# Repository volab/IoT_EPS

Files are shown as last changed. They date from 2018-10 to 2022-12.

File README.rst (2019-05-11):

==============================
Informations générales IoT_EPS
==============================

:Auteur:               Le VoLab (MajorLee, Poltergeist42)
:Site_Web:             https://www.volab.org
:Projet:               IoT_EPS
:Version:              190105
:dépôt GitHub:         https://github.com/volab/IoT_EPS.git
:documentation:        
:Licence:              CC BY-NC-SA 4.0
:Liens:                https://creativecommons.org/licenses/by-nc-sa/4.0/

####

Description
==============

IoT Electronic Power Strip : Une multiprise connectée sur laquelle chaque plot est configurable.

La connections sans fil se fait selon 2 modes possibles

- le bloc de prise est un point d'accès Wifi (mode AP)
- le bloc de prise se connecte à un réseau Wifi existant (mode Client)

Pas de mode Cloud pour le moment.

####

Arborescence du projet
========================

Pour aider à la compréhension de mon organisation,voici un bref descriptif de l'arborescence de ce projet.Cette arborescence est à reproduire si vous récupérez cedépôt depuis GitHub. ::

    ProjectDir_Name        # Dossier racine du projet (non versionner)
    |
    +--project             # (Branch master) contient l'ensemble du projet en lui même
    |  |
    |  +--_1_userDoc       # Contiens toute la documentation relative au projet
    |  |   |
    |  |   \--source       # Dossier réunissant les sources utilisées par Sphinx
    |  |
    |  +--_2_modelisation  # Contiens tous les plans et toutes les modélisations du projet
    |  |
    |  +--_3_software      # Contiens toute la partie programmation du projet
    |  |
    |  +--_4_PCB           # Contient toutes les parties des circuits imprimés (routage,
    |  |                   # Implantation, typon, fichier de perçage, etc.)
    |  |
    |  +--_5_techDoc       # Contiens toutes les documentations techniques des différents composants
    |  |                   # ou éléments qui constituent le projet. Ces éléments sont identifiés
    |  |                   # par un liens Web dans la documentation. Ce dossier n'est pas 'poussé'
    |  |                   # dans le dépôt distant (.gitignore).
    |  |
    |  +--_6_research      # Regroupe toutes les recherches relatives à l'élaboration ou au
    |  |                   # développement du projet. Ces éléments sont identifiés
    |  |                   # par un liens Web dans la documentation. Ce dossier n'est pas 'poussé'
    |  |                   # dans le dépôt distant (.gitignore).
    |  |
    |  \--_7_rushes        # Contient tous les éléments qui seront potentiellement intégrés dans la
    |                      # doc ou dans le projet. Ce dossier n'est pas 'poussé' dans le dépôt 
    |                      # distant (.gitignore).
    |
    +--webDoc              # Dossier racine de la documentation qui doit être publiée
    |  |
    |  \--html             # (Branch gh-pages) C'est dans ce dossier que Sphinx va
    |                      # générer la documentation a publié sur internet
    |
    \--trash               # Se dossier sert à retirer des éléments du projet sans les
                           # supprimé réélement. Ce dossier n'est pas pris en compte par
                           # GIT ou par GitHub

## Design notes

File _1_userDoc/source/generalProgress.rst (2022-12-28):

++++++++++++++++++++++++++++++++++++++++++++++++++++++++++++++++++++++++++++++++++++++++++++++++++++
General progress of IOT Electrical Power Strip
++++++++++++++++++++++++++++++++++++++++++++++++++++++++++++++++++++++++++++++++++++++++++++++++++++

.. include:: volabid.rst

:Date: 04/2021
:last update: 28/12/2022

.. _mainTodoList:

====================================================================================================
Task list (merged todo list hard and soft : preferred order)
====================================================================================================
Don't forget the todo list of the **doxygen documentation** and **git history**:

- To build a new plug : buy plugs

Web interface work
----------------------------------------------------------------------------------------------------
- in AP mode

- in station Mode

- A big New chapter GUI design start in 08/2022 **in progress**
    - old screen
    - new design
    - design GUI in Inkscape **OK**
    - learn REACT **OK**
    - code the GUI
        - create a simulator with node.js and express.js **in progress**

Doc
----------------------------------------------------------------------------------------------------
- Create an Visual Style Guide for documentation purpose **in progress**
    - in ``projet\_1_userDoc\visualStyleGuide221228_1549.svg``
    - retrieve source of the logo : see in ``documentation/image/logo`` **OK**

- active github pages for the project
    - upload documentation on github pages
    - create page on the volab wiki

- try other time server that provide direct time zone
    - try http://worldtimeapi.org/api/timezone/Europe/Paris in json

- Create an infographic that summarize features and needs 
    - choose tool
    - choose Size
    - choose colors
- Write user manual : **1%**
- Write builder manual
    - mechanical parts
    - buy and groups components
    - oder pcb
    - ARDUINO NANO programming
        - write where to find the precious code ! from github
        - choose ARDUINO NANO old boot, set com port and download

bugs and todos
----------------------------------------------------------------------------------------------------
- Tracking bug ``untimely switching``
    - reset all counter **OK**
    - activate red and bleu cycle and manual off on yellow and green (never switch this 2 plugs) **OK**
    - a little turn in the resolution if this bug see :ref:`update plug state in every loop<refBugUntimelySwitching>`   
    - Check after long period of time if yellow and green counter stay at 0
    - prepare only 2 220V tracker for not in used plugs ( yellow and green for example) **ABORTED**
        - it is possible to connect them outside the box directly on power plugs **ABORTED**
        - group components **ABORTED**
            - list components see :ref:`here<refDetect220VPres>` **ABORTED**
        - build it **ABORTED**
        - test it **ABORTED**
        - connect to the plugs **ABORTED**
        
    - switch to a **special software git branch** **ABORTED**
        - perhaps remove some debug messages... **ABORTED**
        - add function to read the 2 surveyed analog inputs from io expander **OK**
            - test it **OK**
        - add a new survey functionality in main loop **ABORTED**
        - if this 2 plugs switch to ON **ABORTED**
            - send on serial debug ALERT message **ABORTED**
            - display this 2 plugs states variables **ABORTED**
            - display json file content **ABORTED**
    - conduct long test
        - place the 2 unused plugs in manual off states **OK**
        - place the 2 others plugs in cycle mode **OK**
            - one with 1 mn on 2 mn off : 3mn total cycle **OK**
            - the others with 4 mn on 3 mn off : 7 mn total cycle **OK**
        - record debug serial line **OK**
        - find the right serial tool to do this job **I develop it**
    - find the cause
        - possible i2c wrong command to io expander
        - io expander bug
        - json file corruption : check json file content in the logs
        - wrong data write in json file : check plug states in th logs
    - finaly i develop a tools that check serial line in Python and with tk-inter **OK**
        - 

- treat 7 BUG From Bug_ToDoLst file
    - change time zone
    - on Web Page Hebdo mode H-fin
    - wrong global table refresh
    - cfgpage / cfgsend : configuration page (see Bug_ToDOList.rst)
    - clone pause
    - untimely switching **80%**
    - Change SSID in APmode from web page

- treat 6 TODO From Bug_ToDoLst file
    - Pause display
    - minify javascripts
    - doxy HTML js
    - file names coherence

- in wifiwebinternet.rst update Web events handlers to remove unused mode like /time /edit /list **OK**

Others task
----------------------------------------------------------------------------------------------------
- complete testToBeConduted see :ref:`here<testToBeConducted>`
    - exhaustive test of hebdo mode : **95%**
- write index special page for softAP Mode with local boostrap or other light js.framework **5%**

- Minifier all files if possible of course and reduce the size of the images
    - minifier picture
    - minifier css
    - minifier html

- try gz files

- improve json file management **2 points need work**
    - write process **OK**
        - test **ok**
            - environnement conda test **ok**
            - write python script to log boot sequence to a file: in progress ``projet\_3_software\outilPythonSpecial`` **ok**
            - record some boot sequence **ok**
            - check boots sequence **ok**
    - treat todo (error rise) 
        - regen list
        - treat one by one
    - clean the code **OK**
    - comit **ok**
    - push **ok**
    - merge **ok**
    - push **ok**

- packaging study
- integration

- continue this list ;-)

.. WARNING:: To be completed
   :class: without-title

====================================================================================================
Task done (for memory)
====================================================================================================
- cache files on web browser : see :ref:`here<webBrowserCaching>` **OK**

- before regen todo list **OK**
    - 5 parameters not documented on csystem.cpp **CORRECTED**
    - count software todo 32 NECESSARY and 11 options **OK**
        - from doxy export docboock and on web docbook to txt **OK**
    - try to ordre them **OK**
        - Excel file created **OK**
        - Check if there are all uptodate rest 22 of 32 **OK**

- doxygen gen doc pb avec **REPAIRED**::

    0044-Iot_ESP_PPlug/projet/_3_software/IoT_EPS/doc/logo_alpha2_reduced.png perdu !

- UML and classes documentation 10% - web and json **ABORTED**

- two of the 6 todo From Bug_ToDoLst file **CLOSED**
    - change behavior on fatal error **CLOSED**
        - analyze :  :ref:`see sofDev.rst<newErrorHandling2022>`
        
    - oled display error **CLOSED**

- Error handling improvement (todo display low error with LED ? Which one : power led ?)
  A lot of work : change behavior on fatal error : do not sabord system but enable debug only with serial
  - switch to special branch : newErrorHandling **OK**

New pcb
----------------------------------------------------------------------------------------------------

- print schematic from easyEda site **OK**
- edit BOM **OK**
- group components **OK**
- solder components **OK**
- Programme watch dog component
    - solder a new one on adaptator board with small pin **OK**
    - programm it with avrdude commands see :ref:`here<refWatchdogProg>` **OK**
    - test it
- use ESP, watchdog and nano from old pcb **NO**
    - reprogram attiny 85 WD **OK**
        - and test it **OK**
    - reprogram new esp8266
        - upload data **OK**
    - reprogram new arduino nano **OK**
    - test it
        - I2C acces to reg(9) of nano IO expander !
        - I2C pull-up ? Probably on DS3231 board
        - I2C scan return the right adress 0X58 ! **OK**
        - try with rtc connected **OK**
            - returned add are ok **OK**
    - write a special program to test specifically communication with the nano
        - working dir  ``\_3_software\etudeDeCode\specialPcbV2\testDirectEspNano`` **OK**
        - not versionned on git, github **OK**
        - ``testDirectEspNano.ino``
- solve the usb vs main 5v power on esp8266 **OK**
    - search and eval shottky diode solution (1N5820 has a typical vf of 0.5V its to high) SS26 Solution **OK**
    - aop and mos solution **ABORTED**
        - from the arduino model
            - list component : LM358, FDN340P, 2x 10k
            - buy or find components
                - LM358 **OK** Mouser cde **OK**
                - FDN340P : MOSFET canal P 20V 2A SOT23 cdés sur AliExp arrivée prévue **OK**
                    - store near the prototype on 13/02/2022 **OK**
                - 2x 10k ok
            - group and store components
            - prototype it **OK**
                - define the solution veroboard/pcb/cnc machining **OK**
                - solder components **OK**
                - prepare the test **OK**
                - conduct the test **OK**
            - IF it is the choosen solution add it to the schematic

- replace relais by MOSFET on general power relay to switch them all in one time on power off **OK**                                                                                              
    - choose components (irf530 and irf9530, 2x 10k resistor see personal notes public ``hardware/analog``) **OK**
        - IRF9530 : ok buy to Mouser on 21 june  **OK**
        - but no irf530 test with 2N7000  **OK**
        - 2N7000 in SOT-23 to buy from RS **OK**
            -  due to the end test and verification ther is no need but already asked from Radiospares **OK**
    - buy or find the components **OK**
        - buy 2N7000 from RS in sot23 package **OK**
    - store components in safe place : a box  **OK**
    - prototype this solution see :ref:`here<refRelayMainPowerSwitch>`  **OK**
        - cut vero board **OK**
        - solder components **OK**
        - prepare test **OK**
        - conduct the test **OK**
    - integrate the solution into the plugs **OK**
    - test it **OK**

- new pcb **OK**

    - in the schematics **OK**
        - add above solutions **OK**
            - SS26 **OK**
            - FDN30P **OK**
        - replace through hole component by cms version every time it's possible **OK**
            - Q1 to Q4 2N7000 in SOT-23 **OK**
            - R1 to R12 in R0805 **OK**
            - move R5 to R8 on hot wire to reduce pin count **OK**
            - J1 remove 6 pins **OK**
            - P5 LED remove 3 pins **OK**
        - don't forget to switch D4 and D3 on U1 **OK**
        - rtc connector reduce 2 pin **OK**
        - group wifi led and power led on same connector and place R on signal and a common gnd **OK**
  
    - On the place and route stage **OK**
        - brainstorm connector solutions: reduce the number of pins and best placement **OK**
            - no connector near the lower edge of the board (minimum distance 10mm) **OK**
            - no connector near the upper edge of the board (minimum 8mm min) **OK**
            - prefered position for connector on right edge **OK**
            - at left edge no connector and no other hight components below main switch (on a 16mm 
              place of the pcb) **OK**
            - rtc connector on upper right **OK**
            - P7 mainpowswitch connector : on left side **OK**
            - P6 special PB : on upper side **OK**
            - J1 relays commands connector : on right side **OK**
            - perhaps turn right side connector in horizontal position **NO**
            - keep ARDUINO and ESP @ same place.  **OK**
            - no hight component near the edges of the PCB **OK**
            - double check the size of the footprint of SS26 **OK**
            - check the size of the footprint of FDN340P Q5 **OK**
            - check pinout of FDN340P **OK**
            - check footprint of the 2N7002 same size as Q5 **OK**
            - One unrouted 5V on 5V Transistor corrected **OK**

    - reroute pcb to reduce the size **OK**

- test it **OK**
    - P2 : 5V power **OK**
    - Screen oled **OK**
    - DS3231 RTC **OK**
    - watch dog **OK**
    - WIFI connection **OK**
    - not tested : led and bp and relay cde... **OK**
- integrate in the plug **OK**
    - question a new plug or the old one adapted ? old not enought time for a new plug **OK**
    - make modification to pass from old pcb to new pcb **OK**
        - remove serial resistor with LED on the wire (hide by heat shrink tube)

Logo
----------------------------------------------------------------------------------------------------
- add the 3Dprinted or CNC crafted logo see :ref:`here<3dLogoDesign>`
    - design **OK**
    - print V2 logo004.stl **OK**
        - x130% in Chitubox **OK**
        - 6.18ml of resin 0h48 to print **OK**
    - paint **OK**
        - fill cavities with paint **OK**
        - scratch excess of paint **OK**
    - glue in place **OK**

====================================================================================================
General
====================================================================================================
03/12/2021: connexion to github impossible. Repaired ssh config with git hub. 
But with the help of tortoise git to configure **CORRECTED**

====================================================================================================
PCB equipment
====================================================================================================
Version 1 : Equipped and tested in may/2021

.. ATTENTION::

    Warning for test WD is not connected

Version 2: equiped on 18/04/2022

====================================================================================================
IHM
====================================================================================================
- Pierre's version : on special github branch (not allways updated in the dev)
- A minimal one from Pierre (a very old one)

.. index::
    pair: Documentation; UML
    pais Documentation; plantUML

====================================================================================================
UML story
====================================================================================================
Just to try it on webserver (dir : ``_1_userDoc\UML`` ) + Modelio (i did not find the 
workspace ! ): it is on modelio_wks_isolACauseDeGit in the project folder because of git

Juin 2021: UML the return: after the discovert of `Graphviz`_ and `plantUML`_ !!!

.. _`plantUML` : https://plantuml.com/fr/ 

.. _`Graphviz` : https://graphviz.org/ 

:download:`Doc plantUML<fichiersJoints/PlantUML_Language_Reference_Guide_fr.pdf>`

`Doc officelle Graphviz`_

.. _`Doc officelle Graphviz` : https://graphviz.org/documentation/

====================================================================================================
Hardware
====================================================================================================
See :ref:`Hardware pogress<hardProgress>`

====================================================================================================
software
====================================================================================================
See :ref:`Software progress page<devProgress>`

====================================================================================================
Weblinks
====================================================================================================

.. target-notes::

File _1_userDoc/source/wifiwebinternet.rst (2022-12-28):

++++++++++++++++++++++++++++++++++++++++++++++++++++++++++++++++++++++++++++++++++++++++++++++++++++
Wifi, Web and internet
++++++++++++++++++++++++++++++++++++++++++++++++++++++++++++++++++++++++++++++++++++++++++++++++++++

:Auteur: J.Soranzo
:Date: Ocotbre 2020
:update: 17/08/2022
:Societe: VoRoBoTics
:Entity: VoLAB

.. toctree::
    :maxdepth: 2
    :caption: Sub content
    :titlesonly:

    interface_Web

.. contents::
    :backlinks: top

====================================================================================================
Web events handlers
====================================================================================================

.. graphviz:: graphviz/webEvents.gv

----------------------------------------------------------------------------------------------------

.. index:: 
   single: Wifi modes

.. _refWifiModes:

==================
WIFI Modes
==================

In Json config file, it is configured with: "startInAPMode" value,

No WiFi
----------------------------------------------------------------------------------------------------
Also called simpleManualMode

When power on the powerStrip (by the wall plug not by the power switch), maintain push button of redPlug

Power strip start in this mode independently of Json configured mode.

4 Big color LED flash 20 times in purple.

In this very simple poor mode, powerstrip works only in manual mode with BP actions ON/OFF.

SoftAP
----------------------------------------------------------------------------------------------------
EPS starts in this mode when value of "startInAPMode" parameter is "ON".

No acces to NTP server but all other functions work.

After 20 false tries of station mode, power Strip automaticly switch in this mode

Station
----------------------------------------------------------------------------------------------------
EPS starts in this mode when value of "startInAPMode" parameter is "OFF".

The best functionnal mode ! With full web interface and others functions.

both mode STA and AP
----------------------------------------------------------------------------------------------------
July 2019 : reflexion when we start in DHCP station mode we don't know IP address of the IoT EPS.
One way to know it is to use a tool to scan the local network !
So why do not connect systematically in both mode !!!
Do it in new dev branch  !!!!!!!!!!!!!!!!!! 10 months of development to achieve this !!!!

====================================
IP address
====================================
AP and non DHCP IP address are class C address (subnet mask is 255.255.255.0 hardcoded )

.. index::
    single: Wifi LEDs

==================
WIFI LED behavior
==================
In Station mode, fast flashing (30 - parametric value in config4.json -  times 100ms, 100ms) before to try connection
and after slow flashing while waiting for connection.
(500ms with a 30 times time out - new in 24/12/2018). If no connection detected after 30 (STAmaxWifiConnectionRetry parameter) tries
Automatically switch in SoftAP mode.

In Access Point LED FLash quickly (20 times 100ms-500ms) and 
led flash slowly (50ms-2s) while waiting for connection.

Cause WiFi.softAPConfig function is a blocking function. This is wrong : 
test on 24/12/2018 softAP is non blocking !

So - in summary - if power led is on and WIFI Led flash (50ms-2s) WIFI wait for connection in AP mode. 

It rises a new problem : in this state it is not possible to use plugs even in simple  manual mode 
with push button. 

Possible solution : check push button at startup if a particular combination is pressed,
plugs do not try to connect to wifi and work in simple manual mode.
In Dec 2018, push button
added pressing plug 0 while power on the strip cause no WIFI mode (color LED FLASH in RED to confirm)
This is : simpleManualMode (see above). To return to normal mode power off the strip 
(not by the power on/off button but by removing the strip from the wall plug)

===========================================
ESP8266 and its wifi management !
===========================================
ESP8266 store credentials information in FLASH but how to access to them ???
And how to control them

Question how to erase wifi flash param ?

Memory mapping is not provided. Some peace of informations
like in SPIFFS description that provide the order of memory big blocks but not their respective address.

Second question : how to directly access to flash memory ?

Perhaps with SPI lib 

https://github.com/esp8266/Arduino/blob/master/doc/libraries.rst#spi

Answer :

- ESP.flashRead(...)https://github.com/esp8266/Arduino/blob/master/cores/esp8266/Esp.h
- ESP.flashWrite(..)
- ESP.flashEraseSector(...)
- ESP.eraseConfig() Erase all from start of the flash till -0x4000 about 16k
- no-documented function !

ESP-SDK ? nothing fond about erase

persistant(false) <=> do not write in flash but do not clear informations

Question 3: How to read  flash info  ?

Answer : call Espressif SDK functions::

    #include <user_interface.h> in
    Arduino\Croquis\hardware\esp8266com\esp8266\tools\sdk\include
    page 62/179 pdf ESP8266 Non-OS SDK API Reference 
    3.5.33. wifi_softap_get_config_default

.. code::

    struct softap_config {
        uint8 ssid[32];
        uint8 password[64];
        uint8 ssid_len;	// Note: Recommend to set it according to your ssid
        uint8 channel;	// Note: support 1 ~ 13
        AUTH_MODE authmode;	// Note: Don't support AUTH_WEP in softAP mode.
        uint8 ssid_hidden;	// Note: default 0
        uint8 max_connection;	// Note: default 4, max 4
        uint16 beacon_interval;	// Note: support 100 ~ 60000 ms, default 100
    };

ESP12E module Flash size : W25Q32 32Mbits/4Mo 256octets /pages 16384 pages

Could be erase by 16 ou 128 ou 256 -4(sectors)- or 32kB or even 64kB groups.

====================================================================================================
ESP8266Webserver
====================================================================================================
Documentation very hard to find

`In github readme`_

.. _`In github readme` : https://github.com/esp8266/Arduino/tree/master/libraries/ESP8266WebServer

Don't forget to `check the provided examples`_

.. _`check the provided examples` : https://github.com/esp8266/Arduino/tree/master/libraries/ESP8266WebServer/examples

`ESP8266Webserver Doxygen documentation`_  do not wast your time !

.. _`ESP8266Webserver Doxygen documentation` : https://links2004.github.io/Arduino/d3/d58/class_e_s_p8266_web_server.html

We can `find this on Arduino`_  forum::

    As for the ESP8266WiFi documentation, it is here::
    The on() function is actually part of the ESP8266WebServer library. Most of the library 
    documentation for the ESP8266 core for Arduino is found here:
    https://arduino-esp8266.readthedocs.io/en/latest/index.html
    but for some reason the ESP8266WebServer library documentation is missing from those pages. 
    You can find it here:
    https://github.com/esp8266/Arduino/blob/master/libraries/ESP8266WebServer/README.rst

    https://arduino-esp8266.readthedocs.io/en/latest/esp8266wifi/readme.html
    Generally the ESP8266 libraries attempt to follow the API of the standard Arduino libraries 
    and only document the differences. You may find it useful to refer to the Arduino WiFi library 
    reference pages in addition to the ESP8266WiFi documentation:
    https://www.arduino.cc/en/Reference/WiFi

.. _`find this on Arduino` : https://forum.arduino.cc/index.php?topic=588866.0

`Arduino ESP8266 example readthedoc`_

.. _`Arduino ESP8266 example readthedoc` : https://arduino-esp8266.readthedocs.io/en/latest/esp8266wifi/server-examples.html

Bind to a method 
----------------------------------------------------------------------------------------------------

`Explication sur Stackoverflow`_

.. _`Explication sur Stackoverflow` : https://stackoverflow.com/questions/32900314/esp8266webserver-setting-a-value-inside-a-class

===========================
WEB page development
===========================

HTML5 et css and bootstrap
jquery, jquery ui, ajax and popper

bootstrap from its CDN
https://www.bootstrapcdn.com/

.. index::
    single: Html Request

html requests
----------------------------------------------------------------------------------------------------

ipaddr/plugonoff?plug=redPlug...

192.168.1.42/plugonoff?COLOR=redPlug&Mode=Manuel&State=ON

Possible plugonoff requests:

- Mode=Manuel&State=ON&dureeOff=299 : dureeOff on minutes only
- Mode=Manuel&State=ON&dureeOff=299:59 : dureeOff on minutes and seconds
- Mode=Manuel&State=ON&hFin=23:59 : hFin only one format HH:MM
- Mode=Manuel&State=OFF
- Mode=Manuel&State=ON

Other request:

- /time **obsolète**
- /list **obsolète**
- /edit **obsolète**
- /cfgpage
- /cfgsen?lots of parameter...
- /ChangeCred?ssid=xxxx&pass=yyyy&softApSsid=ssidOfSoftApMode&softApPass=123456789

NTP server name
----------------------------------------------------------------------------------------------------
The name reside in the IoT_EPS.h file and is not a config param through web config page

It is : "fr.pool.ntp.org" on ``#define NTPSERVER`` macro

====================================================================================================
Serveur html ESP8266
====================================================================================================
Copy from example provided in ARDUINO IDE : ESP8266WebServer/FSBrowser

This example provide a lot of functions that managed file sending as css, jpg and so on

edit page
----------------------------------------------------------------------------------------------------
Strange behavior with html extension

Le bouton parcourir tronc en htm et le visualisateur ne montre que les fichier htm

Edit.htm source code ? not provided in the .ino file

One possible source (but not really the same) :

https://github.com/gmag11/FSBrowser/blob/master/data/edit.html

====================================================================================================
HTML IHM integration
====================================================================================================
Start on March 2019

Used technologies:

- HTML5/css
- Javascipt
- JQuery
- Boostrap

Test list:

For all plugs

- manual ON/OFF :  OK on RED
- manual ON with OFF time : ok on RED
- manual ON with delay : ok on RED 1 minutes
- timer : RED plug ko, state no transmit: corrected ok
- timer red switched by bp : OK
- clone from green cyclic to bleu : ok

... see testAndErrorHandling.xlsx file for the rest of the tests

bugs found :

- manual hfin and dureeOff without parameter should be KO
- manual cleanup buton dont remove hfin and others param
- no default state in manual mode : corrected
- minuterie (timer mode) no default value for the ratio immediat start or differed start - corrected
- bug in ESP source side effect of main power switch  ?

improvements:
- add tips on main page : To refresh this page press F5

====================================================================================================
HTML rework in 2022
====================================================================================================
2 problèmes :

- AP mode
- Station mode

html extension vs htm : preference of Pierre just for esthetic reason

SPIFFS total bytes : 2949250 : 2.8Mo
SPIFFS used bytes : 317515 310ko

Reduce image (red.png, green.png...) size 124x124 to win 80ko

minify index.html win 30ko

Bootstrap size : `primaryobjects/css-comparison.csv`_

.. _`primaryobjects/css-comparison.csv` : https://gist.github.com/primaryobjects/64a4e7e3351c646f51eee07949215ad4

Inventory before running
----------------------------------------------------------------------------------------------------
- bootstrap.css
- jquery-3.3.1.js
- jquery-ui.js
- font awesome :solid.js, fontawesome.js
- popper.min.js
- bootstrap.min.js

List of files before work::

    /apmodeindex.htm / 1303
    /config.htm / 3405
    /config_tag.htm / 3279
    /credentials.json / 170
    /css/apmode.css / 1074
    /css/sidebar.css / 2021
    /css/style.css / 3738
    /defConfig.json / 1407
    /edit.htm / 7890
    /firstboot.htm / 5384
    /firstboot.html / 5289
    /helloWorld.htm / 1275
    /help.htm / 1246
    /help.html / 0
    /img/align_justify.svg / 701
    /img/blue.png / 12473
    /img/green.png / 27773
    /img/logo_alpha.png / 32887
    /img/red.png / 28171
    /img/yellow.png / 30460
    /index.html / 48741
    /index.html.minify / 16109
    /js/main.js / 13904
    /js/myLog.js / 712
    /js/plug.js / 18959
    /js/regExPatern.js / 8724
    /js/table.js / 8425
    /newcred.htm / 1380
    /page2.htm / 12531
    /volab.ico / 198
    /config4copie2.json / 1408
    /config4.json / 1419
    /config4copie1.json / 1419
    SPIFFS total bytes : 2949250
    SPIFFS used bytes : 317515
    SPIFFS max open files : 5
    SPIFFS max path lenght : 32

gzipped files
----------------------------------------------------------------------------------------------------
gzipper : `Free Online Converter Convert to GZIP`_

.. _`Free Online Converter Convert to GZIP` : https://online-converting.com/archives/convert-to-gzip/

- plug.js.gz
- help.htm.gz
- index.html.gz

CDN files
----------------------------------------------------------------------------------------------------
HTML pages use Boostrap CDN associate with js files

Liste of used files:

- ``stackpath.bootstrapcdn.com/bootstrap/4.2.1/css/bootstrap.min.css``
- ``code.jquery.com/jquery-3.3.1.js``
- ``code.jquery.com/ui/1.12.1/jquery-ui.js``
- ``use.fontawesome.com/releases/v5.0.13/js/solid.js``
- ``use.fontawesome.com/releases/v5.0.13/js/fontawesome.js``
- ``cdnjs.cloudflare.com/ajax/libs/popper.js/1.14.6/umd/popper.min.js``
- ``stackpath.bootstrapcdn.com/bootstrap/4.2.1/js/bootstrap.min.js``

Local replacement file and size:

- css/bootstrap.min.css 150ko
- js/jquery-3.3.1.min.js 85ko
- js/jquery-ui.1.12.1.min.js 248ko
- js/solid.5.0.13.js 343ko
- js/fontawesome.5.0.13.js 27ko
- js/popper.1.14.6.min.js 22ko
- js/bootstrap.4.2.1.min.js 56ko

jquery, jquery.ui
----------------------------------------------------------------------------------------------------

popper
----------------------------------------------------------------------------------------------------

bootstrap.js
----------------------------------------------------------------------------------------------------

Special js files
----------------------------------------------------------------------------------------------------
- main.js
- myLog.js
- plug.js
- regExPatern.js
- table.js

====================================================================================================
What is wrong with this first (Pierre) version of the IHM
====================================================================================================
one page html page : adapted if we use a js framework like react ou vu.js (Pierre's answer)

pseudo responsive design

color and general page design

I wonder if a js framework is very necessary.

====================================================================================================
A learn phase
====================================================================================================

A learn phase start now for me : study courses...

- Traversy media Boostrap4 `Twitter Bootstrap play list`_

.. _`Twitter Bootstrap play list` : https://www.youtube.com/playlist?list=PLillGF-RfqbZ7b9ytQhLqLvWO2Q_3Ph7S

And after vuejs on Traversy or on Udemy

First study : `Développement d’interfaces Web : les Frameworks JS à connaître`_

.. _`Développement d’interfaces Web : les Frameworks JS à connaître` : https://blog-ux.com/les-frameworks-js-a-connaitre/

and

`[TUTO] Vue JS : les bases en 35 minutes !`_ on youtube chanel : La Tech avec Bertrand

.. _`[TUTO] Vue JS : les bases en 35 minutes !` : https://www.youtube.com/watch?v=D3oivlcoEvw&t=32s

`Tutoriel VueJS : Vue.js 3.2`_ on Grafikart.fr yt chan

.. _`Tutoriel VueJS : Vue.js 3.2` : https://www.youtube.com/watch?v=TWE6NVVPNcc

[Projet Vue JS] `Créer une interface utilisateur avec Vuejs`_ on "From Scratch - Le développement Web de zéro"

.. _`Créer une interface utilisateur avec Vuejs` : https://www.youtube.com/watch?v=siy9ETx68NU

====================================================================================================
Weblinks
====================================================================================================

.. target-notes::

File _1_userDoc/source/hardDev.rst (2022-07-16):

+++++++++++++++++++++++++++++++++++++++++++++++++++++++++++++++++
Hardware development documentation
+++++++++++++++++++++++++++++++++++++++++++++++++++++++++++++++++

:Auteur: J.Soranzo
:Date: Octobre 2018
:update: 08/12/2021
:version: git versionning

.. contents:: Table of Contents
    :backlinks: top

.. toctree::
   :maxdepth: 2
   :caption: Contents
   :titlesonly:

   mockup

.. |clearer|  raw:: html

====================================================================================================
In 2021 find on the net
====================================================================================================

TPlink

`MEROSS`_ 26€

.. _`MEROSS` : https://www.amazon.fr/Multiprise-HTbrightly-puissance3680W-Protection-surtensions/dp/B08T1DNG2R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

WECONN

AISIRER 

HORSKY

**KONYKS** sur AMAZON moins de 20€ et même une `prise multiple Polyco`_ moins de 60€ chez Boulanger,
AMAZON, Darty...

.. _`prise multiple Polyco` : https://www.apynov.com/konyks-polyco

.. index::
    single: TP-LINK HS110

====================================================================================================
Test of TP-Link HS110 plug with curent measurment capability
====================================================================================================
Usage of `TP-LINK HS110`_

.. _`TP-LINK HS110` : https://www.tp-link.com/en/home-networking/smart-plug/hs110/

First of all, we need to install a smartphone application KASA. What about to drive the plug directly
from a Windows, Mac or Linux computer. The plug is compatible with Alexa and IFTTT.
Above is true but with the help of Softscheck and their blog article : `Reverse Engineering the TP-Link HS110`_

.. _`Reverse Engineering the TP-Link HS110` : https://www.softscheck.com/en/reverse-engineering-tp-link-hs110/

We can do a lot of thing ! Great job and thanks to them !

The application need to connect to your wifi network and more surprisingly active your location !

You also need to creat a login on their internt site. Just to drive one simple plug !!!

Clearly it's not a product for an hobbyist. It is not open source at all

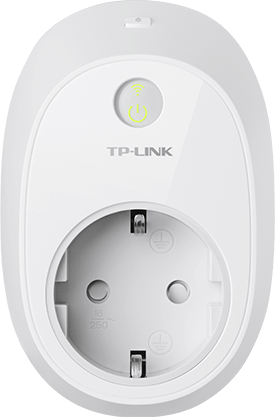
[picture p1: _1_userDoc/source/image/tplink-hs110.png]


    TP-LINK HS110 

|clearer|

====================================================================================================
Et avec un Raspberry pi ?
====================================================================================================

La question se pose sérieusement avec le pi zero W (W pour Wifi) sur KuBii, il est à 10.44€ ttc

Contre environ 2.5€ pour un Wemos D1 mini

.. _hardProgress:

============
Progres
============

Terminated
----------------------------------------------------------------------------------------------------

::

#. alimentation ESP/Wemos en 5V ? : **OK**
#. horloge temps réelle : **OK**
#. bouton poussoirs : **OK**
#. Affectation des io : **OK**
#. module relais : **OK**
#. définition des modes de fonctionnement : **OK**
#. récup paramètre via form submit html : **OK**
#. add  WS2801 LED : **OK**
#. add power led **OK**
#. add power button : **OK** 
#. add wifi led : **OK**
#. add LDR : **removed**
#. add I2C nano expander with analog inputs **OK**
#. change BP to nano I2C and relay command to ESP directly (to allow turnoff relays in fatal error) **OK**
#. resolv power up problem : implement MAX1232 [ as an option onto the PCB ] **discarded**
#. implement an I2C watch dog component [ as an option onto the PCB ] **OK**
#. choix curent sensor: 75% - **discarded** in the first version
#. pcb study **OK**
#. OLED screen intefgartion **OK**
#. 5V relais board power supply  (choix du conver.) : **OK**

In progress
----------------------------------------------------------------------------------------------------

Transferred to :ref:`main todo list<mainTodoList>`

####

.. _3dLogoDesign:

====================================================================================================
3D printed Logo Design
====================================================================================================
On Inkscape

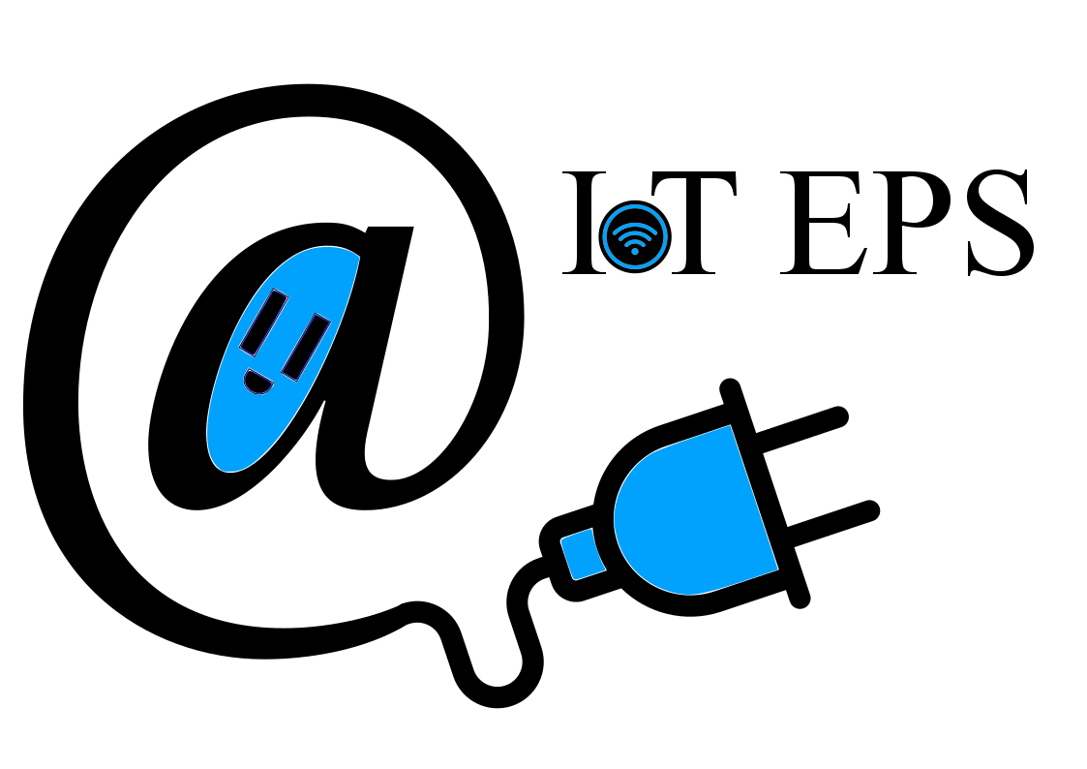
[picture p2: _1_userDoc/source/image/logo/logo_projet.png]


Final width goal : 32mm 

Some notes:

in Inskape choose right dimension and place on 0.0 0.0

In Freecad : 

#. separate the design in multiple svg files
#. direct in root of the new doc import svg
#. in part (not partdesign) union of the imported splines
#. in draft from curve to sketch
#. in part protusion

A lots of try with multiple comme and go between Freecad and Inkscape !

====================================================================================================
PCB bug BP2 and 3
====================================================================================================

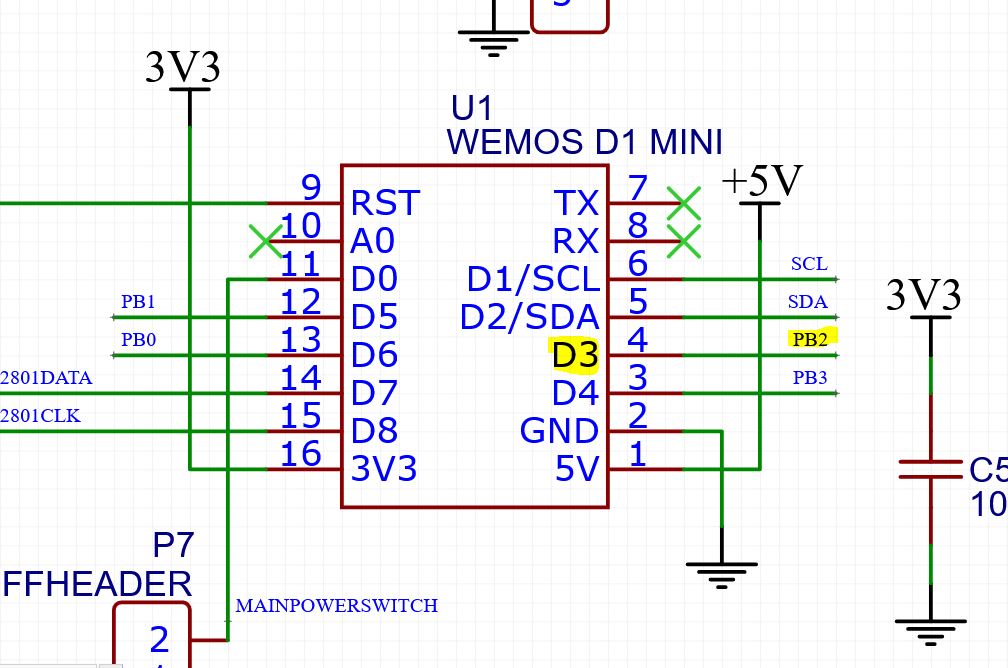
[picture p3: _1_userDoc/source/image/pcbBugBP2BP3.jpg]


BP2 should be on D4 and BP3 on D3 see `Input / output assignment`_

.. WARNING:: Waiting for the new version of the pcb, I switch the 2 wires on H1 female connector
   :class: without-title

.. _refRelayMainPowerSwitch:

====================================================================================================
Relais main power switching
====================================================================================================

IRF9530



|clearer|



.. list-table::
   :widths: 27 27 
   :header-rows: 1

   * - IRF9530 pinout
     - Package

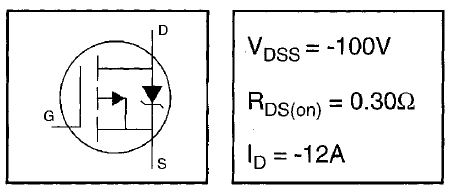
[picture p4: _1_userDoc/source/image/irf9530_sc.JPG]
   * - 
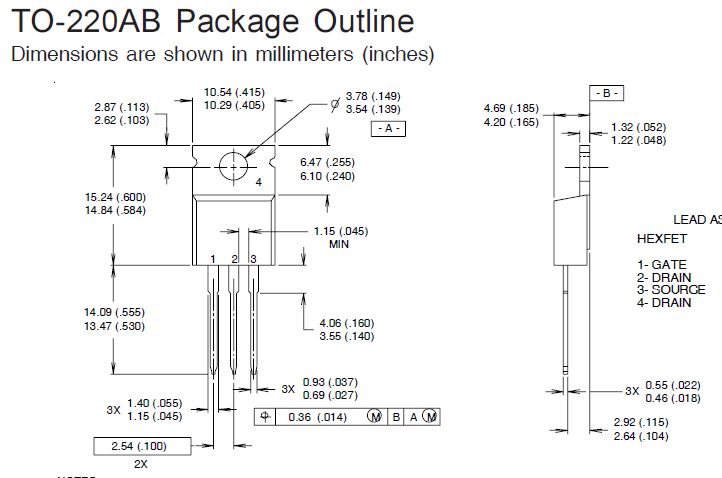
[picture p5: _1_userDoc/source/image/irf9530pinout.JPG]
     - 

|clearer|

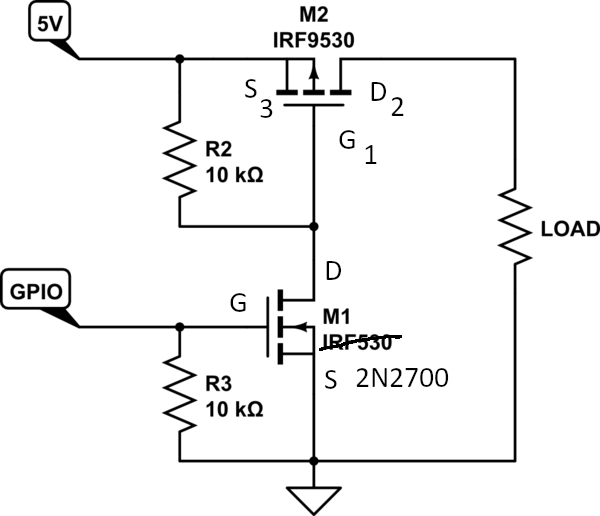
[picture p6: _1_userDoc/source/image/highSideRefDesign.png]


    High side switching 

2N7000 : N-CHANEL MOS_FET Exist in SOT-23 package ref 2N7002 :download:`datasheet<fichiersJoints/2N7002.pdf>`

Radiospares code : 671-0312 (0.30€/pcs by 20pcs)

.. WARNING:: Commande RS du 12/3/2022 7082399 this is the only reference that it was available in 50pcs.
   :class: without-title

.. WARNING:: Litige TNT

    file recorded on 26/3 : n° 8693043

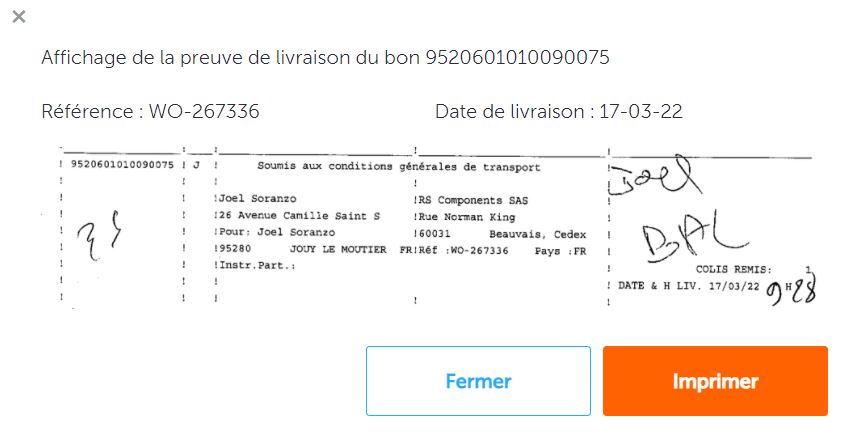
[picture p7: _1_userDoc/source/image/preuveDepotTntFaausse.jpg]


    false prouf of deposit 



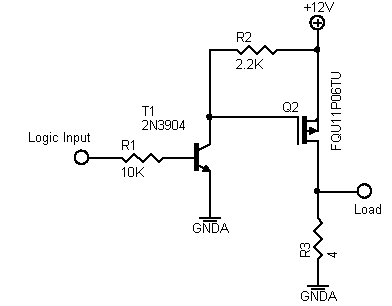
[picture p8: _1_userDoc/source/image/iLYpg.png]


    Another one 

IRF9530 is too big replace it by a FDN340P in SOT-23 package 20V 2A

FDN340 pinout :download:`datasheet<fichiersJoints/FDN340P-1007907.pdf>`

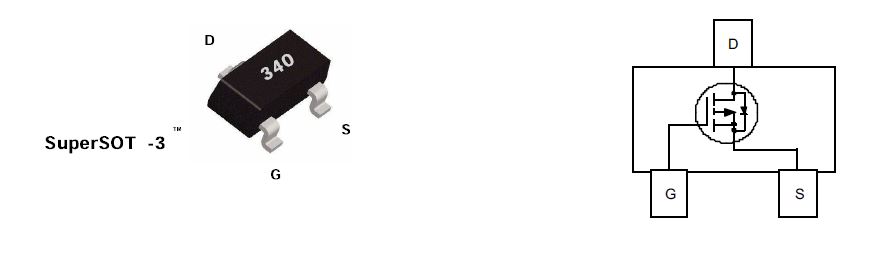
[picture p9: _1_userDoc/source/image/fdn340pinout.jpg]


Main relais switch conclusion
----------------------------------------------------------------------------------------------------
::

    Due to the direct main switch connection, there is no need of 2N7000 ! FDN340P is directly connected
    to the main switch

====================================================================================================
USB 5V switching
====================================================================================================
Solution with mosfet
----------------------------------------------------------------------------------------------------

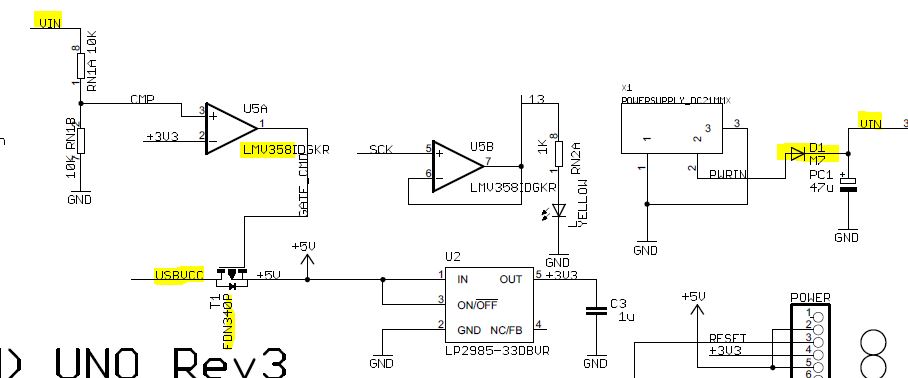
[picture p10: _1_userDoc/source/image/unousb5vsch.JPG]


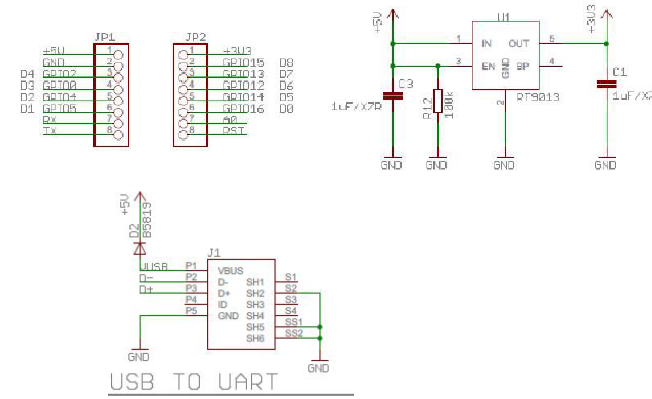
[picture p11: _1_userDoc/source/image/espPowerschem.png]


    ESP WEMOS D1 MINI power supply schem 

**Above solution aborted**.

With a Schotky diode
----------------------------------------------------------------------------------------------------

Schotky diode : B5817W 0.45V @ 1A

A possible power supply will be a 5.5V `AC/DC converter from ebay like this one`_

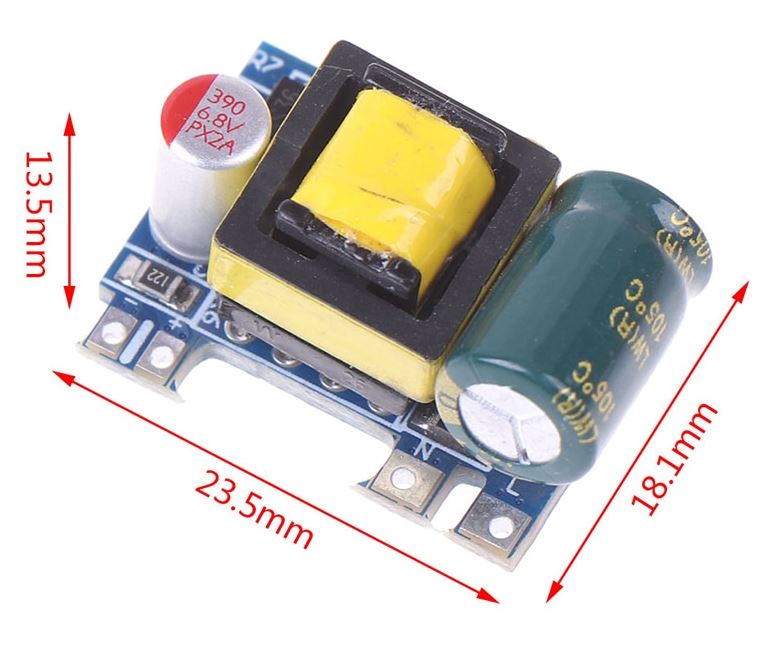
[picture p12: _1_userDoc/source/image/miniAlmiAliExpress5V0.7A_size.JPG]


.. _`AC/DC converter from ebay like this one` : https://www.ebay.com/itm/263722458020

With this solution one schottky iss necessary for each line of powered : one for esp, one for Arduino
Nano and not for attiny wathdog (it can work correctly up to 5.5V) 

An another candidate: SS26

SS26 tested Vd = 0.3V I=90mA with 1 channel actif.

:download:`SS26 datasheet<fichiersJoints/ss22_26_datasheet.pdf>`

ESP 5V = 
mesured before diode 4.17V after 3.85v delta 0.32V

Strange why 4.17V juste à AD/DC output there is 4.97V i forget the diode !!!!

New measurement : at AC/DC converter : 4.97V,  at ESP5V input : 4.62V delta u : 0.35V

with a 5.5V AC/DC will be output : 5.15V

.. NOTE:: For ESP8266 it is no matter the real level of the 5V input because of the 3.3V embedded regulator
   :class: without-title

.. index::
    single: Watchdog; Présentation

====================
Watchdog function
====================
During multiple tests, i noticed that watch dog functionnality of the ESP8266 may fail to reset 
the component. But perhaps only when connected to usb port. **So i must made more tests.**

What are others solutions for watchdog

RTC DS3231 has a INT output but we can only set to 1 / second or 1/minutes. And it is a pour
solution to control this component to use itself !

MAX1232 has a watch dog feature but with a maximum of 1.2s and direct at startup activated.
It can't be activate after setup for example. And if we use it, we need to drive its ST pin
but all our outputs are used !

Use a I2C watchdog component as DS1371. If using this component we need to implement
a 32kHz oscillator ! `DS1374U-3+`_ (power sup 3V) or -33+ reference suffix in 3.3V available on MOUSER site for 3€23
Don't forget to buy oscillator : `32k quatz chez Mouser`_ 0.68€ !

Warning U denote a uSOP package with à 0.5mm pitch!

Perhaps DS1374 could replace MAX1232 but its VPF level is very low about 2.3V regardless of the
4.6V of the MAX1232.

`Arduino library for DS1374 here`_

An other possibility would be the usage of our NANOI2CIOExpander but watch dog function 
is not already implemented on the library (perhaps a future function).

a DS1307 or 1302 similar to DS3231 SQW/out only 1Hz

.. _`DS1374U-3+` : https://www.mouser.fr/ProductDetail/Maxim-Integrated/DS1374U-33%2b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
.. _`32k quatz chez Mouser` : https://www.mouser.fr/ProductDetail/Citizen-FineDevice/CFV-20632000AZFB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
.. _`Arduino library for DS1374 here` : https://github.com/SpellFoundry/DS1374RTC

An other idea : use an Attiny85 as an I2C watch dog component. Library already exists ! 
`ATTiny85 I2C watchdog experiment`_ Wonderful ! But no documentation is provided except the code 
comments

.. _`ATTiny85 I2C watchdog experiment` : https://github.com/letscontrolit/ESPEasySlaves

ATtiny85 watchdog
----------------------------------------------------------------------------------------------------
After some tests, I decided to use it.

I build a ATtiny programmer with a ARDUINO UNO and a `proto shield`_ from Banggood

A little watching on the `Heliox' Youtube video`_ and it was enough to start !

So i decided for this time to stop  MAX1232 integration.

The only changes that i made in the code of the ATtiny85 watchdog are :
 - Settings.TimeOut          = 20;
 - Settings.Sleep            = 20;

An other change : I was obliged to move files in TinyWireS_Custom directory to one upper level !
 
This design works perfectly ! but what is the user license of this code ? Perhaps GNU Public 2.1

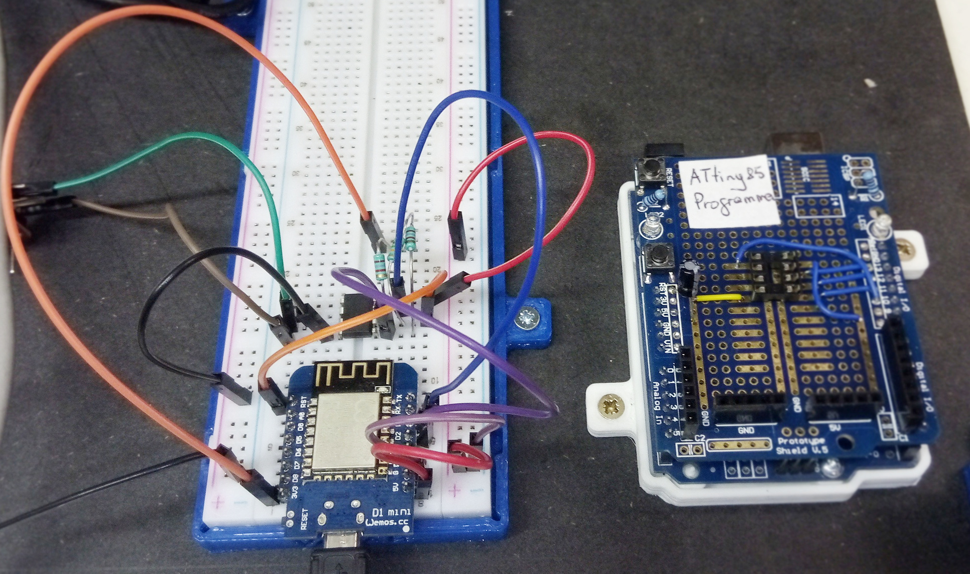
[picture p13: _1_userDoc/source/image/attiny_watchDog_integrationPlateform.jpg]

    
    ATtiny85 I2C watchdog hardware test environment

The only missing in this design is an ESP user library. So I write it !    

Power ATtiny with 3.3V and don't forget pullup on D3 and on reset (15k) ATTiny85 support 5V or 3.3V
power supplies

.. _`proto shield` : https://www.banggood.com/Arduino-Compatible-328-ProtoShield-Prototype-Expansion-Board-p-926451.html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

.. _`Heliox' Youtube video` : https://www.youtube.com/watch?v=S-oBujsoe-Q&t=247s

**Pinout**

::

    // ATMEL ATTINY85 PINOUTS used for watchdog purpose
    //                          o-\/-+ 
    //                  Reset  1|    |8  VCC 
    //      Factory Reset Pin  2|    |7  I2C-SCL to ESP
    //      (debug) Serial TX  3|    |6  Reset output to ESP
    //                    GND  4|    |5  I2C-SDA to ESP
    //                          +----+ 

ATTiny85 programming tips
----------------------------------------------------------------------------------------------------
Don't forget to choose clock 1MHz for ATTiny when programming with ARDOUINO UNO as IoT_EPS
This is not specify in the documentation

14/11/2021 : try the best result was internal clock 1MHz : times1s give 1s but com speed always 1200
not 9600

ATiny85 watchdog test tips
----------------------------------------------------------------------------------------------------
There is a TX debug serial on pin 3  speed is en théorie 1200 but on my maquette 9600 !!!

facteur 8 => fuse atiny85 ???? 11/11/2021 NO I test the 3 speed 1, 8 and 16MHz and the com speed is 
always 1200 bauds !!!!

The name of the project of the Atiny code is ESPEasySlaves.

Only for my eyes the code sits in ::

    0044-Iot_ESP_PPlug\projet\_3_software\etudeDeCode (not pushed in github).

.. index::
    single: Watchdog; Problème

ATTiny watchdog expertise
----------------------------------------------------------------------------------------------------
Date: 20/11/2021: I can't reproduce watchdog component with the data that I have.

On the maquette there is an ATTiny programmed. It run perfectly @ 9600 bauds on debug COM.

But when I program a new component with the design that site on my hard drive, I can't obtain a 
functional one.

The ATtiny programmed work @1200bds when I set 1MHz for ATTiny in ARDUINO IDE

I decide to conduct more test en check the size of the bit on serial. Short explain: in the design
there is a special lib for serial that it is more lower than the official one but manually tuned.

First test : with the functional one (the master) check on oscillo the serial bit duration.

Bit size 102us (putty @9600 bd works perfectly)

Test program with  8MHz as cpu clock in ADUINO IDE : Serial comm is at 1200 bauds but timer1s is about 6s duration !

Test @ 1MHz : rs 1200 timer1s = 1s

**ATTiny hex dump**

With what tools ? Visual Atmel, AVRdude

- Atmel Studio 

- avrdude : in ``C:\Program Files (x86)\Arduino\hardware\tools\avr\bin``

Probe::

    AVRMKII
    USBasp

Video ressource : `#002|English - avrdude, USBasp, Atmel Studio, Arduino IDE, fuses, lockbits, hex, ...`_

.. _`#002|English - avrdude, USBasp, Atmel Studio, Arduino IDE, fuses, lockbits, hex, ...` : https://www.youtube.com/watch?v=lxUmaW9M4EI

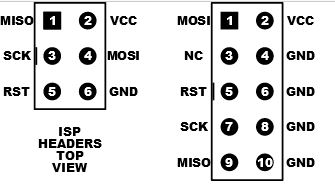
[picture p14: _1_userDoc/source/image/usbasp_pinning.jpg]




Command avrdude::

    avrdude -c usbasp -p t85 -t : enter terminal mode
    avrdude -c usbasp -p t85 -U flash:r:m128_read.hex:i

http://undindoncurieux.blogspot.com/2015/12/charger-un-driver-usbasp-sur-windows-10.html

Micro task:

- install driver usbasp_pinning : necessary ? nothing in  "Le journal de manip" **OK**
- wire it on a breadboard
- read wrong component **OK**
    - read hex file composant **OK**
    - read fuses **OK**
- read the right component **OK**

**avrdude and its conf file on E:\avrdude** !!!! Otherwise it reports errors:: 

    avrdude: can't open config file "": Invalid argument
    avrdude: error reading system wide configuration file ""

avrdude command send by Arduino IDE to the ARDUINO as ISP::

    avrdude -v -pattiny85 -cstk500v1 -PCOM12 -b19200 -Uflash:r:TinyI2CWatchdog_nonFonctionnel.hex:i

Above commands are cleaned of the fullpath

First diff right component Lfuse = E2 and wrong one Lfuse = 62 meaning that the right comp is clocked at 8Mhz

After a lot of time spend on this expertise **I decide to stop it without solution** !

I keep binary files from the right component as a master to program others components !

.. index::
    single: Watchdog; Program from bin files

.. _refWatchdogProg:

Program Attiny85 from binary files
----------------------------------------------------------------------------------------------------
Use ARDUINO as ISP as in the Heliox video see her above. The wiring diagram is a 2:11 in the video.

And after this preparation, we can program component directly with avrdude in command line.
Without ARDUINO IDE. There is only one constraint: the avrdude.conf file need to resid in the same
directory than our .hex master file.

read fuse with avrdude::

    avrdude -v -pattiny85 -cstk500v1 -PCOM16 -b19200 -U lfuse:r:-:i

    -U <memtype>:r|w|v:<filename>[:format]
                                Memory operation specification.
                                Multiple -U options are allowed, each request
                                is performed in the order specified.

    v for verification
    memtype : lfuse, efuse, hfuse, signature, flash, eeprom
    format: i for intel hex there is a lots of other formats

https://www.nongnu.org/avrdude/user-manual/avrdude_3.html#Option-Descriptions

above commnd produce::

    avrdude: Version 6.3-20171130
            Copyright (c) 2000-2005 Brian Dean, http://www.bdmicro.com/
            Copyright (c) 2007-2014 Joerg Wunsch

            System wide configuration file is "C:\Users\jojo\Documents\jojoBag\perso\0044-Iot_ESP_PPlug\projet\_3_software\ESPEasySlaves\avrdude.conf"

            Using Port                    : COM16
            Using Programmer              : stk500v1
            Overriding Baud Rate          : 19200
            AVR Part                      : ATtiny85
            Chip Erase delay              : 400000 us
            PAGEL                         : P00
            BS2                           : P00
            RESET disposition             : possible i/o
            RETRY pulse                   : SCK
            serial program mode           : yes
            parallel program mode         : yes
            Timeout                       : 200
            StabDelay                     : 100
            CmdexeDelay                   : 25
            SyncLoops                     : 32
            ByteDelay                     : 0
            PollIndex                     : 3
            PollValue                     : 0x53
            Memory Detail                 :

                                    Block Poll               Page                       Polled
            Memory Type Mode Delay Size  Indx Paged  Size   Size #Pages MinW  MaxW   ReadBack
            ----------- ---- ----- ----- ---- ------ ------ ---- ------ ----- ----- ---------
            eeprom        65    12     4    0 no        512    4      0  4000  4500 0xff 0xff
            flash         65     6    32    0 yes      8192   64    128 30000 30000 0xff 0xff
            signature      0     0     0    0 no          3    0      0     0     0 0x00 0x00
            lock           0     0     0    0 no          1    0      0  9000  9000 0x00 0x00
            lfuse          0     0     0    0 no          1    0      0  9000  9000 0x00 0x00
            hfuse          0     0     0    0 no          1    0      0  9000  9000 0x00 0x00
            efuse          0     0     0    0 no          1    0      0  9000  9000 0x00 0x00
            calibration    0     0     0    0 no          1    0      0     0     0 0x00 0x00

            Programmer Type : STK500
            Description     : Atmel STK500 Version 1.x firmware
            Hardware Version: 2
            Firmware Version: 1.18
            Topcard         : Unknown
            Vtarget         : 0.0 V
            Varef           : 0.0 V
            Oscillator      : Off
            SCK period      : 0.1 us

    avrdude: AVR device initialized and ready to accept instructions

    Reading | ################################################## | 100% 0.04s

    avrdude: Device signature = 0x1e930b (probably t85)
    avrdude: safemode: lfuse reads as E2
    avrdude: safemode: hfuse reads as DF
    avrdude: safemode: efuse reads as FF
    avrdude: reading lfuse memory:

    Reading | ################################################## | 100% 0.01s

    avrdude: writing output file "<stdout>"
    :01000000E21D
    :00000001FF

    avrdude: safemode: lfuse reads as E2
    avrdude: safemode: hfuse reads as DF
    avrdude: safemode: efuse reads as FF
    avrdude: safemode: Fuses OK (E:FF, H:DF, L:E2)

    avrdude done.  Thank you.

Fuse for a clean component::

    avrdude: safemode: lfuse reads as 62
    avrdude: safemode: hfuse reads as DF
    avrdude: safemode: efuse reads as FF
    avrdude: safemode: Fuses OK (E:FF, H:DF, L:62)

For right comp::

    avrdude: safemode: lfuse reads as E2
    avrdude: safemode: hfuse reads as DF
    avrdude: safemode: efuse reads as FF
    avrdude: safemode: Fuses OK (E:FF, H:DF, L:E2)

Command to write lfuse::

    avrdude -v -pattiny85 -cstk500v1 -PCOM16 -b19200 -U lfuse:w:0xE2:m
    note m format as ``immediate mode; actual byte values specified on the command line``

Command to write binary file::

    avrdude -v -pattiny85 -cstk500v1 -PCOM7 -b19200 -U flash:w:TinyI2CWatchdog_rightComponent211127_2223.hex:i   

----------------------------------------------------------------------------------------------------

MAX1232 integration (aborted)
----------------------------------------------------------------------------------------------------

MAX1232 is a uP supervisor. It features bp and watchdog

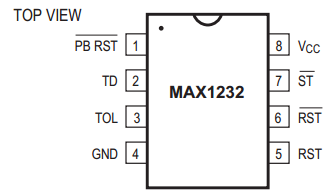
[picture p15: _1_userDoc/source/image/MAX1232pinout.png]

    
    MAX1232 pinout

Very simple : connect VCC, GND and RST/ to RST pin of the 8266 !

Add a pullup on RST/. Also pullup TOL pin 3 (tolerance 10%), pin 7 WD input and pin 1 PBRST/

Warning MAW1232 check power supply in 5V+/-5% ie 4.75 to 5.25V

Aborted because : timeout settings of 150ms, 600ms, or 1.2s (to short for us)

====================================
Direct relay connection to ESP pins
====================================
On a first stage, relays were connected to nano and Push Button were directly connected to ESP8266.
The purpose is to connect relays to ESP8266 and push button to nano.

Cause when there is an error on I2C bus relay commands are no accessibles and we can't switch 
it off with main power switch.

List of change:
 - IoT_EPS.h Pinning
 - void bouton::begin( int boutonPin ) : pinMode(boutonPin, INPUT_PULLUP); _nano.pinMode
 - void bouton::update() : large changes digitalRead to _nano.digitalRead (group in one line)
 - bool bouton::directRead() => one _nano.digitalRead.
 - void CPowerPlug::begin : one line     _nano.pinMode( _pin, OUTPUT ); to normal pinMode 
 - void CPowerPlug::updateOutputs : one line to change
 
A failure (work branch : relayChange) because some of the ESP8266 pins have others usages that are
not compatibles with relay command. Specaly D3 and D4 respectively IO-0 and IO-2 that are used 
during the reset and that changes state. So we leave this work on its branche and return to the previous
configuration with relay commands connected to the NanoI2CIOExpander.

Others solutions to solve our problem:

#. use a WEmos ESP32 with more IO (perhaps we can remove NanoI2CIOExpander...)
#. use another relay or a transitor MOS to switch off the 5V Power supply of the relay commands.
   This new relay would be drive directly by the Main Power Switch

Problem solved with the second solution.

============================
AC power plug in the world 
============================

It's incredible !

See in `wikipedia power plug`_

and in French : `prises secteur sur wikipedia`_

.. _`wikipedia power plug` : https://en.wikipedia.org/wiki/AC_power_plugs_and_sockets

.. _`prises secteur sur wikipedia` : https://fr.wikipedia.org/wiki/Prise_%C3%A9lectrique#Plusieurs_normes_diff%C3%A9rentes

####

.. index::
    single: Power supply

==================   
ESP power 
==================
First question: can we power ESP8266 with 5V external power  ?

Answer : yes

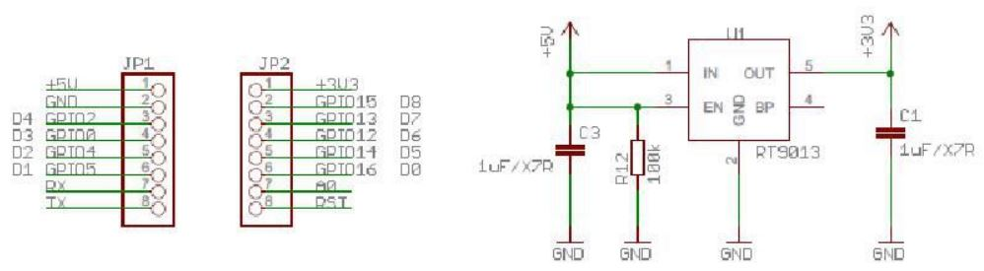
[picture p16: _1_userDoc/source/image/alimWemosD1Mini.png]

    
    Power schematic of WEMOS D1 mini

Can we power ESP with external 5V and USB at the same time ?

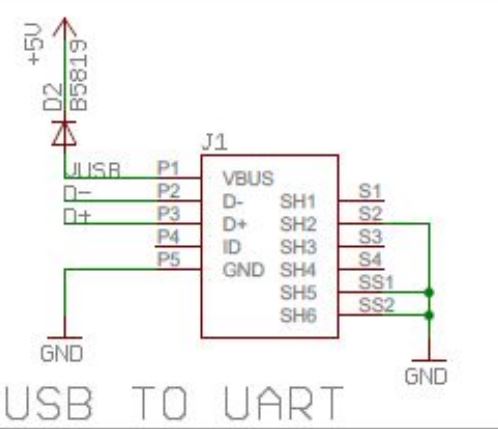
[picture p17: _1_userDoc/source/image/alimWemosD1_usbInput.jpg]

    
    Power schematic of WEMOS D1 mini USB input

The USB input is protected by a diode, ok

But our external power is not. All +5V are connected together so USB will power all the board and
relays. It is not very good. We should put a diode between 5V of ESP and the rest of the board.
In this way, external power could power ESP but +5V power from ESP could not power the rest of the
plug.

And what about 3.3V ? It come from ESP regulator to power few I2C components like:

- RTC
- Tiny85 who could work with 5v but to drive ESP input it is better to power ATiny with 3.3v

####

================================
ESP8266 power up problem
================================
When I power Wemos by external 5V, the system don't start correctly.

Apparently it stay locked in an unknow state for about 6 seconds and finaly it start.

I suspect a watch dog time out.

I try to put à 47uF on reset. With oscilloscope I watch the signal and I thinks that the slew rate
is to low.

I consider to add a MAX1232 on the reset pin or an analog circuit.

I checked IO0 (D3) used to flash the component is connect to BP3

At the begin of the setup I add a delay during this delay i drive the built-in LED for 1s 
and it solves the problem ! Very strange behavior !

==========================
Real time calendar clock
==========================

Adding of a DS3231 as in the project : `ESP_NTP_DS3231 <https://github.com/volab/ESP_NTP_DS3231>`_

.. important::

  D1 : SCL
  D2 : SDA
  
I2C pullup ? There is pull up on DS3231 ! Yes I checked it 4.7k

Power consumption : 1.9mA measured 08/03/19

####

=======================
Current sensor choice
=======================

Great youtube video on this subject from Andreas Spiess (the guy with the swiss accent)

`#245 Deep-Sleep Current: Which is better? µCurrent or CurrentRanger? (ESP32, ESP8266)`_

.. _`#245 Deep-Sleep Current: Which is better? µCurrent or CurrentRanger? (ESP32, ESP8266)` : https://www.youtube.com/watch?v=HmXfyLyN38c

`#321 7 Sensors tested: Measuring Current with Microcontrollers (Arduino, ESP32, ESP8266)`_

.. _`#321 7 Sensors tested: Measuring Current with Microcontrollers (Arduino, ESP32, ESP8266)` : https://www.youtube.com/watch?v=cG8moaufmQs

INA219 et INA220 : NOT KEPT : bus voltage to low
----------------------------------------------------------------------------------------------------

- impossible "bus voltage 0-26V"

ACS712 : ANALOG OUTPUT
----------------------------------------------------------------------------------------------------

- "Output voltage proportional to AC or DC currents"

- "2.1 kVRMS minimum isolation voltage from pins 1-4 to pins 5-8"

- "5V power supply"

pb it is not I2C compnent and more we need 4

3 version exist -05 -20 -30 for 5A, 20A, 30A.

On Banggood there are :
  - `Banggood ACS712 5A version`_
  - `Banggood ACS712 30A version`_
  - `20A version on AliExpress`_
  
  20A version output a 100mV/A

.. _`Banggood ACS712 5A version`: https://www.banggood.com/ACS712TELC-05B-5A-Module-Current-Sensor-Module-For-Arduino-p-74020.html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
.. _`Banggood ACS712 30A version` : https://www.banggood.com/1PC-30A-New-Range-Current-Sensor-Module-for-ACS712-p-86583.html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
.. _`20A version on AliExpress` : https://fr.aliexpress.com/item/32315336227.html

.. NOTE::
    5A version is  a rail to rail value +/-5A but we need to mesure RMS value 5A/sqr(2) = 3.53A.
    With a 20A value it means that we have 14.14A with 100mV/A factor it risk to be very low
    mesurement for small curent values. for exemple: for a 100mA we need to mesure 10mV.

ACS764 : NOT KEPT : DC
----------------------------------------------------------------------------------------------------
I can't find rail to rail max  voltage

- I2C
- max courant  programmable
- but Unidirectional DC current sensing and reporting : KO

Internet search
----------------------------------------------------------------------------------------------------

"AC isolated current sensor I2C"

The winer (not in 2019 !) is `Si8901B-GS`_

.. _`Si8901B-GS` : https://www.silabs.com/products/isolation/current-sensors/si890x-isolated-adc-ac-mains-monitor

dispo on `Mouser`_ à 3.44€/10pcs

.. WARNING::

    It requires a 3.3V power supply referenced to Neutral line ! (see fig16 page 24 in its datasheet)

.. _`Mouser` : https://www.mouser.fr/Search/Refine.aspx?Keyword=SI8901 

`Usage example`_ of an HLW8012. Open source example

.. _`Usage example` : http://tinkerman.cat/the-espurna-board-a-smart-wall-switch-with-power-monitoring/#lightbox-gallery-oY6vOUw7/3/

Finaly, now that we have on board NANOI2CIOExpander that provide 6 analog inputs we can use ACS712.

.. warning::

    For me, most of breakout boards provide on internet have an isolation issue. The ground plane comes very close to AC terminal (less than 1 mm)

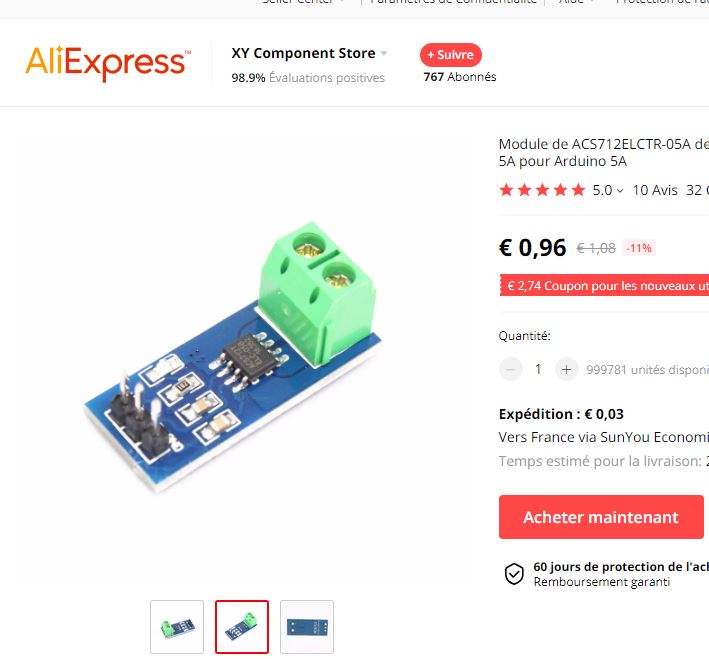
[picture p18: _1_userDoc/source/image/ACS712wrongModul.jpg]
alternate text

   
   ACS712 wrong breakout board 

Specialy those with mounting holes. Its is mode revelant from back side:

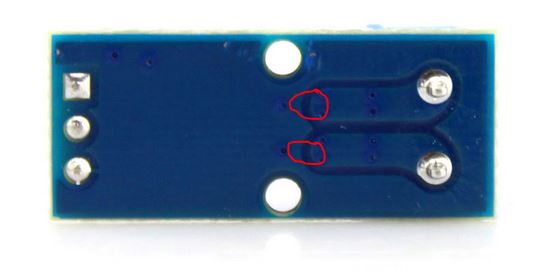
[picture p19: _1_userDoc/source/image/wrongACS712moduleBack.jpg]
ACS712 wrong breakout board back side

   
   ACS712 wrong breakout board back side      

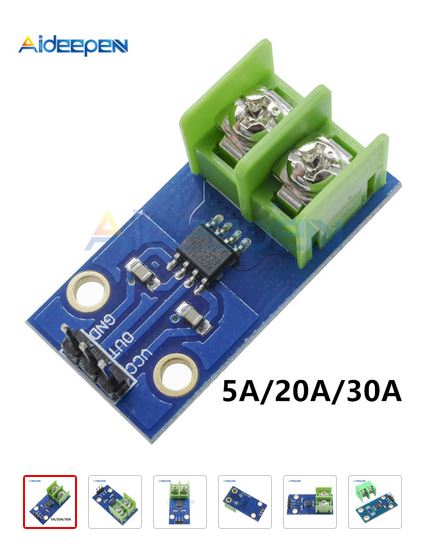
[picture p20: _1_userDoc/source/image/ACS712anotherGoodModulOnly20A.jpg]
ACS712 a good breakout board

   
   ACS712 a good breakout board
     
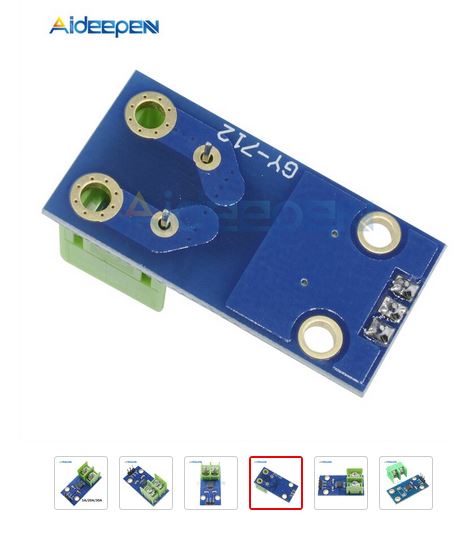
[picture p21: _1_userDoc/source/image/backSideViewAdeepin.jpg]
ACS712 a good breakout board back

   
   ACS712 a good breakout board back

More connector are bigest than on the other modules and they arive not solder. There is 2 big holes 
on pcb to connect directly large wires for 30A curent. the size oh this holes is about 2.9mm.

`aliExpress good module provided in 5A grade`_ or `another one`_

.. _`aliExpress good module provided in 5A grade` :  https://fr.aliexpress.com/item/4000114853244.html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,searchweb201602_1,searchweb201603_52   

.. _`another one` : https://fr.aliexpress.com/item/32649182582.html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,searchweb201602_1,searchweb201603_52   

First test with ACS712
----------------------------------------------------------------------------------------------------
With my new received ACS712 5A breakout board, i made a first test with oscilloscope, multimeter
and a motor as a charge ( with the drill press of the lab).

Multimeter measure 0.793A

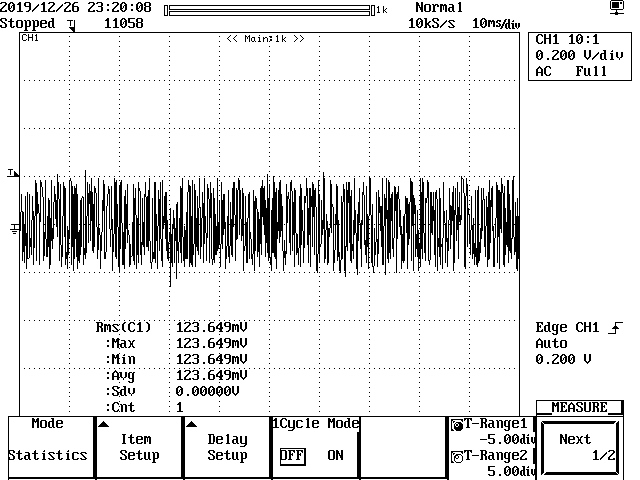
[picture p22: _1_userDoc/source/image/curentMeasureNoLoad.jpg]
Curent measurment without load

   
   Curent measurment without load

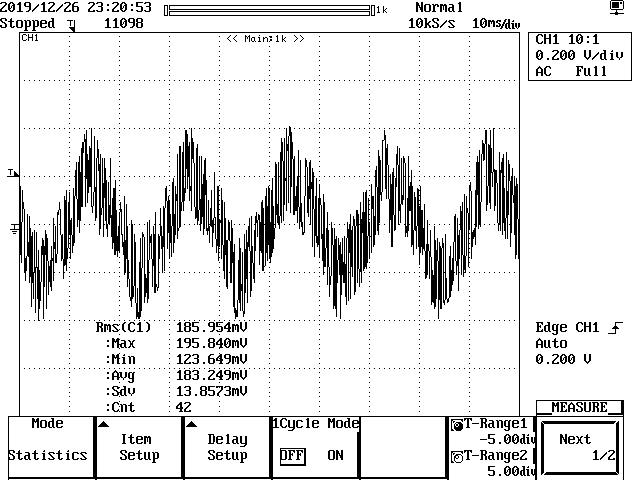
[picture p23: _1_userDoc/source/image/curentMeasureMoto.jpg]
Curent measurment with motor

   
   Curent measurment with motor

185mV/A we can see that the measurment will be not very precise and very noisy !

For 5A it give 5x185 = 925mV above and under 2.5V

New ASC723 : to try
----------------------------------------------------------------------------------------------------
Replacement part for ACS712 find on the Allegro web site

"The Allegro™ ACS723 current sensor IC is an economical and
precise solution for AC or DC current sensing in industrial,
commercial, and communications systems." from datasheet.

But... It is not very widespread. It is available only on SPARKFUN and distribute by MOUSER

`SPARKFUN`_ provide 2 breakoutboard. On one there is a smal AOP for `low current version`_.

`at MOUSER`_

I find an another problème : the price 4.65€ an we need 4 ! Tips : breakout board for ACS712 should be compatible !

The component alone is available `on Radiospares site`_.

But an improuvment is the sensitivity for +/-5A version we pass from 185mV/A for ACS712 to 400mV/A.

An other improvment there is a +/-10A version ACS723LLCTR-10AB-T but it is very expensive 
5.81€ with VAT regarless of the ASC712.

.. _`SPARKFUN` : https://www.sparkfun.com/products/13679

.. _`low current version` : https://www.sparkfun.com/products/14544

.. _`at MOUSER` : https://www.mouser.fr/ProductDetail/SparkFun/SEN-13679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 

.. _`on Radiospares site` : https://fr.rs-online.com/web/p/capteurs-de-courant/8660760/

TMCS1100 from ti : NOT KEPT : no breakoutboard t test it
----------------------------------------------------------------------------------------------------

No breakout board on the net !

ACS70331

.. current sensing aborted:

Current Sensing Aborted
----------------------------------------------------------------------------------------------------
For now, we abort the idea of sensing the curent in each chanel of the IoT EPS because we can't find
a good solution that match the main criteria:

- ability to measure low and high current from 0.01A to 10A True RMS on AC240V suply without neutral
  reference.

So we decide to continue the rest of the project without this feature but we keep it in mind.

For remembering, current measurment covers 2  needs:

#. check if the 2 relais on one channel have switched correctly
#. provide power consumption informations to the user

For the first one we can measure voltage with a module like this :

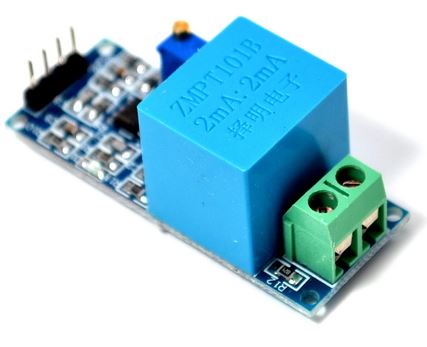
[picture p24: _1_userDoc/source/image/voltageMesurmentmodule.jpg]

   
See `Module AC on AliExpress`_ with voltage lower transformer

.. _`Module AC on AliExpress` : https://fr.aliexpress.com/item/32816455579.html

This solution is more easy to implement even at the end of the project because voltage measurement 
are made in parallel and there is only one value to measure prensence of the 240V.

An other way to do ti is to use SFH6206 as on `Electrical Engineering forum`_ but this solution
requires interrupt pin that we don't have here ! We have only analog pin on the ARDUINO nano !

.. _`Electrical Engineering forum` : https://electronics.stackexchange.com/questions/17008/how-can-i-detect-a-power-outage-with-a-microcontroller

MAX71020A a new hope 
----------------------------------------------------------------------------------------------------
In february 2020, I find a new component to measure AC curent circuit spécialisé sur bus SPI.

Pb seems to be obsolescence in a near future... Dommage 4.11€ `at Mouser.com`_

Replace part on Maxim's site ? 78M6613 reference sold to SILERGIE ? obso Stok 0 on Mouser

A very short time new hope :-(

.. _`at Mouser.com` : https://www.mouser.fr/ProductDetail/Maxim-Integrated/MAX71020AETI%2b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

MCP3911
----------------------------------------------------------------------------------------------------
In Linky !

 1€64 @MOUSER

Shunt mesurment

----------------------------------------------------------------------------------------------------

.. index::
    pair: Hardware; Relay choice

=======================
Relay board choice
=======================

Coupure des 2 voies en même temps (phase et neutre) donc soit des relais 2 voies soit 8 relais.

Nous avons retenu l'option 8 relais car plus disponible dans l'écosphére ARDUINO.

The real need is a DPST relay but its very difficlut to find more with a 5V cmd and not with 
a breakout board form. A possible solution would be to make our own relays pcb.

Disponible entre autres chez `Banggood 8 Channel Module Module Relais`_ 

.. _`Banggood 8 Channel Module Module Relais` : https://www.banggood.com/fr/5Pcs-5V-8-Channel-Relay-Module-Board-For-Arduino-PIC-AVR-DSP-ARM-p-968931.html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


    
    Photo module relais 8 voies de chez Banggod
    
Le gros soucis avec ces modules c'est que les relais sont actif par défaut.

On pourrait utiliser le contact repos, mais il y a un petit risque d'avoir une micro alimentation
des équipements derrière la prise pendant quelques milisecondes.

Solution : inversé le signal de commande avec 4 2N7000 à 0.24€ chez RS particulier

la bobine est données pour 70ohm sous 5V soit I environ 75mA * 8 = 571mA

Nous avons mesuré 156mA pour 2 relais ce qui donnerais 624mA pour les 8 soit un convertisseur 
AC/DC capable de délivrer 3.2W

Livetime of the relays
----------------------------------------------------------------------------------------------------
 10^7 time 

===================================
Livetime of ESP8266 flash SPIFFS
===================================
hypothesis :
- 4 plugs that work in clycle mode 1 minutes on and 1 minutes off
- 4 plugs not synchronyzed
With this hyp. the 4write/minutes 

WEMOS D1 Flash is Ai ESP12-F module W25Q32 pour 32Mbits soit 4Mo
100k erase/write cycle

25k minutes = 416 hours = 17 days

But it is a very hard hypothesis

A great question : what is the realistic usage ?

- one On/off cycle by hour on each plug every days only 12 hours by days
  25k hours /12 <=> 2083 days <=> more than 5 years

----------------------------------------------------------------------------------------------------

.. index:: Pining, IO connections

==========================================
Input / output assignment 
==========================================


    
    Wemos D1 Mini pinout

.. table:: IO Assignment
    :align: center
    
    ===== =============  =====================
    pins  Assignment     ESP-GPIO
    ===== =============  =====================
    D0    Main Power sw  IO16
    D1    I2C SCL        IO5
    D2    I2C data       IO4
    D3    BP3            IO0 - Warning PU10k
    D4    BP2            IO2 - PU10k
    D5    BP1            IO14
    D6    BP0            IO12
    D7    DATA WS2801    IO13           
    D8    CLK WS2801     IO15 - PD10k    
    ===== =============  =====================

.. index:: Nano I2C IO Expander, I2C IO Expender

- GPIO16: pin is high at BOOT
- GPIO0: boot failure if pulled LOW
- GPIO2: pin is high on BOOT, boot failure if pulled LOW
- GPIO15: boot failure if pulled HIGH
- GPIO3: pin is high at BOOT
- GPIO1: pin is high at BOOT, boot failure if pulled LOW
- GPIO10: pin is high at BOOT
- GPIO9: pin is high at BOOT

Source : sur `RandomeredTutorial ESP8266 pinout`_

.. _`RandomeredTutorial ESP8266 pinout` : https://randomnerdtutorials.com/esp8266-pinout-reference-gpios/

----------------------------------------------------------------------------------------------------

.. _nanoI2CIoExpander:

.. index::
    pair: Hardware; IO Expander

===========================
nanoI2CIOExpander
===========================
To solve digital I/O and analog I decide to use an ARDUINO nano as I2C slave. I belived that someone
like ADAFRUIT or SPARFUN has build a lib to use an ARDUINO Nano as `I2C I/O expander`_.

To my surprise, nobody does it ! So I wrote it and I provide it on `HACKSTER IO`_

.. _`I2C I/O expander` : https://www.hackster.io/MajorLeeDuVoLAB/nano-i2c-io-expander-3e76fc

.. _`HACKSTER IO` :  https://www.hackster.io/MajorLeeDuVoLAB/nano-i2c-io-expander-3e76fc

Nano pining :

.. table:: ARDUINO Nano I2C I/O Expander pins assignment
    :align: center
    
    ===== ======= =============
    pins   Name    affectation
    ===== ======= =============
    D2       0     PLUG0-ROUGE
    D3       1     PLUG1-VERT
    D4       2     PLUG2-BLEUE
    D5             PLUG3-JAUNE
    D6             LED0
    D7             LED1
    D8             LED2
    D9       7     LED3
    D10      8     WIFI LED 
    D11      9     MAIN POWER LED
    D12      10    Special BP
    A0            PLUG0 Current
    A1            PLUG1 Current
    A2             PLUG2 Current
    A3             PLUG3 Current
    A6    
    A7
    ===== ======= =============

####

==========================================
BOM (obsolete 10/06/2021)
==========================================

- Carte 8 relais banggood 4.57
- 4 BP 0.2€ = 0.8€
- 1 ESP8266 WEMOD D1 mini : 2.81€
- 1 NANO V3 2.28€
- 4 Prises 1.9€ = 7.6€
- morceau de goulotte

Sous Total = 18.06€

- 4 mesure de courant 7.27€ = 29.08€

Total = 47.14

- 4 ACS712 isolated 3.99€ `sur aliexpresse`_

.. _`sur aliexpresse` : https://fr.aliexpress.com/item/ACS714-5A-20A-30A-5-v-Isoler-Capteur-De-Courant-Carte-de-D-rivation-Filtre-R/32865669250.html

- Autre ACS712 mieux isolé `toujours sur aliexpress`_ par 10pcs 2.62€/pcs fdp compris soit 4x2.62 = 10.48

.. _`toujours sur aliexpress` : https://fr.aliexpress.com/item/20A-Range-ACS712-Current-Sensor-Module-AC-Current-Sensor-DC-Hall-Current-Sensor-module-for-Arduino/32649182582.html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,searchweb201602_5_10065_10068_319_5735015_10892_317_5734915_10696_10924_453_10084_454_10083_10618_10920_10921_10304_10922_10307_10820_10821_537_10302_536_5730115_10843_10059_10884_10887_100031_5735215_321_322_10103_5729115_5735115_10930,searchweb201603_51,ppcSwitch_0_ppcChannel&algo_expid=5ef8197b-2bdc-48f7-8a9b-d8edf6a406b9-11&algo_pvid=5ef8197b-2bdc-48f7-8a9b-d8edf6a406b9

 ce qui nous amènerait à 28.54€
 
- +4 led rouge d3mm
- +1 current fault
- +5 résistance 330ohm
- +4 LED neopixel `diam 8mm sur aliexpress`_ 4x0.23€
- +1 HLK-PM01 AC/DC 220V/5V seulement 3W soit 0.6A 3.03€ (un peu juste voir § `Relay board choice`_ )
- Fuse et porte fuse
- DS3231 avec batterie
- 4 x `2N7000 chez RS PArticulers`_

.. _`2N7000 chez RS PArticulers` : https://www.rs-particuliers.com/Search.aspx?Terms=671-4733&Page=0

.. _`diam 8mm sur aliexpress` : https://fr.aliexpress.com/item/20pcs-14mm-8mm-F8-DC5V-WS2801-2801-IC-diffused-RGB-LED-for-Pixel-LED-Module-Light/1966017933.html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!

5V power supply

https://www.banggood.com/5pcs-AC-DC-5V-2A-10W-Switching-Power-Bare-Board-Stabilivolt-Power-Module-AC-100-240V-To-DC-5V-p-1190175.html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

5pcs 6.03€

https://www.banggood.com/AC-DC-5V-2A-Switching-Power-Supply-Board-Low-Ripple-Power-Supply-Board-10W-Switching-Module-p-1337342.html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

3€26 /pcs

https://www.banggood.com/220V-to-5V-5W-AC-DC-Isolation-Switch-Power-Supply-Module-p-1420417.html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

3€23 seulement 1A mais à souder sur CI

====================
Useful Documentation
====================

Examples 

SONOF POW on `CNX software`_

SONOF POW on `the SONOF site`_

`The ESPurna board`_ : very interresting !

`Smart Switch Having 6 Outputs & 5 Inputs`_ : 

`How can I detect a power outage with a microcontroller?`_ 

.. _`The ESPurna board` : https://tinkerman.cat/post/the-espurna-board-a-smart-wall-switch-with-power-monitoring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

.. _`CNX software` : https://www.cnx-software.com/2017/04/09/espurna-h-is-a-compact-open-source-hardware-board-with-esp8266-wisoc-a-10a-relay-hlw8012-power-monitoring-chip/

.. _`the SONOF site` : https://sonoff.itead.cc/en/products/sonoff/sonoff-pow

.. _`Smart Switch Having 6 Outputs & 5 Inputs` : https://www.hackster.io/ashish_8284/smart-switch-having-6-outputs-5-inputs-91fc29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

.. _`How can I detect a power outage with a microcontroller?` : https://electronics.stackexchange.com/questions/17008/how-can-i-detect-a-power-outage-with-a-microcontroller

====================================================================================================
PCB dev
====================================================================================================
Tools : `EasyEDA.com`_

.. _`EasyEDA.com` : https://easyeda.com/editor#id=69115a0a3c0e4fc9a7f6cf54611fa6d4|2b73c76a246e4b2a8ebcf58152a8890c

:download:`Schéma<../../_4_PCB/easyeda/Schematic_IoT Electrical Power Strip_Sheet_1_20200208225752.pdf>`

2 versions of the PCB :

RED one and Blue one lol

modification to pass from old pcb to new pcb (v2):

    - PBHEADER : no change (perhaps PB2 PB2 switched)
    - ONOFF HEADER : **no change**
    - SPECIAL BP : **no change**
    - I2C HEADER : **no change**
    - RTC HEADER : *no change*
    - 4COLOR LED HEADER : *no change* 
    - WIFI AND POW LED : groupe on the same connector
        - 1 = is Wifi, 2 power led and 3 GND **OK**
    - red LEDHEADER : from 8 to 5 **OK**
        - pin are in the same order 1 to 1, 3 to 2, 5 to 3, 7 to 4 and 8 to 5 **OK**
        - remove résistors directly connected to the leds in front panel ! **OK**
    - change relay connector from 10 pin to 6 **OK**
        - 1 to 1, 2 to 2, 4 to 3, 6 to 4, 8 to 5, 10 to 6 (GND) **OK**

.. _refDetect220VPres:

====================================================================================================
Easy check 220V presence
====================================================================================================

With a SFH6206 see `How can I detect a power outage with a microcontroller?`_

This technique générate an high to low when ac cross the zero. 

An other possibility mentionned in this article will be MID400.

I have SFH620A-2. :download:`datasheet of the component<fichiersJoints/sfh620a.pdf>`

Protection resistor calculations:

If = +/-60mA Vf = 1.25V

Collector curent : 50mA

Check Resistor power dissipation

Check Resitor breakdown voltage

=============
Weblinks
=============

.. target-notes::

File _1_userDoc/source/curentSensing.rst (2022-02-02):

.. index::
    pair: Software; Curent sensing

++++++++++++++++++++++++++++++++
IOT EPS curent Sensing
++++++++++++++++++++++++++++++++

.. contents:: 
    :backlinks: top

For sensor choice see hardware documentation.

Curent Sensing aborted for now  :doc:`see hardware documentation  <hardDev>`

.. WARNING::
    Current sensing was aborted due to sensor choice

AC mesurement
----------------------------------------------------------------------------------------------------
`Module AC on AliExpress`_ with voltage lower transformer

Usage example on `Youtube chanel of SurtrTech`_

Fortunately, the guy made a site! `SurtrTech`_

`Librairie filtre pour les calculs RMS`_ on ARDUINO absolutly not documented !

No documentation for this library of `Jonathan Driscoll`_

But luckily among the 40 forks a user wrote a doc, `Edgar Bonet`_

It is more of a presentation than actual documentation.

.. _`Module AC on AliExpress` : https://fr.aliexpress.com/item/32816455579.html

.. _`Youtube chanel of SurtrTech` : https://www.youtube.com/watch?v=WVcY108AAAw

.. _`SurtrTech` : https://surtrtech.com/2019/01/21/easy-measure-of-ac-voltage-using-arduino-and-zmpt101b/

.. _`Librairie filtre pour les calculs RMS` : https://github.com/JonHub/Filters

.. _`Jonathan Driscoll` : https://github.com/JonHub

.. _`Edgar Bonet` : https://github.com/edgar-bonet

================================
Première mesure
================================

.. code:: cpp

    #define RSSPEED 115200

    void setup(){
        Serial.begin( RSSPEED );
        //Serial.println( "Sketch start...");
    }

    void loop(){
        Serial.println( analogRead(A0) );
    }

To check if all is right !



================================================================
Example of usage of the library filtre.h
================================================================

.. code:: cpp

    /* This code works with ACS712 current sensor, it permits the calculation of the signal TRMS
     * Visit www.surtrtech.com for more details
     */

    #include <Filters.h>                      //This library does a massive work check it's .cpp file

    #define ACS_Pin A0                        //Sensor data pin on A0 analog input

    float ACS_Value;                              //Here we keep the raw data valuess
    float testFrequency = 50;                    // test signal frequency (Hz)
    float windowLength = 40.0/testFrequency;     // how long to average the signal, for statistist

    float intercept = 0; // to be adjusted based on calibration testing
    float slope = 0.0752; // to be adjusted based on calibration testing
                          //Please check the ACS712 Tutorial video by SurtrTech to see how to get them because it depends on your sensor, or look below

    float Amps_TRMS; // estimated actual current in amps

    unsigned long printPeriod = 1000; // in milliseconds
    // Track time in milliseconds since last reading 
    unsigned long previousMillis = 0;

    void setup() {
      Serial.begin( 9600 );    // Start the serial port
      pinMode(ACS_Pin,INPUT);  //Define the pin mode
    }

    void loop() {
      RunningStatistics inputStats;                 // create statistics to look at the raw test signal
      inputStats.setWindowSecs( windowLength );     //Set the window length
       
      while( true ) {   
        ACS_Value = analogRead(ACS_Pin);  // read the analog in value:
        inputStats.input(ACS_Value);  // log to Stats function
            
        if((unsigned long)(millis() - previousMillis) >= printPeriod) { //every second we do the calculation
          previousMillis = millis();   // update time
          
          Amps_TRMS = intercept + slope * inputStats.sigma();

          Serial.print( "\t Amps: " ); 
          Serial.print( Amps_TRMS );

        }
      }
    }

    /* About the slope and intercept
     * First you need to know that all the TRMS calucations are done by functions from the library, it's the "inputStats.sigma()" value
     * At first you can display that "inputStats.sigma()" as your TRMS value, then try to measure using it when the input is 0.00A
     * If the measured value is 0 like I got you can keep the intercept as 0, otherwise you'll need to add or substract to make that value equal to 0
     * In other words " remove the offset"
     * Then turn on the power to a known value, for example use a bulb or a led that ou know its power and you already know your voltage, so a little math you'll get the theoritical amps
     * you divide that theory value by the measured value and here you got the slope, now place them or modify them
     */

End

================================
How it is possible ?
================================

On Wikipedia, we learn that the standard deviation (sigma) is equivalent to RMS value. And filter
library has an statisitc modul that provide sigma !

See `Root mean square definition on Wikipedia`_

.. _`Root mean square definition on Wikipedia` : https://en.wikipedia.org/wiki/Root_mean_square

====================================================================================================
Possible components
====================================================================================================

================================
Weblinks
================================

.. target-notes::

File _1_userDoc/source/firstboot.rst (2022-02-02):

++++++++++++++++++++++++++++++++++++++++++++++++++++++++++++++++++++++++++++++++++++++++++++++++++++
First boot informations
++++++++++++++++++++++++++++++++++++++++++++++++++++++++++++++++++++++++++++++++++++++++++++++++++++

:Auteur: J.Soranzo
:Date: Octobre 2020
:Societe: VoRoBoTics
:Entity: VoLAB

.. contents::
    :backlinks: top

.. index::
    single: First boot

====================================
First boot configuration
====================================

@first boot :
 - mode AP connection and display config page to set SSID password and server name
 - softAP ssid <32
 - WARNING pass in AP mode >8 <63
 - propose a unic ID for server name to the user
 - explain that it will possible to change after

Restaure factory parameters 
----------------------------------------------------------------------------------------------------
firstBoot after check box in config page.

Restaure defConfig.json

What are hypothesis, when boot for the first time ?
----------------------------------------------------------------------------------------------------
Is a config json exist ? What is inside it ? Yes and it contain FirstBoot ON and other stuff.

Same questions with credentials ? No, we generate it

We consider that the user upload sketch and data directory.

When consider the first boot is OFF (end of first boot procedure) ? 
When we receive the following form:

 - station mode or AP choice
 - SSID et pass du mode AP (WARNING provide diff SSID if you own more then one PowerStrip)
 - SSID and pass of station mode [ optional if user wish stay always in AP mode ]
 - propose default same hostname and default SSID AP build with mac add:
   IOT_EPS_HHHH

First boot process
----------------------------------------------------------------------------------------------------
#. check firstBoot param in config.json if ON
#. start in AP mode with page firstboot.html only if main power is on
#. if firstboot param is ON or TRY, we start the server with a special index page (firstboot.htm)
#. server.on( /firstBoot, firstBootHandler) - who send /firstboot
#. in firstBootHandler check param, write credential, set firstBoot param to "trySation" if needed
#. restart ESP
#. if Station is ok firstBoot is ended, set firstBoot param = off
#. if station ko reload firstboot page with alert

/fisrtboot page is send by firstboot.html page witch is register in place off index.html normale
page when we received /

Behavior when user move EPS from one physical site to another
----------------------------------------------------------------------------------------------------
It is not a first boot

EPS will search its WiFi station and will not find it so it restart in AP mode then user can acces
to the config special page change SSID and password.

.. index::
    single: Startup

=====================================
Start up behavior
=====================================

Question:what should be the behavior when power is switched to ON ?

2 cases are possibles when power is On: the button is switched to ON or the system restart after a
genaral power cut

Soit l'interrupteur général est actif (cas de la coupure EDF) et on reprend où on en était.

Soit l'interrupteur général est  inactif et on reprend en mode manuel.

L'interrupteur général coupe le 220V des prise mais pas de l'ESP8266.

Bien expliquer les 2 modes de fonctionnement dans l'interface WEB et donner le choix à l'utilisateur.

Expliquer le coup de la coupure de courant.

Evol : après coupure EDF : donner le choix à l'utilisateur de configurer le comportement de
chaque prise.

Possible behaviors:

 #. on repart d'où on en était (avec éventuellement alerte instantanée à l'utilisateur)
 #. on met tout la prise à OFF en manuel(avec éventuellement alerte instantanée à l'utilisateur)
 #. on informe l'utilisateur (canal à définir, MQTT ou autre...) qui décide mais on met en
    pause en attendant

When main power switch is off : html server post no reply.

Problem : when in AP mode WiFi start even if main power is OFF and in Station ESP connect to acces
point. It is not a logically expected behavior. When power switch is in OFF position no Wifi 
activity should be detected.

Solution wait for power on in ARDUINO setup function.
Restart ESP in ARDUINO loop when power is switch to OFF.

.. index:: Special push buttons

Special push button behaviors @startup
----------------------------------------------------------------------------------------------------
PB0 : @power on (not by power switch but by wall plug) start in simple manual mode see 
:ref:`WIFI Modes<refWifiModes>`

PB1 : in same conditions as above, start specials action only for expert and debug mode
(today create default json) with main power switch on on state (to be checked 21/10/2019) 

====================================================================================================
Weblinks
====================================================================================================

.. target-notes::

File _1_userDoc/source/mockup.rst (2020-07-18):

++++++++++++++++++++++++++++++++++++++++++++++++++++++++++++++++++++++++++++++++++++++++++++++++++++
Mock-up information
++++++++++++++++++++++++++++++++++++++++++++++++++++++++++++++++++++++++++++++++++++++++++++++++++++

:Auteur: J.Soranzo
:Date: Jully 2020
:Societe: VoRoBoTics
:Entity: VoLAB

.. contents::
    :backlinks: top

====================================================================================================
Constitution
====================================================================================================



====================================================================================================
Useful tips
====================================================================================================
5V power supply for the ESP

.. warning::
    Disconnect this power supply when ESP is connected via USB

Switch on power supply first, before PC USB connection

When powered and no led light expect ArduinoI2Cioextension, switch main power to on ;-)

====================================================================================================
Weblinks
====================================================================================================

.. target-notes::

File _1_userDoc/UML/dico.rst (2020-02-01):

:Auteur: J.Soranzo
:Date: May 2019
:version: git versionning

####

.. contents:: Table of Contents
.. section-numbering::

####

============================
Application dictionnary
============================

.. table:: IoT EPS Application dictionnary
    :align: left
    :widths: 30,20,10,20
    
    =================== =================== ================== ============================
    Name                Qualifier           Verb               Real-time constraint
    =================== =================== ================== ============================
    Interface
    Main power switch                                           texte
    =================== =================== ================== ============================

####

Verb

 - configur rtc
 - init I2c bus
 - To set time
 - Set the wifi mode
 - display stat
 - store data
 - drive relais
 - process wifi request
 - manages plugs

Name
 - IP address
 - Wifi Mode
 - Real time clock
 - Access point

Qualifier
- Red
- Green
- Bleu
- yellow
-

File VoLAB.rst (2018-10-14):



=====
VoLAB
=====

Nous connaître
--------------

   :Le Site Web:       http://www.volab.org 

   :Le Wiki:           http://www.vorobotics.com/wiki/index.php?title=Accueil 

   :GitHub:            https://github.com/volab 

   :Twitter:           https://twitter.com/vorobotics 

   :Faceboock:         https://www.facebook.com/VoLab95/ 

Qui sommes nous ?
-----------------

   Le VoLAB, premier FabLab du Val d'Oise, est un FabLab associatif portée par
   l'associassions VoRoBoTics situé Vauréal (95480).

   Nous avons pour vocation le partage non marchand des connaissances
   et l'échange de compétences. Petits et gros projets se cotoient dans divers domaines comme :

   Le travail du bois, du métal, l'électronique, la programmation, la sérigraphie,
   la couture, le scrapbooking et bien d'autres encore.

   Les échanges dynamiques dans la bonne humeur et le respect mutuel permettent
   à chacun d'appendre et de partager à son rythme

   **N'hésitez pas venir nous rendre visite.**

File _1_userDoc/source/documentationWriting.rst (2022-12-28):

++++++++++++++++++++++++++++++++++++++++++++++++++++++++++++++++++++++++++++++++++++++++++++++++++++
Documentation writing
++++++++++++++++++++++++++++++++++++++++++++++++++++++++++++++++++++++++++++++++++++++++++++++++++++

.. include:: volabid.rst

:Creation date: 12/2022
:Last update: 12/2022

====================================================================================================
logo
====================================================================================================
Created by Pierre with Inskape:



====================================================================================================
Favicon
====================================================================================================
Created with: `favicon.io`_

.. _`favicon.io` : https://favicon.io/



====================================================================================================
Visual guide
====================================================================================================

Write with Inskape



====================================================================================================
Weblinks
====================================================================================================

.. target-notes::

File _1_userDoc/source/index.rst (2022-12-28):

+++++++++++++++++++++++++++++++++++++++++++
IoT_EPS's documentation
+++++++++++++++++++++++++++++++++++++++++++



.. toctree::
   :maxdepth: 2
   :caption: Chapters and sub chapters of this documentation
   :titlesonly:
   
   generalProgress
   softDev
   hardDev
   Bug_ToDoLst
   assembly
   userManual
   pitch
   chronogram

.. CAUTION::

   This is only chapters and sub-chapters of the doc. Go in them to see their full table of contents

.. NOTE::

   notation

.. todo:: test de todo
   :class: without-title

.. DANGER::

   texte

.. WARNING::

   texte

.. SEEALSO::

   texte

.. SEEALSO:: on s'en fou royalement
   :class: without-title

==================
Indices and tables
==================

* :ref:`genindex`
* :ref:`search`

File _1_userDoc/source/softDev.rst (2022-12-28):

+++++++++++++++++++++++++++++++++++++++++++++++++++++++++++++++++
Software development documentation
+++++++++++++++++++++++++++++++++++++++++++++++++++++++++++++++++

.. include:: volabid.rst

:last update: 28/12/2022

.. toctree::
   :maxdepth: 2
   :caption: Sub chapters
   :titlesonly:

   firstboot
   plugmodes
   configAndParam
   wifiwebinternet   
   curentSensing
   variable
   testToBeConducted
   jsonImprovment
   pythonTools

.. |clearer|  raw:: html

=============================
Source code documentation
=============================

Source code documentation provide a lot of informations
 
 `<codeDoc\\html\\index.html>`_

===========================
Progress of development
===========================

Terminated
----------------------------------------------------------------------------------------------------

::

    #. Display single static html page:                                                      ok
    #. Affichage page html fichier SPIFFS :                                                  ok
    #. Affichage de l'heure à partir d'une page en dur dans le code :                        ok
    #. Affichage page avec CSS :                                                             ok
    #. Gestion des mode wifi SoftAP vs client :                                              ok
    #. reception d'une action via un bouton :                                                ok
    #. lecture du fichier de configuration :                                                 ok
    #. intégration MCP23017 :                                                                ok
    #. lecture du fichier de configuration config3.json :                                    ok
    #. gestion bouton poussoir mécanique :                                                   ok
    #. Write json file :                                                                     ok
    #. Traitement de la requête html avec analyze, exécution et écriture json:               ok
    #. manage wif led :                                                                      ok
    #. integrate nano expander with analog inputs :                                          ok
    #. scan I2C response 57 and 58 nano IoExpander !!!! not a bug simply DS3231 board has 2 component DS3231 an EEPROM ! OK
    #. Time managment strategy :                                                             ok
    #. review work without rtc component strategy                                            ok
    #. review work without NTP access strategy                                               ok
    #. define rtc component versus NTP update strategy                                       ok
    #. suppress html replies if main power is off                                            ok
    #. generate a unique server name                                                         ok
    #. rewrite main program setup and loop function with more object oriented structure      ok
    #. add OLED display managment in accordance of its hardware implementation of course     ok
    #. creation of config.h and config-advenced.h (see :ref:`see project todo list<todocreateconfigfile>`) **OK**
    #. new bug in 2022 : json writes incorrect : ex : cycle hdebut and hfin ="" !!! **OK**
       detect 05/1/2022 correcte 8/01/2022
    #. Correct watchdog bug  **OK**
    #. Correct corrupted on/off compt bug see bug and todo list
    #. Correct internet error bug see bug and todo list

In progress
----------------------------------------------------------------------------------------------------

Transferred :ref:`here<mainTodoList>`

====================================================================================================
Software architecture or how does it work
====================================================================================================
Some words on software architecture @13/07/2020

see also :ref:`Json file improvements : analyze<jsonFileImprovementsAnalyze>`

Major points
----------------------------------------------------------------------------------------------------

One main .ino file with its .h : IoT_EPS.
In the header file we can find include and config informations. (to changed - 
:ref:`see project todo list<todocreateconfigfile>` ) Now we have the IoT_EPS.h with includes and 
config.h for parameters and config_advanced.h for advanced parameters.

A lot of usage of global variables and objects (not very optimal). :ref:`See variables list<refVariableList>`

Usage of one big json file (except for credentials) to store plugs information and 
application parameters. Not optimal (a better choice would be one file for general informations and
one file for plugs parameters and perhaps one file by plug).

Usage of static functions in some classes like *Crtc* due to usage of external library.

Usage of a pseudo object in **SerialCommand** (just a struct) due to reuse of code from an other project.

The embedded html server is based on **ESP8266webserver** class 

Global File system SPIFFS is based on **ESP8266 core**

Operations
----------------------------------------------------------------------------------------------------
An array of 4 plug objects manage the behavior of the plugs. Events from wifi trigs 
web server functions. The main part of the jobs is to write data in the json file that it is resend
to the user's web browser.

Timing are managed by CRtc a derived class from rtc from RTClib.

The wifi : after a long expectation where I navigate between station mode or softAP mode. Finally,
I activate the 2 modes simultaneously.

====================================================================================================
How does it work
====================================================================================================
There is 2 worlds

The Plugs world and the Web world.

The Plug world
----------------------------------------------------------------------------------------------------
It is although the hardware or physical world

**Setup sequence**

- serial, time, ftp, debug oled screen init
- Watchdog check
- Main power first check (already on ? Return from electrical power down, hot restart)
- Plugs config
- Main power wait ON (the purpose is to maintain Wifi off) loop
- WIFI start
- Server configurations
- Time server check 
- Setup last operations (displayCommandsList, initCBITTimer, check internet access and setup wd)

**Loop sequence**

- CBIT : Continus Built In Test Start : periodicly check file system, internet access
- watchdog refresh
- Some little jobs : specialBp, ftp, SerialProcess...
- manage leds
- manage bps + plugs time to switch  
- main power switch actions

The Web world
----------------------------------------------------------------------------------------------------
Server event (HTTP GET requests). They are mapped to callback C functions (CServerWeb methods)

  ============== ===================================================================================
  Event          Binded functions
  ============== ===================================================================================
   /             firstBootHtmlForm, handleSoftAPIndex or handleIndex
   /time         displayTime
   /list         handleFileList
   /plugonoff    handlePlugOnOff
   /help         handleHelp
   /edit         handleEdit, handleFileCreate, htmlOkResponse, handleFileUpload, handleFileDelete
   /cfgpage      handelIOTESPConfPage
   /cfgsend      handleIOTESPConfiguration
   /changeCred   handleNewCred
   /firstBoot    handleFirstBoot
  ============== ===================================================================================

Theses events are triggered by HTTP requests from user's Web browser. Some of these above request are
not implemented in http pages and are only for debug and should be send directly in the uri like 
``/time``

Html pages are stored in the data folder of the SPIFFS in the ESP8266 flash.

Links between the 2 worlds
----------------------------------------------------------------------------------------------------
These 2 worlds live their lives almost independent of each other.

There are 2 links between them:

- the json file
- the time

Events write data in json file and physical part of the system check periodicaly the data in the 
json file and do the jobs.

.. _devProgress:

Differed to next version
----------------------------------------------------------------------------------------------------

::

    #. power measurement - not in this vesion

====================================================================================================
Config.h and config_advenced.h
====================================================================================================
config.h include all user define macro.

config_advenced.h group all others interesting parameters

.. _webBrowserCaching:

====================================================================================================
web caching
====================================================================================================
see to do list.
Perhaps use following method but i don't find how to use it

server->serveStatic("/", SPIFFS, "/index.html");

function prototype::

    void serveStatic(const char* uri, fs::FS& fs, const char* path, const char* cache_header = NULL );

Another example::
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

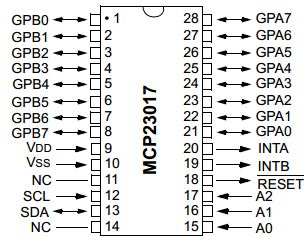
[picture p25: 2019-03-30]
_1_userDoc/source/image/mpc2307_pinout.png

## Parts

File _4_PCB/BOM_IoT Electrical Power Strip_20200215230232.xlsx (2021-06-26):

ID | Name | Designator | Footprint | Quantity | Manufacturer Part | Manufacturer | Supplier | Supplier Part
1 | POWER5V | P2 | HDR-TH_2P-P2.54-V-M | 1 | 2.54-1*2PFemale | BOOMELE | LCSC | C49661
2 | POWLEDHEADER | P3 | HDR-TH_2P-P2.54-V-M | 1 | 2.54-1*2PFemale | BOOMELE | LCSC | C49661
3 | WIFILEDHEADER | P4 | HDR-TH_2P-P2.54-V-M | 1 | 2.54-1*2PFemale | BOOMELE | LCSC | C49661
4 | ONOFFHEADER | P7 | HDR-TH_2P-P2.54-V-M | 1 | 2.54-1*2PFemale | BOOMELE | LCSC | C49661
5 | WDDEBUG | P8 | HDR-TH_2P-P2.54-V-M | 1 | 2.54-1*2PFemale | BOOMELE | LCSC | C49661
6 | WDRESETBT | P9 | HDR-TH_2P-P2.54-V-M | 1 | 2.54-1*2PFemale | BOOMELE | LCSC | C49661
7 | SPECIALPB | P6 | HDR-TH_2P-P2.54-V-M | 1 | 2.54-1*2PFemale | BOOMELE | LCSC | C49661
8 | SRD-05VDC-SL-C | RELAY1 | RELAY-SL-SRD | 1 | SRD-05VDC-SL-C | SONGLE | LCSC | C35449
9 | 1N4448 | D1 | DO-35 | 1 | 1N4448 | SEMTECH | LCSC | C54037
10 | 330 | R1,R5,R6,R7,R8 | AXIAL-0.4 | 5
11 | 270 | R2 | AXIAL-0.4 | 1
12 | 15k | R3,R4 | AXIAL-0.4 | 2
13 | 1K5 | R9,R10,R11,R12 | AXIAL-0.4 | 4
14 | Relays | J1 | HDR-TH_10PIN-V-FEMALE-PITCH2.54 | 1 | 2.54mm 1*10P Straight Female header Gold-plated | BOOMELE | LCSC | C35445
15 | 4COLORLEDHEADER | H4 | DIP-1X4P-2.54MM-M | 1 | 210S-1*4P L=11.6MMGold-plated black | Ckmtw | LCSC | C124378
16 | 470uF/25V | C3,C1,C7 | CAP-D8.0XF3.5 | 3
17 | PBHEADER | H1 | HDR-5X1/2.54 | 1 | 2.54mm 1*5p Female header | BOOMELE | LCSC | C50950
18 | ARDUINO_NANO | U2 | ARDUINO_NANO | 1
19 | I2CSpare | H3 | DIP-1X5P-2.54MM-M | 1 | 210S-1*5P L=11.6MMGold-plated black | Ckmtw | LCSC | C124379
20 | 2N7000 | Q1,Q2,Q3,Q4 | TO-92(TO-92-3) | 4 | 2N7000 | CJ | LCSC | C9114
21 | 100n | C2,C4,C5,C6,C8 | RAD-0.1 | 5
22 | TS-1102-5016 | KEY1 | KEY-6.0*6.0-2 | 1 | TS-1102-5016 | SOFNG | LCSC | C111609
23 | WEMOS D1 MINI | U1 | WEMOS D1 MINI | 1 | Wemos D1 mini
24 | LEDHEADER | P5 | HDR-8X1/2.54 | 1 | Female headerHDR1X8-2.54 | BOOMELE | LCSC | C27438
25 | Analog | P10 | HDR-8X1/2.54 | 1 | Female headerHDR1X8-2.54 | BOOMELE | LCSC | C27438
26 | ATTINY85V-10P | U3 | PDIP08_300MIL | 1
27 | RTC | P1 | HDR-6X1/2.54 | 1 | Female header 1*6p | BOOMELE | LCSC | C40877

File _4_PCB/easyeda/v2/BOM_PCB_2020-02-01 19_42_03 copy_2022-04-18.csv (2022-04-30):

ID | Name | Designator | Footprint | Quantity
1 | SS26 | D2,D3 | SMB(DO-214AA) | 2
2 | RTC | P1 | DIP-1X4P-2.54MM-M | 1
3 | WIFI_POW_LEDHEADER | P3 | PINHEADER1X3 | 1
4 | LEDHEADER | P5 | HDR-5X1/2.54 | 1
5 | 2N7002-TP | Q1,Q2,Q3,Q4 | SOT-23-3_L2.9-W1.3-P1.90-LS2.4-BR | 4
6 | FDN340P | Q5 | SOT-23-3_L2.9-W1.6-P1.90-LS2.8-BR | 1
7 | 330Ω | R1,R2,R5,R6,R7,R8 | R1206 | 6
8 | 15kΩ | R3,R4 | R1206 | 2
9 | 1.5kΩ | R9,R10,R11,R12 | R1206 | 4
10 | 10kΩ | R14 | R1206 | 1
11 | Relays | J1 | HDR-6X1/2.54 | 1
12 | POWER5V | P2 | HDR-TH_2P-P2.54-V-M | 1
13 | SPECIALPB | P6 | HDR-TH_2P-P2.54-V-M | 1
14 | ONOFFHEADER | P7 | HDR-TH_2P-P2.54-V-M | 1
15 | WDDEBUG | P8 | HDR-TH_2P-P2.54-V-M | 1
16 | WDRESETBT | P9 | HDR-TH_2P-P2.54-V-M | 1
17 | TS-1102-5016 | KEY1 | KEY-6.0*6.0-2 | 1
18 | 470uF/25V | C7,C1 | CAP-D8.0XF3.5 | 2
19 | 100n | C8,C2,C4,C5,C6 | RAD-0.1 | 5
20 | ATTINY85V-10P | U3 | PDIP08_300MIL | 1
21 | ARDUINO_NANO | U2 | ARDUINO_NANO | 1
22 | WEMOS D1 MINI | U1 | WEMOS D1 MINI | 1
23 | 4COLORLEDHEADER | H4 | DIP-1X4P-2.54MM-M | 1
24 | PBHEADER | H1 | HDR-5X1/2.54 | 1
25 | I2CSpare | H3 | DIP-1X5P-2.54MM-M | 1
26 | Analog | P10 | HDR-8X1/2.54 | 1

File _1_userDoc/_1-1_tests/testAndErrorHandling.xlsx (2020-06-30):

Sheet: Comon tests
Nom du test | Procédure | Attenus | Résultat | date | version (git SHA)
Wifi mode client (station)
Wifi mode AP
Main power switch off |  | All LED off
Main power switch on
RTC tests
Test under tablette and PC and phone
First boot tests: normal, SSID connect
First boot tests: normal, SSID connect wrong cred
First boot tests: normal, AP mode
First boot tests: normal, AP mode too short pass
First boot tests: normal, AP mode too long pass
I2C recovery
I2C recovery : 3 error max => fatal error
Internet access | Connect sytem to pi IOT gateway Disconnect internet pi access | Fatal error blink royal bue and orange Red

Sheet: Test RED plug
Nom du test | Prise | Procédure | Attenus | Résultat | date | version (git SHA)
Mode manual RED ON/OFF simple via HTML | RED | Vérifier à chaque fois l'affichage dans le Json |  | OK | 2019-04-03 | ac02290
Mode manual RED ON/OFF simple via BP | RED | - |  | OK | 2019-04-03 | ac02290
Mode manual RED ON/OFF via HTML duree avant arrêt | RED | fixer un durée chronomètrer attendre |  | OK | 2019-04-03 | ac02290
Mode manual RED ON/OFF via HTML duree avant arrêt |  | Ne pas remplir le champ | Pas de prise en compte | KO | 2019-04-03 | ac02290
Mode manual RED ON/OFF via HTML duree avant arrêt > 300 | RED | Ne pas être transmis | Ne se plante pas | OK | 2019-04-03 | ac02290
Mode manual RED ON/OFF via HTML heure d'arrêt | RED |  |  | OK | 2019-04-03 | ac02290
Mode manual RED ON/OFF via HTML heure d'arrêt incorrecte | RED |  | Ne pas être transmis | OK | 2019-04-03 | ac02290
Cleanup button |  | Arret checked and all others field removed |  | KO | 2019-04-03 | ac02290
Mode manuel intérrogation par BP |  |  | 1 clignotement | OK
Mode minuteur de base via Web | RED | Saisie avec des seconde
Mode minteur relance par BP | RED
Mode minuteur démarrage différé via BP | RED
Mode minuteur relance par BP alors qu'on est déjà ON | RED |  | on ne relance pas
Mode minuteur valeur incorrecte | RED | >300mn, carcatère diff de : | Ne se plante pas
Mode minuteur interrogation par BP | RED |  | 2 clignotements
Mode minuteur appuis long retour au mode manuel | RED |  | retour manu
Mode périodique

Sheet: Errors
Subject | Error | Gravity | BIT | instanciat | color | Fonctionnal issues | Mode dégradé | Comment | implemented | Possibles causes
Filesystem | No SPIFFS | FATAL | P | fsErr | Red/Bleu | Only Very simple mode possible : NO Internet : no RTC: OK NanoI2CIOExpander: OK HTML files: NO | debug link fonctionnal | Manual mode ON/OFF with BP To return to normal : correct the pb and restart so no need to do in CBIT No : there is no Cparm so Fatal error | OK | ESP8266 high failure
Filesystem | No index HTML page | FATAL | P/C | filesErr | OrangeRed/Black | No HTML interface | Only Very simple mode possible : NO ? Why (17/06/2020) |  |  | ESP8266 little failure User wrong handling or wrong command
Filesystem | Some necessary files lost as for example css, js | FATAL | P/C |  |  | Same as previous | Manual ON/OFF with only PB should be activ | liste exhaustive pour vérifier, tout ce qui est dans data main.js plug.js regExpatern.js table.js index.html sidebarr.css style.css firstboot.html (perhaps) config.html jquery-3.3.1.min.js (à venir) bootstrap.min.css (à venir) bootstrap.min.js (à venir)
Filesystem | config param : no access to file <=> config.json no access | FATAL | P | confFileErr | Red/Yellow
Filesystem | config param : wrong structure | FATAL | P | confFileErr | Red/Yellow |  | Same as previous | To day, class ConfigParam dosen't report such detail
time | No RTC (in station mode connected and NTP accessible) | FATAL | P/C |  | Pink |  | if Station mode connected and NTP server | Fired by rtcErr ! For all time errors
time | No RTC (in station mode connected and no NTP accessible | FATAL | C | rtcErr | Pink
time | No RTC in AP mode connected | FATAL | C | rtcErr | Pink |  | no for the same reaseons Only manual mode BP and WEB
i2c | I2C Ko after 3 Recovery I2C | FATAL | P | removed |  |  |  | Not seen I2C hang in work mode only at start up If we loose I2C in the loop its fatal error
i2c | I2C IO expander not accesible | FATAL | P/C | nanoErr | red/black |  |  | To day nanoErr and i2cErr are same. There is no mean to test I2C bus alone only through rtc or nano the only 2 components connected to the bus
i2c | watch dog component not accessible | FATAL | P/C | errWatchdog | Snow
plug |  | FATAL | P | plugParamErr | Red/Snow
wifi | No Wifi station | MED | P |  |  |  | AP mode
wifi | No Wifi AP | HIGH | P/C |  |  |  |  | FATAL error if nor AP and station mode not accessibles
wifi | WiFi Ok mais pas d'internet | FATAL | P/C |  |  |  | Pas de CDN (boostrap et jQery) pour l'interface | passer à la version light de l'interface En signalant dans la page qu'on a pas d'accès à internet Pour le tester faire un ping Passé à FATAL le 19/06/2019 : trop chiant. LE but est arrivé enfin au bout du dev.
time | No NTP server with RTC | LOW | P/C |  |  |  |  | Server could be temporary down
internet | no access in station mode only | FATAL | C | Orange Red/Royal blue |  |  |  | due to the usage of CDN
i2c | pert du bus I2C in loop | FATAL | C
i2c | no I2C bus @ powerup | MED |  |  |  |  | MED if recovery is possible | Not a real error see below
Filesystem | credential : no access to | MED | P |  |  |  | Start in mode AP
Filesystem | credential : wrong structure | MED | P |  |  |  | Start in mode AP
 | Comportement à la MST
 | Very simple manual mode
 | Check WiFi LED behavior

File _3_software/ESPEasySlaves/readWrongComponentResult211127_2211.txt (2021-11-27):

E:\avrdude>avrdude -v -pattiny85 -cstk500v1 -PCOM12 -b19200 -Uflash:r:TinyI2CWatchdog_nonFonctionnel.hex:i

avrdude: Version 6.3-20171130
         Copyright (c) 2000-2005 Brian Dean, http://www.bdmicro.com/
         Copyright (c) 2007-2014 Joerg Wunsch

         System wide configuration file is "E:\avrdude\avrdude.conf"

         Using Port                    : COM12
         Using Programmer              : stk500v1
         Overriding Baud Rate          : 19200
         AVR Part                      : ATtiny85
         Chip Erase delay              : 400000 us
         PAGEL                         : P00
         BS2                           : P00
         RESET disposition             : possible i/o
         RETRY pulse                   : SCK
         serial program mode           : yes
         parallel program mode         : yes
         Timeout                       : 200
         StabDelay                     : 100
         CmdexeDelay                   : 25
         SyncLoops                     : 32
         ByteDelay                     : 0
         PollIndex                     : 3
         PollValue                     : 0x53
         Memory Detail                 :

                                  Block Poll               Page                       Polled
           Memory Type Mode Delay Size  Indx Paged  Size   Size #Pages MinW  MaxW   ReadBack
           ----------- ---- ----- ----- ---- ------ ------ ---- ------ ----- ----- ---------
           eeprom        65    12     4    0 no        512    4      0  4000  4500 0xff 0xff
           flash         65     6    32    0 yes      8192   64    128 30000 30000 0xff 0xff
           signature      0     0     0    0 no          3    0      0     0     0 0x00 0x00
           lock           0     0     0    0 no          1    0      0  9000  9000 0x00 0x00
           lfuse          0     0     0    0 no          1    0      0  9000  9000 0x00 0x00
           hfuse          0     0     0    0 no          1    0      0  9000  9000 0x00 0x00
           efuse          0     0     0    0 no          1    0      0  9000  9000 0x00 0x00
           calibration    0     0     0    0 no          1    0      0     0     0 0x00 0x00

         Programmer Type : STK500
         Description     : Atmel STK500 Version 1.x firmware
         Hardware Version: 2
         Firmware Version: 1.18
         Topcard         : Unknown
         Vtarget         : 0.0 V
         Varef           : 0.0 V
         Oscillator      : Off
         SCK period      : 0.1 us

avrdude: AVR device initialized and ready to accept instructions

Reading | ################################################## | 100% 0.04s

avrdude: Device signature = 0x1e930b (probably t85)
avrdude: safemode: lfuse reads as 62
avrdude: safemode: hfuse reads as DF
avrdude: safemode: efuse reads as FF
avrdude: reading flash memory:

Reading | ################################################## | 100% 6.27s

avrdude: writing output file "TinyI2CWatchdog_nonFonctionnel.hex"

avrdude: safemode: lfuse reads as 62
avrdude: safemode: hfuse reads as DF
avrdude: safemode: efuse reads as FF
avrdude: safemode: Fuses OK (E:FF, H:DF, L:62)

avrdude done.  Thank you.

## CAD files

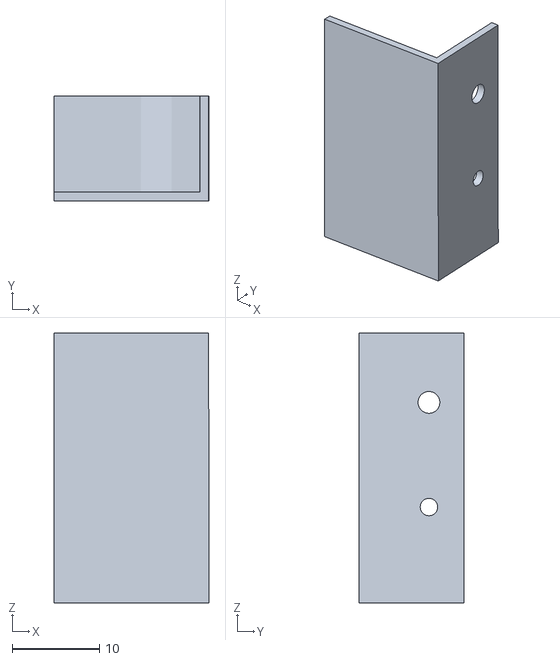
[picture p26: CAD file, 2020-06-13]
_2_modelisation/gabarit/gabaritPercageBouchonSym.stl
17.8 x 12.0 x 31.0

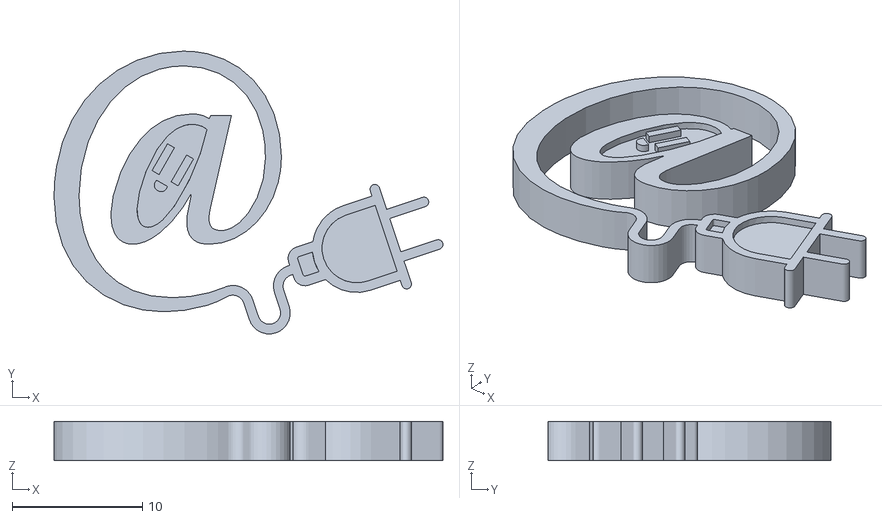
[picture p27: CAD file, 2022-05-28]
_2_modelisation/logo/exports/logo004-final.stl
29.9 x 21.7 x 3.00

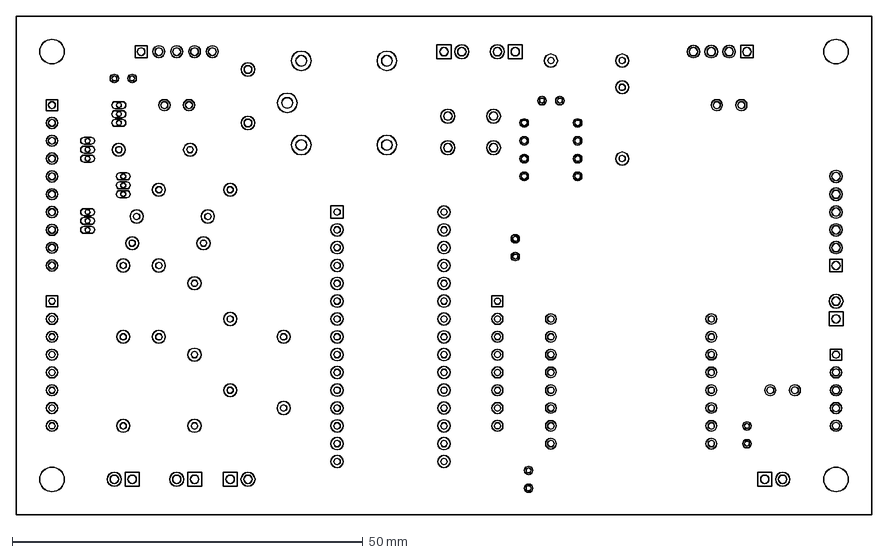
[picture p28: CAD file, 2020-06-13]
_2_modelisation/PCB_2020-02-01 19_42_03.dxf
121.9 x 71.1 mm

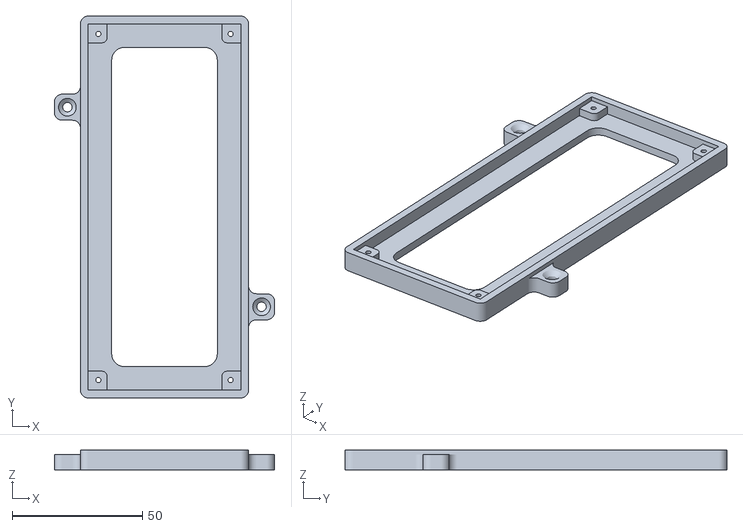
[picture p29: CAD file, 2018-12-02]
_2_modelisation/8relBob.stl
84.5 x 146.6 x 7.60

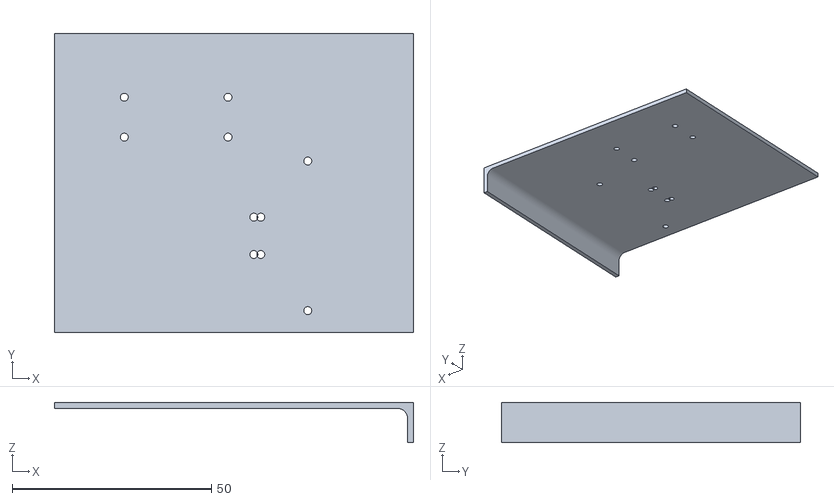
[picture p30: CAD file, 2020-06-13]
_2_modelisation/gabarit/gabaritOled.stl
90.0 x 75.0 x 10.1

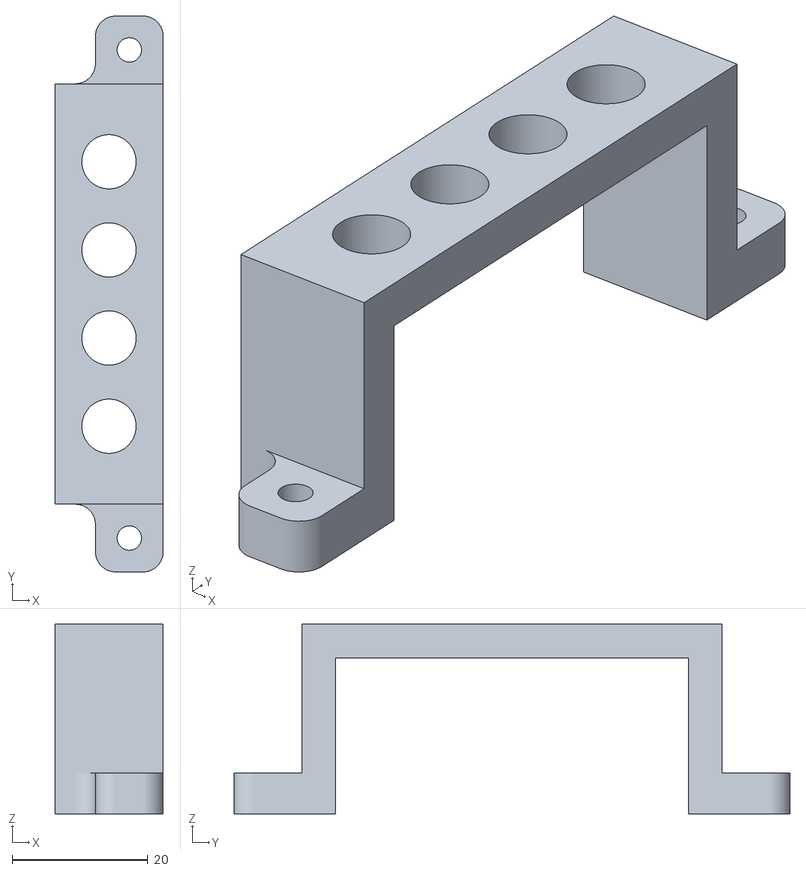
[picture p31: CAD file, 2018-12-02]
_2_modelisation/8mmLedBob v1.stl
16.0 x 82.0 x 28.0

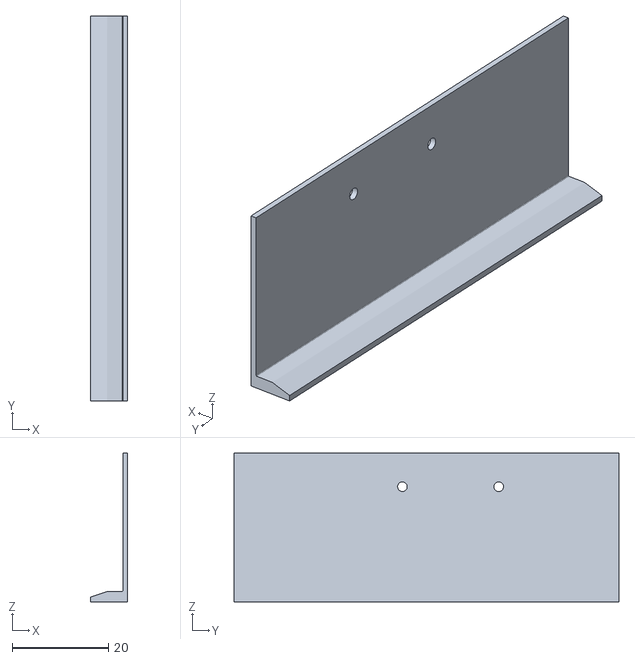
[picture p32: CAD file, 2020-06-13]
_2_modelisation/gabarit/gabaritBPGrossLed.stl
7.73 x 80.0 x 30.9

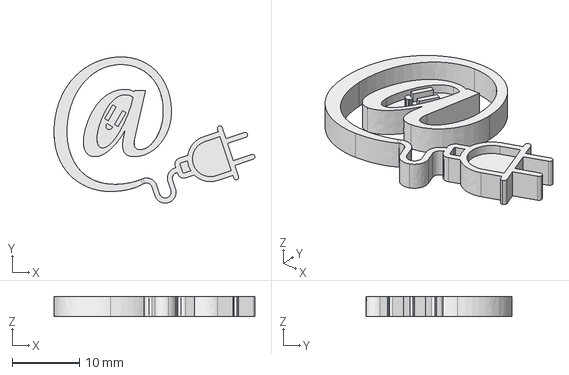
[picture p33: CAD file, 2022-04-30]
_2_modelisation/logo/logo003.FCStd
29.9 x 21.7 x 3.00 mm

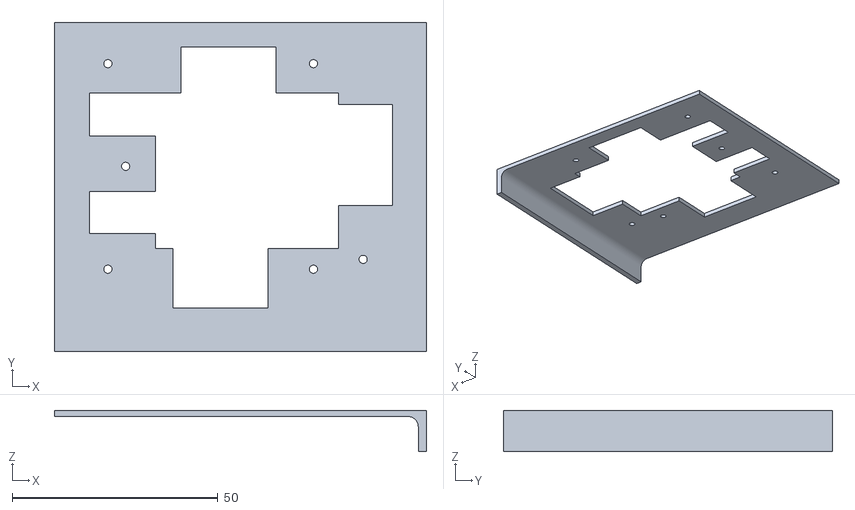
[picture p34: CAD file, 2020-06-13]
_2_modelisation/gabarit/gabaritPrise.stl
90.5 x 80.0 x 10.1

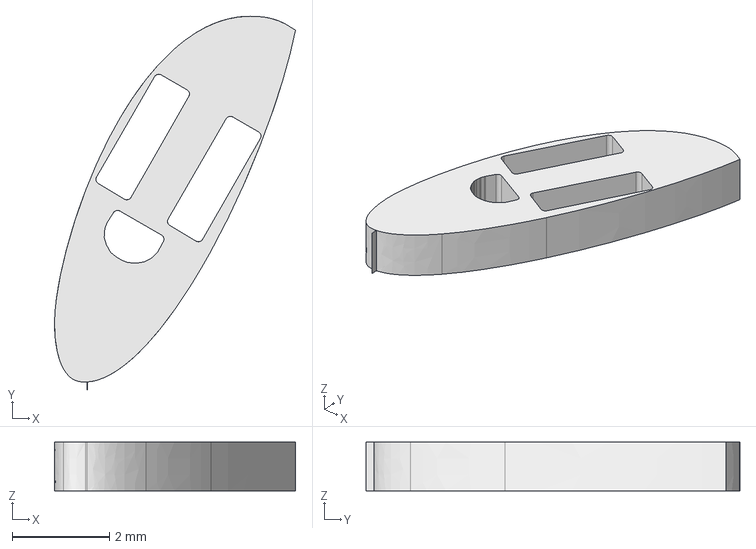
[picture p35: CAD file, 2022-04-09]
_2_modelisation/logo/logoFace.FCStd
4.95 x 7.67 x 1.00 mm

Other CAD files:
_2_modelisation/logo/logo005.FCStd
_2_modelisation/logo/exports/logo005-final.stl
_2_modelisation/logo/logo004.FCStd
_2_modelisation/gabarit/gabaritPercageBouchon.stl
_2_modelisation/logo/logo002.FCStd

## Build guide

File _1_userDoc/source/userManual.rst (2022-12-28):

++++++++++++++++++++++++++++++++
IoT_EPS User Manual
++++++++++++++++++++++++++++++++

.. include:: volabid.rst

:Date: Décembre 2019
:last update: 28/12/2022

.. toctree::
   :maxdepth: 2
   :caption: Contents
   :titlesonly:
   
   documentationWriting
   userManualAnex

================================
First connection
================================
When connecting the power Strip for the first time, user should connect a WiFi Device in AP mode and
search IoT_ESP_HHHH SSID (where HHHH is 4 hexadecimal digits) 
and connect to it with password : 123456789

User should change this password and configure ip and password for WIFI station mode and restart.

================================
WIFI connections
================================
**AP mode** : is always available and default SSID name is IoT_ESP_HHHH.

**Station mode** : is available after first configuration and credential settings. In this mode, 
human interface is mode responsive due to boostrap CDN usage.

In station mode, user can address all its iot plugs from its internet browser of its Mac, PC 
or Android device.

====================================================================================================
Set SSIDs
====================================================================================================
With Web interface in AP mode
----------------------------------------------------------------------------------------------------
- connect to the access point (see ip address on OLED screen)
- from AP mode main page, choose "Enter new credentials"

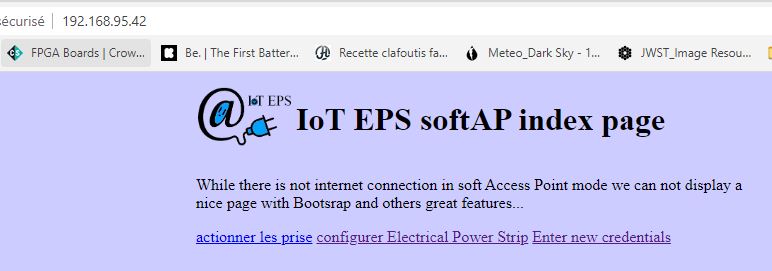
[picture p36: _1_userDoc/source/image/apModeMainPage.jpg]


    AP Mode main page 

- set credentials and clic send

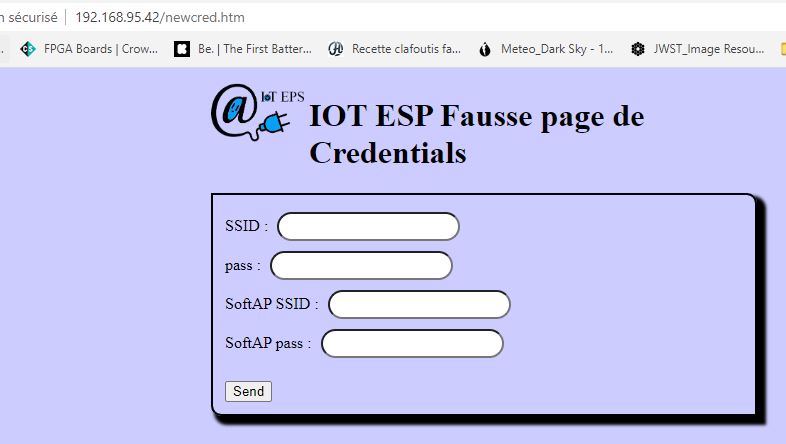
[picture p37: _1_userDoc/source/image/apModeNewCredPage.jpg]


    AP mode new credentials page 

.. NOTE:: Empty field are not change in the plug's credential file
   :class: without-title

With serial debug interface
----------------------------------------------------------------------------------------------------
For Station mode credentials, use :

- <I _newSSID> write SSID in credentials WARNING
- <i _wifiPass> write password in credentials WARNING

commands

And for AP mode credentials, use :

- <L> _newSoftAP_SSID> write SoftAP SSID in credentials WARNING
- <l> _wifiPass> write soft AP password in credentials WARNING

================================
Boutons
================================
In manuel mode, short press switch on/off the plug

Long press : return to manuel mode

At power up (wall plug - not by main power switch):
 - red push button : switch to very simple mode (without web interface)
 - green push button : restaure json file.

All the time Special PB + a plugs PB indicates the mode off the plug

- 1 flash <=> manual
- 2 flashes <=> timer
- 3 flashes <=> cycle
- 4 flashes <=> week mode

================================
Advanced user
================================

.. index::
    single: Serial;  speed

Serial com speed : 115200 (dans debugSerialPort.h DEBUGSPEED)

File upload : use web interface (need to be connected to internet) PowerStip01/edit
If your plug's name is PowerStrip01 or 192.168.1.xx/edit (access with it's IP addresse)

File delete : use seial commande <d _filename>

FTP server dosen't work very well

In csysstat.cpp et csysstat.h files, variable _forceSystemStartOnFatalError allow to disable the
sabordage behavior.

Special html pages (removed)
----------------------------------------------------------------------------------------------------
due to a lack of memory this pages was removed.

.. code::

    /time

    /edit to see and edit files in the SPIFFS (SPI Flash File System) of the ESP8266

    /list (just list files in json form) same as <D> serial command
    
Restaure data directory
----------------------------------------------------------------------------------------------------
.. WARNING:: Don't foget to put watchdog in 4mn15s wait with <Z> command
   :class: without-title

=========================================
Obtaine IP addresse of the Power strip 
=========================================
Use serial connexion <a> command if possible or an IP scanner like `AngryIP scanner`_

.. _`AngryIP scanner` : https://angryip.org/

Or read on OLED screen.

=========
Weblinks
=========

.. target-notes::

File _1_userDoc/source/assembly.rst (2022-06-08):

+++++++++++++++++++++++++++++++++++++++++++
IoT Electrical Power Strip Assembly manual
+++++++++++++++++++++++++++++++++++++++++++

:Auteur: J.Soranzo
:Date: December 2019
:update: 09/03/2022
:Societe: VoLAB
:Entity: VoRoBoTics

.. contents::
    :backlinks: top

====================================================================================================
Prepare relay board
====================================================================================================

joint command pin 2 by 2

.. NOTE:: To be completed with pictures (09/03/2022)
   :class: without-title

================================
Solder components onto the board
================================
Progressive assembly and test

To check the board fonctionnality, we need all I2C components:

- on the board:

  - ATtiny watch dog (programmed)
  - Nano I2C IO expander (programmed)

- out of the board

  - RTC
  - oled screen (not absolutly necessary for test but very usefull)

The 5V power supply

====================================================================================================
Program Attiny85 watchdog
====================================================================================================

- Outil => Arduino UNO
- Outil => Port COM 
- Fichier/exemples/11 ArduinoISP
- download ...
- File/open/ ... EasySlaves/TinyI2CWatchdog/TinyI2CWatchdog.ino
- Tools/ Attiny25/45/85
- Tools/ change ATtiny85
- Tools/ clock 8MHz
- Tools /Arduino as ISP
- Download.

`Link to add Atiny85 to Arduino IDE`_

.. _`Link to add Atiny85 to Arduino IDE` : https://raw.githubusercontent.com/damellis/attiny/ide-1.6.x-boards-manager/package_damellis_attiny_index.json

right clic anc copy/paste in Arduino preferences

Test it : com speed 1200

If ATtiny is wright programmed it should display  at power up::

    boot
    RC1I1
    RC2I1
    RC3I1... every second

====================================================================================================
Prepare your credentials file
====================================================================================================
You need to create a  credential.json file in the directory data of the Arduino project.

as this::

    {
        "general": {
            "ssid" : "yourWifiSsid",
            "pass" : "yourWifiPass",
            "softApSsid" : "IoT_ESP_mcmc",
            "softApPass" : "123456789"
        }
    }

SoftAp parameters are for connections in AP mode.
SoftAp password need to have at least 8c

====================================================================================================
Program ESP8266 in stand alone
====================================================================================================

Use Arduino IDE (tested with IDE v1.8.9)

Install ESP8266 from:

https://arduino.esp8266.com/stable/package_esp8266com_index.json

Following lib should be installed: see :ref:`used liraries<usedLirary>`

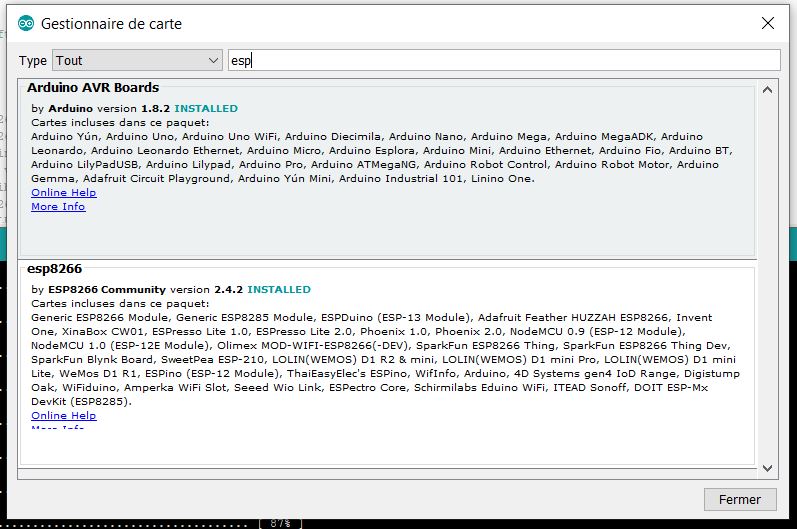
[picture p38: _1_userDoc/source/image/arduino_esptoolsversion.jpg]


You need also esptools to program SPIFFS

.. DANGER::
    ARDUINO IDE 1.8.12, ESP8266 2.4.7 doesn't work for me when i try to program SPIFFS.
	Error : esptool not found



    ESP8266 Arduino IDE conf 

Transfert data folder to ESP8266

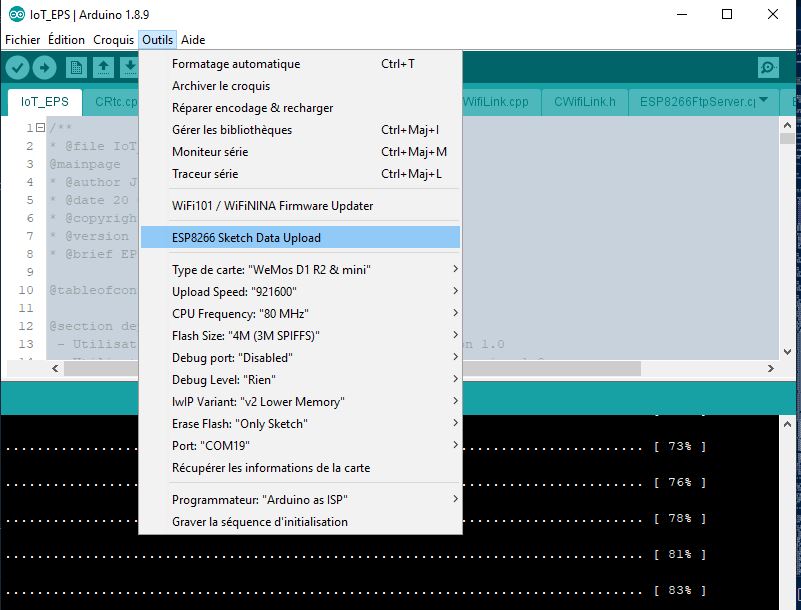
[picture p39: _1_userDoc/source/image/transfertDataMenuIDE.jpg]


Programm sktech

In serial monitor you should see
----------------------------------------------------------------------------------------------------
.. code::

    Volab CSystem::init > Sketch start...
    <Volab CSystem::init >  Build : May  5 2021 @ 21:34:05
    <Volab CSystem::init > File system correctly Open @ setup level
    <Volab CSystem::init > File check !
    <Volab CSystem::init > file : /index.html is present
    <Volab CSystem::init > file : /config4.json is present
    <Volab CSystem::init > file : /firstboot.html is present
    <Volab CSystem::init > file : /js/main.js is present
    <Volab CSystem::init > file : /js/plug.js is present
    <Volab CSystem::init > file : /js/regExPatern.js is present
    <Volab CSystem::init > file : /js/table.js is present
    <Volab CSystem::init > file : /css/sidebar.css is present
    <Volab CSystem::init > file : /css/style.css is present
    <Volab CSystem::init > Result all files are present ? OK
    <Volab reading config param. > Mounting FS...
    <Volab reading config param. > File system mounted 
    <Volab reading config param. > reading config file
        config file opened 
    <Volab reading config param. > Config file size : 1373
    <Volab CSystem::init > json mac add : 38:2B:78:04:AB:9F
    <Volab CSystem::init > Board Sation MAC add = 38:2B:78:04:AB:9F
    <Volab CSystem::init > Station equal add
    <Volab CSystem::init > json Soft AP mac add : 3A:2B:78:04:AB:9F
    <Volab CSystem::init > Board Soft AP MAC add = 3A:2B:78:04:AB:9F
    <Volab CSystem::init > AP equal add
    <Volab CSystem::init > I2C test start
    Write 0x10 to 1
    Write 0x12 to 2
    Read of reg 1 = ffffffff
    Read of reg 2 = ffffffff
    <Volab CSystem::init > i2cRecov number 1
    Starting I2C bus recovery
    Recovery ends with no known error
    Write 0x10 to 1
    Write 0x12 to 2
    Read of reg 1 = ffffffff
    Read of reg 2 = ffffffff
    <Volab CSystem::init > i2cRecov number 2
    Starting I2C bus recovery
    Recovery ends with no known error
    Write 0x10 to 1
    Write 0x12 to 2
    Read of reg 1 = ffffffff
    Read of reg 2 = ffffffff
    <Volab CSystem::init > i2cRecov number 3
    Starting I2C bus recovery
    Recovery ends with no known error
    Write 0x10 to 1
    Write 0x12 to 2
    Read of reg 1 = ffffffff
    Read of reg 2 = ffffffff
    <Volab CSystem::init > i2cRecov number 4
    Starting I2C bus recovery
    Recovery ends with no known error
    <Volab System error handler > Nano error
    <Volab CSystem::init > Nano test ok
    <Volab CSystem::init > Display oled Logo
    <Volab CSystem::init:Stratup Messages > OLED Logo pause
    <Volab CSystem::init:Stratup Messages > OLED startup message pause
    <Volab System error handler > DS3231 error
    <Volab CSystem::init > une remise a l'heure est necessaire
    <Volab CSystem::init > DS3231 Start date : 165/165/2165 165:165:85
    <Volab setUp > watchdog test 
    <Volab System error handler > watchdog error
    <Volab setUp > watchdog set to 30s.
    <Volab setUp > Main power state : ON
    <Volab setUp > number of plugs : 4
    <Volab write to jSon > redPlug : State = OFF
    <Volab reading config values for redPlug > Mode = Manuel
    <Volab reading config values for redPlug > Etat = OFF
    <Volab reading config values for redPlug > Start time = 
    <Volab reading config values for redPlug > End time = 
    <Volab reading config values for redPlug > on duration = 
    <Volab reading config values for redPlug > off duration = 
    <Volab reading config values for redPlug > Cloned plug = 
    <Volab reading config values for redPlug > Relay on off count = 70
    <Volab reading config values for redPlug > Jours : 
    <Volab write to jSon > greenPlug : State = OFF
    <Volab reading config values for greenPlug > Mode = Manuel
    <Volab reading config values for greenPlug > Etat = OFF
    <Volab reading config values for greenPlug > Start time = 
    <Volab reading config values for greenPlug > End time = 
    <Volab reading config values for greenPlug > on duration = 
    <Volab reading config values for greenPlug > off duration = 
    <Volab reading config values for greenPlug > Cloned plug = 
    <Volab reading config values for greenPlug > Relay on off count = 109
    <Volab reading config values for greenPlug > Jours : 
    <Volab write to jSon > bluePlug : State = OFF
    <Volab reading config values for bluePlug > Mode = Manuel
    <Volab reading config values for bluePlug > Etat = OFF
    <Volab reading config values for bluePlug > Start time = 
    <Volab reading config values for bluePlug > End time = 
    <Volab reading config values for bluePlug > on duration = 
    <Volab reading config values for bluePlug > off duration = 
    <Volab reading config values for bluePlug > Cloned plug = 
    <Volab reading config values for bluePlug > Relay on off count = 18
    <Volab reading config values for bluePlug > Jours : 
    <Volab write to jSon > yellowPlug : State = OFF
    <Volab reading config values for yellowPlug > Mode = Manuel
    <Volab reading config values for yellowPlug > Etat = OFF
    <Volab reading config values for yellowPlug > Start time = 
    <Volab reading config values for yellowPlug > End time = 
    <Volab reading config values for yellowPlug > on duration = 
    <Volab reading config values for yellowPlug > off duration = 
    <Volab reading config values for yellowPlug > Cloned plug = 
    <Volab reading config values for yellowPlug > Relay on off count = 9
    <Volab reading config values for yellowPlug > Jours : 
    <Volab setUp > Main power ON
    <Volab reading credentials > mounting FS...
    <Volab reading credentials > File system mounted
    <Volab reading credentials > Reading credit. file
        Credit. file is opened
    <Volab setUp, Wifilink begin > Wifi mode in json = Station
    <Volab setUp, Wifilink begin > try to set autoconnect to off
    <Volab setUp, Wifilink begin > Mode autoconnect read from ESP : enabled
    <Volab setUp, Wifilink begin > Wifi is connected ? No
    <Volab setUp, Wifilink begin > Wifi def mode in FLASH : 2
    <Volab setUp, Wifilink begin > Stored Wifi default soft AP param : 
    <Volab setUp, Wifilink begin >     SSID len : 10
    <Volab setUp, Wifilink begin >     Stored SSID :ESP_04AB9F.
    <Volab WiFi mode > WIFI_STA and AP
    <Volab setUp, Wifilink begin > Try softAccess
    <Volab setUp, Wifilink begin > Try soft AP with : powerStrip01_mac and plusDe8c
    <Volab setUp, Wifilink begin > softAP : Ready
    <Volab setUp, Wifilink begin > SoftAP returned IP address = 192.168.95.42
    <Volab setUp, Wifilink begin > Host name which does not work with Android is : PowerStrip01
    <Volab setUp, Wifilink begin > Try to join : Livebox-FX25689
    ...
    <Volab setUp, Wifilink begin > Number of Station wifi try : 3, max was : 30
    <Volab setUp, Wifilink begin > NTP enabled
    <Volab setUp, Wifilink begin > Adresse Wifi.localIP Station mode : 192.168.1.49
    <Volab write  param to jSon file > /config4.json
    <Volab write  param to jSon file >  general : staIP = 192.168.1.49
    <Volab setUp > NTP enable ? TRUE
    <Volab CSystem::timeServerCheck > check started
    <Volab CSystem::timeServerCheck > NTP Time : 5/5/2021 21:37:7
    <Volab CSystem::timeServerCheck > DS3231 set to NTP time due to power lost.
    <Volab write  param to jSon file > /config4.json
    <Volab write  param to jSon file >  general : ntpError = OFF
    Serial Command list :
    <h> ou <H> display this list
    <E> display status
    <C> Check DS3231 date
    <S JJ/MM/AAAA HH:MM:SS> returns code <O>
    <T HH:MM:SS> returns code <O>
    <s> set DS3231 by NTP server
    <J> for display config.json
    <W> display WIFI mode
    <P key value> write config parameter in json WARNING
    <I _newSSID> write SSID in credentials WARNING
    <i _wifiPass> write password in credentials WARNING
    <t various_param> for code test
    <N> nano IO expander test
    <O> nano out test HIGH
    <o> nano out test low
    <F> Find I2C device I2C scan
    <R> I2C recovery
    <c> I2C crash
    <a> for Ip address
    <w> for WiFi.printDig function
    <z> display credetial file
    <L> _newSoftAP_SSID> write SoftAP SSID in credentials WARNING
    <l> _wifiPass> write soft AP password in credentials WARNING
    <D> SPIFFS dir
    <j> display general part of config json file
    <d _filename> erase a file WARNING
    <e> display system status
    <p> display main power state
    <Volab setUp > Leds On config : -1
    <Volab setUp > Leds On lumi : 5
    <Volab setUp > [HTTP] begin...
    <Volab setUp > [HTTP] GET... http://www.google.fr/
    <Volab setUp > [HTTP] GET... code: 200
    <Volab setUp > Watchdog set to 10s with a refresh period to 5s
    <Volab setUp > Loop start
    <Volab in the loop > It is time to check necessary file accessibility !
    <Volab in the loop > It is time to check Internet health !
    <Volab in the loop > Check NTP access : OK
    <Volab in the loop > i2cRecov number 1
    Starting I2C bus recovery
    Recovery ends with no known error
    <Volab in the loop > i2cRecov number 2
    Starting I2C bus recovery
    Recovery ends with no known error
    <Volab in the loop > i2cRecov number 3
    Starting I2C bus recovery
    Recovery ends with no known error
    <Volab in the loop > i2cRecov number 4
    Starting I2C bus recovery
    Recovery ends with no known error
    <Volab System error handler > Nano error
    <Volab in the loop > It is time to check necessary file accessibility !
    <Volab in the loop > It is time to check Internet health !
    <Volab in the loop > Check NTP access : OK
    <Volab in the loop > i2cRecov number 1
    Starting I2C bus recovery
    Recovery ends with no known error
    <Volab in the loop > i2cRecov number 2
    Starting I2C bus recovery
    Recovery ends with no known error
    <Volab in the loop > i2cRecov number 3
    Starting I2C bus recovery
    Recovery ends with no known error
    <Volab in the loop > i2cRecov number 4
    Starting I2C bus recovery
    Recovery ends with no known error
    <Volab System error handler > Nano error

... A lots of errors : I2C, OLEDRTC clock, Nano IO Expander but WiFi work

====================================================================================================
Program Arduino nano
====================================================================================================
With nanoI2CIOExpander project



With ligne 19 in the file debugSerialPort.h uncommented Nano display debug info like this @9600 
serial speed::

    <Volab IOExpander setup : > NANO version : 2.1 : BUILD May  5 2021 22:39:15
    <Volab I2C ADD builder : > add pin number = 13
    <Volab I2C ADD builder : > D13 = LOW
    <Volab IOExpander setup : > I2C adresse : 58
    <Volab IOExpander setup : > registers[0] = 2
    <Volab IOExpander setup : > registers[1] = 0
    <Volab IOExpander setup : > registers[2] = 0
    <Volab IOExpander setup : > registers[3] = 55
    <Volab IOExpander setup : > registers[4] = 0
    <Volab IOExpander setup : > registers[5] = a5
    <Volab IOExpander setup : > registers[6] = 1
    <Volab IOExpander setup : > registers[7] = 0
    <Volab IOExpander setup : > registers[8] = 0
    <Volab IOExpander setup : > registers[9] = 0
    <Volab IOExpander setup : > registers[a] = 0
    <Volab IOExpander setup : > registers[b] = a5
    <Volab IOExpander setup : > registers[c] = a5
    <Volab IOExpander setup : > registers[d] = a5
    <Volab IOExpander setup : > registers[e] = a5
    <Volab IOExpander setup : > registers[f] = a5
    <Volab IOExpander setup : > registers[10] = a5
    <Volab IOExpander setup : > registers[11] = a5
    <Volab IOExpander setup : > registers[12] = a5
    <Volab IOExpander setup : > registers[13] = a5
    <Volab IOExpander setup : > registers[14] = a5
    <Volab IOExpander setup : > registers[15] = a5
    <Volab IOExpander setup : > registers[16] = a5
    <Volab IOExpander setup : > registers[17] = a5
    <Volab IOExpander setup : > registers[18] = ca
    <Volab IOExpander setup : > registers[19] = fe
    <Volab IOExpander setup : > registers[1a] = fe
    <Volab IOExpander setup : > registers[1b] = ca
    <Volab IOExpander setup : > registers[1c] = a5
    <Volab IOExpander setup : > registers[1d] = a5
    <Volab IOExpander setup : > registers[1e] = a5
    <Volab IOExpander setup : > registers[1f] = a5

But with this ligne commented it display nothing !

================================
Connect wires to the plugs
================================
Wire all parts like on this pictures

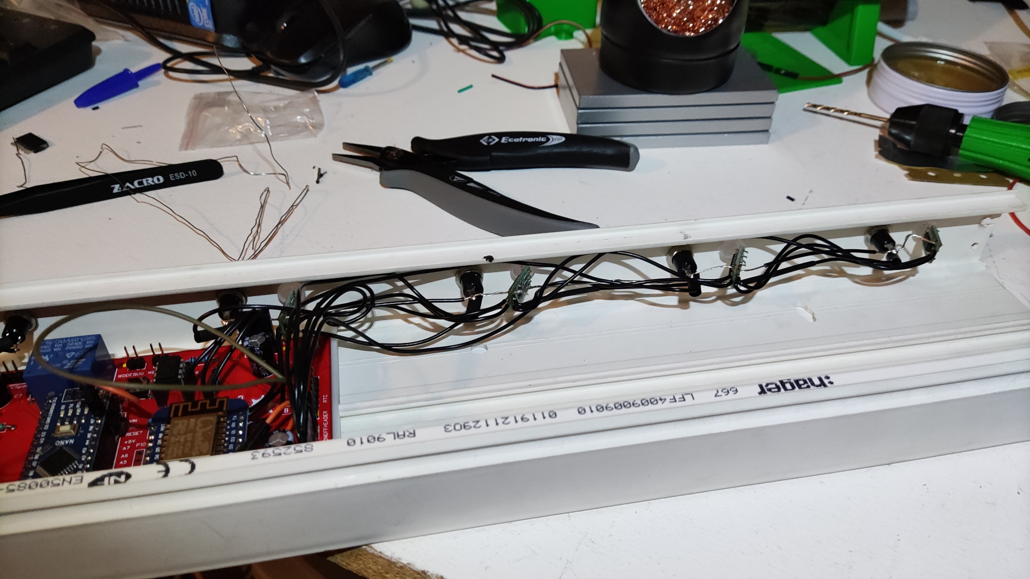
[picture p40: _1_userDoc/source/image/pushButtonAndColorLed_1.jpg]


    Push button and color led wires 

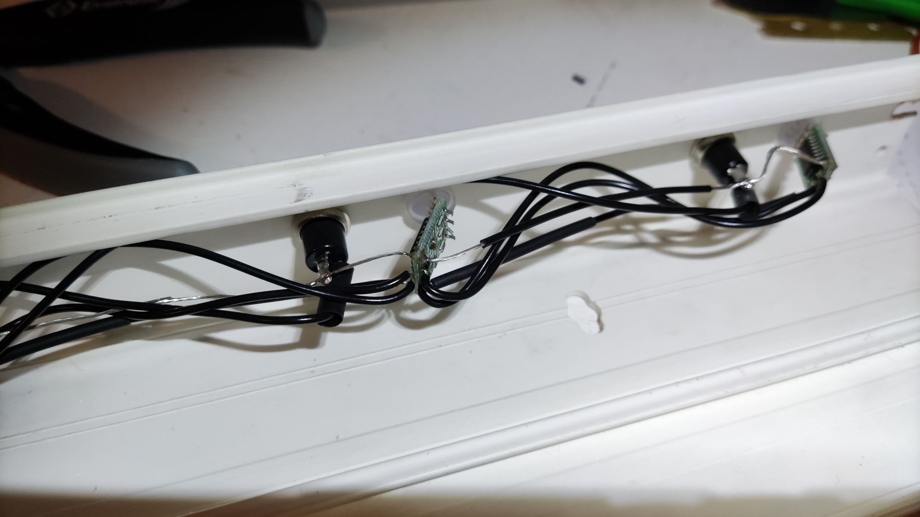
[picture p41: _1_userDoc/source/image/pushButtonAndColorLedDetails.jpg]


    Push button and color led wires details 

====================================================================================================
Notes de mise au point du PCB (A SUPRIMER)
====================================================================================================
Alimentation ? Quid de l'alim 5V et de l'alimentation USB

Donc avec le PCB 2664013A_Y7

Par où on commence ? 

- Par souder les composants passifs
- On vérifie l'absence de CC

Relay 1 : référence ? SRD-05VDC-SL-C. Est-ce que j'en ai ? `Lien Banggood SRD-05`_

.. _`Lien Banggood SRD-05` :   https://www.banggood.com/fr/Mini-5V-DC-Power-Relay-SRD5VDCSLC-5-Pin-PCB-Type-p-930170.html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

Des `relais 30A ! chez Banggood:`_

.. _`relais 30A ! chez Banggood:` : https://www.banggood.com/fr/5Pcs-SLA-05V-12V-24VDC-SL-A-SL-C-5V-12V-24V-DC-30A-4Pin-Relay-Module-p-1555743.html?ID=519957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

Données de mise au point:

- ajouter une diode sur le 5V de l'ESP pour éviter que l'USB ne réalimente la carte?
- de la même manière l'USB du UNO pourrait réalimenter la carte, ajouter une diode pin 27
- Pour les LED rouge mettre les résistance dans la branche + pour avoir un GND commun (simplification cablage)
- prepare collor LED with wires before mounting
- on pcb group P3, P6, P4 and P7 2 points connectors in only one connector with only one GND pin (R1 and R2 in the positiv branch)
- place this connector on the other size of the PCB
- reduce width of the PCB about 5 to 10 mm
- group P8 and P9 but keep 2 gnd pin
- migrate PCB to CMS version (R0806, C0603, Q1 to Q3 and U3)
- move p2 to the right side of the pcb under H1 and move H1 and P1 to the upper of the PCB (keep them on right)
- change realy1 to MOSFET version 
- ajouter une résistance 0 ohm sur le 3V3 du nano non montée afin de pouvoir injecter du 3.3 depuis ce dernier.
- relay connector : only one wire per chanel (short chanels two by two on relay board on solder side)

Dernier point inutile en fonctionnement mais pratique pour la mise au point.

Mise au point en juin 2020
----------------------------------------------------------------------------------------------------
Changement de pc de développement. Probblème avec la branche dev_jojo détecté grâce à gitKraken

Creation de la nouvelle branche devFirmware.

Programmation de l'ESP, sans rien autour. 

Difficultées avec la version des outils ESP8266 pour programmer SPIFFS.

Mais après avoir programmé l'ESP8266, on ne peut pas vérifier correctement le fonctionnement car
on bloque rapidement sur un Erreur fatale et impossible de diagnostiquer à cause du sabordage.

Création d'un branche dédiée à cette mise au point branch : noSaborde

=========
Weblinks
=========

.. target-notes::

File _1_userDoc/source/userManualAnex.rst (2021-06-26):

++++++++++++++++++++++++++++++++++++++++++++++++++++++++++++++++++++++++++++++++++++++++++++++++++++
User manual annexe
++++++++++++++++++++++++++++++++++++++++++++++++++++++++++++++++++++++++++++++++++++++++++++++++++++

:Auteur: J.Soranzo
:Date: August 2020
:Societe: VoRoBoTics
:Entity: VoLAB

.. contents::
    :backlinks: top

.. index::
    pair: Exmple; Serial output example

====================================================================================================
Serial monitor output example
====================================================================================================
.. code::
    
    <Volab CSystem::init > Sketch start...
    <Volab CSystem::init >  Build : Oct 13 2020 @ 23:26:33
    <Volab CSystem::init > File system correctly Open @ setup level
    <Volab CSystem::init > File check !
    <Volab CSystem::init > file : /index.html is present
    <Volab CSystem::init > file : /config4.json is present
    <Volab CSystem::init > file : /firstboot.html is present
    <Volab CSystem::init > file : /js/main.js is present
    <Volab CSystem::init > file : /js/plug.js is present
    <Volab CSystem::init > file : /js/regExPatern.js is present
    <Volab CSystem::init > file : /js/table.js is present
    <Volab CSystem::init > file : /css/sidebar.css is present
    <Volab CSystem::init > file : /css/style.css is present
    <Volab CSystem::init > Result all files are present ? OK
    <Volab reading config param. > Mounting FS...
    <Volab reading config param. > File system mounted 
    <Volab reading config param. > reading config file
    	config file opened 
    <Volab reading config param. > Config file size : 1394
    <Volab CSystem::init > json mac add : A0:20:A6:17:3F:B1
    <Volab CSystem::init > Board Sation MAC add = A0:20:A6:17:3F:B1
    <Volab CSystem::init > Station equal add
    <Volab CSystem::init > json Soft AP mac add : A2:20:A6:17:3F:B1
    <Volab CSystem::init > Board Soft AP MAC add = A2:20:A6:17:3F:B1
    <Volab CSystem::init > AP equal add
    <Volab CSystem::init > I2C test start
    Write 0x10 to 1
    Write 0x12 to 2
    Read of reg 1 = 10
    Read of reg 2 = 12
    <Volab CSystem::init > Nano test ok
    <Volab CSystem::init > Display oled Logo
    <Volab CSystem::init:Stratup Messages > OLED Logo pause
    <Volab CSystem::init:Stratup Messages > OLED startup message pause
    <Volab CSystem::init > DS3231 Start date : 14/10/2020 22:15:51
    <Volab setUp > watchdog test 
    watchdog OK
    <Volab setUp > watchdog set to 30s.
    <Volab setUp > Main power state : ON
    <Volab setUp > number of plugs : 4
    <Volab write to jSon > redPlug : State = OFF
    <Volab reading config values for redPlug > Mode = Cyclique
    <Volab reading config values for redPlug > Etat = OFF
    <Volab reading config values for redPlug > Start time = 
    <Volab reading config values for redPlug > End time = 
    <Volab reading config values for redPlug > on duration = 1
    <Volab reading config values for redPlug > off duration = 2
    <Volab reading config values for redPlug > Cloned plug = 
    <Volab reading config values for redPlug > Relay on off count = 62
    <Volab reading config values for redPlug > Next time to switch : Mercredi 14/10/2020 22:17:27
    <Volab reading config values for redPlug > Jours : 
    <Volab write to jSon > greenPlug : State = ON
    <Volab reading config values for greenPlug > Mode = Manuel
    <Volab reading config values for greenPlug > Etat = ON
    <Volab reading config values for greenPlug > Start time = 
    <Volab reading config values for greenPlug > End time = 
    <Volab reading config values for greenPlug > on duration = 
    <Volab reading config values for greenPlug > off duration = 
    <Volab reading config values for greenPlug > Cloned plug = 
    <Volab reading config values for greenPlug > Relay on off count = 173
    <Volab reading config values for greenPlug > Jours : 
    <Volab write to jSon > bluePlug : State = ON
    <Volab reading config values for bluePlug > Mode = Manuel
    <Volab reading config values for bluePlug > Etat = ON
    <Volab reading config values for bluePlug > Start time = 
    <Volab reading config values for bluePlug > End time = 
    <Volab reading config values for bluePlug > on duration = 
    <Volab reading config values for bluePlug > off duration = 
    <Volab reading config values for bluePlug > Cloned plug = 
    <Volab reading config values for bluePlug > Relay on off count = 5
    <Volab reading config values for bluePlug > Jours : 
    <Volab write to jSon > yellowPlug : State = OFF
    <Volab reading config values for yellowPlug > Mode = Manuel
    <Volab reading config values for yellowPlug > Etat = OFF
    <Volab reading config values for yellowPlug > Start time = 
    <Volab reading config values for yellowPlug > End time = 
    <Volab reading config values for yellowPlug > on duration = 
    <Volab reading config values for yellowPlug > off duration = 
    <Volab reading config values for yellowPlug > Cloned plug = 
    <Volab reading config values for yellowPlug > Relay on off count = 2
    <Volab reading config values for yellowPlug > Jours : 
    <Volab setUp > Main power ON
    <Volab reading credentials > mounting FS...
    <Volab reading credentials > File system mounted
    <Volab reading credentials > Reading credit. file
    	Credit. file is opened
    <Volab setUp, Wifilink begin > Wifi mode in json = Station
    <Volab setUp, Wifilink begin > try to set autoconnect to off
    <Volab setUp, Wifilink begin > Mode autoconnect read from ESP : disabled
    <Volab setUp, Wifilink begin > Wifi is connected ? No
    <Volab setUp, Wifilink begin > Wifi def mode in FLASH : 3
    <Volab setUp, Wifilink begin > Stored Wifi default soft AP param : 
    <Volab setUp, Wifilink begin >     SSID len : 14
    <Volab setUp, Wifilink begin >     Stored SSID :PowerStrip_mac.
    <Volab WiFi mode > WIFI_STA and AP
    <Volab setUp, Wifilink begin > Try softAccess
    <Volab setUp, Wifilink begin > Try soft AP with : IoT_ESP_3FB1 and 123456789
    <Volab setUp, Wifilink begin > softAP : Ready
    <Volab setUp, Wifilink begin > SoftAP returned IP address = 192.168.95.42
    <Volab setUp, Wifilink begin > Host name which does not work with Android is : PowerStrip01
    <Volab setUp, Wifilink begin > Try to join : VoLab
    .....
    <Volab setUp, Wifilink begin > Number of Station wifi try : 5, max was : 30
    <Volab setUp, Wifilink begin > NTP enabled
    <Volab setUp, Wifilink begin > Adresse Wifi.localIP Station mode : 192.168.1.20
    <Volab write  param to jSon file > /config4.json
    <Volab write  param to jSon file >  general : staIP = 192.168.1.20
    <Volab setUp > NTP enable ? TRUE
    <Volab CSystem::timeServerCheck > check started
    <Volab CSystem::timeServerCheck > NTP Time : 14/10/2020 22:16:0
    <Volab write  param to jSon file > /config4.json
    <Volab write  param to jSon file >  general : ntpError = OFF
    Serial Command list :
    <h> ou <H> display this list
    <E> display status
    <C> Check DS3231 date
    <S JJ/MM/AAAA HH:MM:SS> returns code <O>
    <T HH:MM:SS> returns code <O>
    <s> set DS3231 by NTP server
    <J> for display config.json
    <W> display WIFI mode
    <P key value> write config parameter in json WARNING
    <I _newSSID> write SSID in credentials WARNING
    <i _wifiPass> write password in credentials WARNING
    <t various_param> for code test
    <N> nano IO expander test
    <O> nano out test HIGH
    <o> nano out test low
    <F> Find I2C device I2C scan
    <R> I2C recovery
    <c> I2C crash
    <a> for Ip address
    <w> for WiFi.printDig function
    <z> display credetial file
    <L> _newSoftAP_SSID> write SoftAP SSID in credentials WARNING
    <l> _wifiPass> write soft AP password in credentials WARNING
    <D> SPIFFS dir
    <j> display general part of config json file
    <d _filename> erase a file WARNING
    <e> display system status
    <p> display main power state
    <Volab setUp > Leds On config : -1
    <Volab setUp > Leds On lumi : 5
    <Volab setUp > [HTTP] begin...
    <Volab setUp > [HTTP] GET... http://www.google.fr/
    <Volab setUp > [HTTP] GET... code: 200
    <Volab setUp > Watchdog set to 10s with a refresh period to 5s
    <Volab setUp > Loop start

.. index::
    pair: Help; Commands

====================================================================================================
Serial command help
====================================================================================================
.. code::

    Serial Command list :
    <h> ou <H> display this list
    <E> display status
    <C> Check DS3231 date
    <S JJ/MM/AAAA HH:MM:SS> returns code <O>
    <T HH:MM:SS> returns code <O>
    <s> set DS3231 by NTP server
    <J> for display config.json
    <W> display WIFI mode
    <P key value> write config parameter in json WARNING
    <I _newSSID> write SSID in credentials WARNING
    <i _wifiPass> write password in credentials WARNING
    <t various_param> for code test
    <N> nano IO expander test
    <O> nano out test HIGH
    <o> nano out test low
    <F> Find I2C device I2C scan
    <R> I2C recovery
    <c> I2C crash
    <a> for Ip address
    <w> for WiFi.printDig function
    <z> display credetial file
    <L> _newSoftAP_SSID> write SoftAP SSID in credentials WARNING
    <l> _wifiPass> write soft AP password in credentials WARNING
    <D> SPIFFS dir
    <j> display general part of config json file
    <d _filename> erase a file WARNING
    <e> display system status
    <p> display main power state

====================================================================================================
Weblinks
====================================================================================================

.. target-notes::

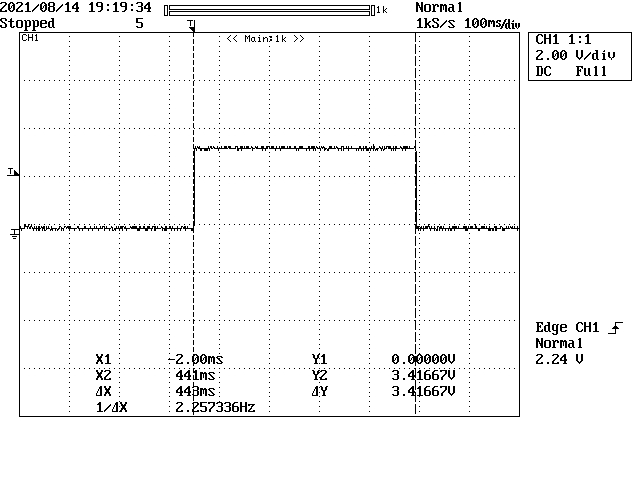
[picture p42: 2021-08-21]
_1_userDoc/source/image/handleHtmlParamManualMode443ms.JPG

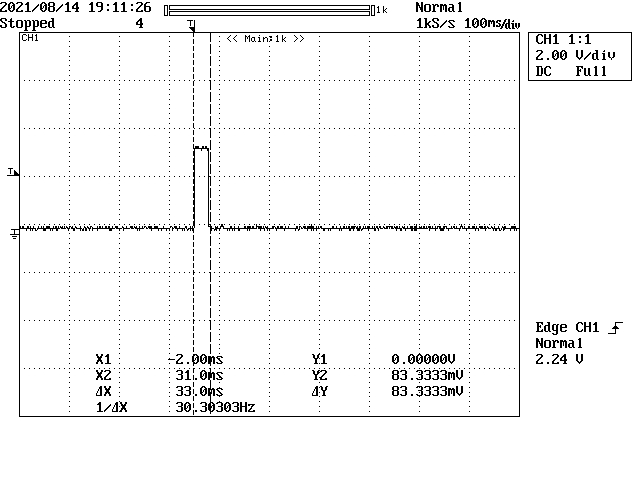
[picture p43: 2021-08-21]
_1_userDoc/source/image/plugOnOff_33ms_withoutDebugPrints.JPG

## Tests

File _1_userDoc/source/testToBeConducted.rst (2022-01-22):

++++++++++++++++++++++++++++++++++++++++++++++++++++++++++++++++++++++++++++++++++++++++++++++++++++
Liste of tests to be conducted
++++++++++++++++++++++++++++++++++++++++++++++++++++++++++++++++++++++++++++++++++++++++++++++++++++

:Auteur: J.Soranzo
:Date de création: 01/2022
:Date dernière maj: 08/01/2022
:Societe: VoRoBoTics
:Entity: VoLAB

.. contents::
    :backlinks: top

.. _testToBeConducted:

====================================================================================================
Presentation
====================================================================================================
The idea is to write a copy of this section each time a complete test is made.

====================================================================================================
The list
====================================================================================================
- ap mode
    - change ssid
    - change password
    - plug test
    - dhcp vs ip fixe test

- station mode
    - Check json file after each test below

    - only on one plug (plug test)
        - manual mode on / off /on /off
        - manual mode with hfin
        - manual mode with on duration
        - timer mode
        - timer mode restart with bp
        - timer mode differed start with button
        - cycle mode
        - cycle mode with diff start HH:Memory
        - cycle mode pause from web interface
        - cycle mode pause with push button
        - hebdo mode few days (first and last day)
        - hebdo all days
        - hebdo pause from web interface
        - hebdo pause with push button

- power loosing / restaure state

- leds switch off time

- errors

- with push Button
    - basic on/offs
    - push button to force manual mode (handleBpLongClic)

- special push button test

- power switch off 
- power switch on

- master json corruption

- ... TBC

----------------------------------------------------------------------------------------------------

.. WARNING::

    hebdo modes are difficult to test cause we need to wait few days to check the result !!!
    We need to find a solution

====================================================================================================
08/01/2022 test
====================================================================================================
Basic test in ap mode from web interface only conducted on green plug only

- station mode
    - ...

    - only on one plug (plug test)
        - manual mode on / off /on /off **OK**
        - manual mode with hfin **OK**
        - manual mode with on duration
        - timer mode stay in mode and keep time after elapsed time **OK**
        - timer mode restart with bp on green plug **OK**
        - timer mode differed start with button
        - cycle mode
        - cycle mode with diff start HH:Memory
        - cycle mode pause from web interface
        - cycle mode pause with push button
        - hebdo mode few days (first and last day)
        - hebdo all days
        - hebdo pause from web interface
        - hebdo pause with push button

- power loosing / restaure state

- with push Button
    - basic on/offs
        - green **OK**
        - red **repared**
        - yelow and bleu **PERMUTED**
    - push button to force manual mode

====================================================================================================
Weblinks
====================================================================================================

.. target-notes::

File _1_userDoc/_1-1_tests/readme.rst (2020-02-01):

An Excel file that list all tests (with their results) and all error and their handling

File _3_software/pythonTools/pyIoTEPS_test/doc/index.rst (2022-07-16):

.. IHM Test RDC Capteurs documentation master file, created by
   sphinx-quickstart on Tue Mar 16 09:38:17 2021.
   You can adapt this file completely to your liking, but it should at least
   contain the root `toctree` directive.

++++++++++++++++++++++++++++++++++++++++++++++++++++++++++++++++++++++++++++++++++++++++++++++++++++
Documentation IHM Test RDC Capteurs
++++++++++++++++++++++++++++++++++++++++++++++++++++++++++++++++++++++++++++++++++++++++++++++++++++

.. toctree::
    :maxdepth: 2
    :caption: Contents:

    main
    Uis
    Trames

====================================================================================================
Indices and tables
====================================================================================================

* :ref:`genindex`
* :ref:`modindex`
* :ref:`search`

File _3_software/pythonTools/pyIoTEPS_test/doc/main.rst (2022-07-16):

====================================================================================================
TKinter
====================================================================================================
`Site officiel : tkinter`_

.. _`Site officiel : tkinter` : https://docs.python.org/fr/3/library/tkinter.html

`Doc de l'universitéé du nouveau Mexique`_

.. _`Doc de l'universitéé du nouveau Mexique` : https://anzeljg.github.io/rin2/book2/2405/docs/tkinter/tkinter.pdf

====================================================================================================
Main
====================================================================================================

.. automodule:: main

.. autofunction:: main

====================================================================================================
CRdcGui
====================================================================================================

.. automodule:: CRdcGui

.. autoclass:: CRdcGUI
    :members:
    :undoc-members:

====================================================================================================
FrameControles
====================================================================================================

.. automodule:: GuiFrameControles

.. autoclass:: CFrameControles
    :members:
    :undoc-members:

.. target-notes::

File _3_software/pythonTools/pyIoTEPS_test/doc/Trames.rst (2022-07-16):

====================================================================================================
Les classes de gestions de la trame
====================================================================================================

.. automodule:: Trame
    :members:
    :undoc-members:

Trame Baro
====================================================================================================

.. automodule:: TrameBaro
    :members:
    :undoc-members:

Trame Pito
====================================================================================================

.. automodule:: TramePitot
    :members:
    :undoc-members:

Trame Tlm
====================================================================================================

.. automodule:: TrameTlm
    :members:
    :undoc-members:

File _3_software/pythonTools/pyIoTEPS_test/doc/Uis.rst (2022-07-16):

====================================================================================================
Modules interface graphique
====================================================================================================
Documentation des modules d'interfaces graphiques

GuiFrameBaro
====================================================================================================

.. automodule:: GuiFrameBaro
    :members:
    :undoc-members:

GuiFrameCalMag
====================================================================================================

.. automodule:: GuiFrameCalMag
    :members:
    :undoc-members:

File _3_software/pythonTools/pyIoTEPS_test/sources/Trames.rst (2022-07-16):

====================================================================================================
Modules de décodage des trames
====================================================================================================
Ces modules et classes décode les trames en provenance de Rdc Capteur

====================================================================================================
TrameBaro
====================================================================================================

.. automodule:: TrameBaro

.. autoclass:: BaroDataValue
    :members:
    :undoc-members:

TramePitot
====================================================================================================
  
.. automodule:: TramePitot
    :members:
    :undoc-members:

TrameTlm
====================================================================================================

.. automodule:: TrameTlm
    :members:
    :undoc-members:

TrameMag
====================================================================================================

.. automodule:: TrameMag
    :members:
    :undoc-members:

TrameAlim
====================================================================================================

.. automodule:: TrameAlim
    :members:
    :undoc-members:

====================================================================================================
Trame
====================================================================================================

.. automodule:: Trame
    :members:
    :undoc-members:

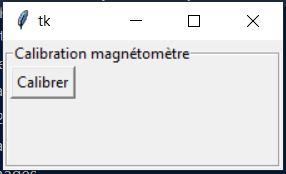
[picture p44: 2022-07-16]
_3_software/pythonTools/pyIoTEPS_test/doc/images/guiCalMag.jpg

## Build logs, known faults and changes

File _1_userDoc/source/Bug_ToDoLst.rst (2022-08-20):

+++++++++++++++++++++++++++++++++++++++++++++++++++++++++++++++++
Bug et ToDo-list
+++++++++++++++++++++++++++++++++++++++++++++++++++++++++++++++++

====================================================================================================
Déscription
====================================================================================================

    Dans ce fichier sont renseignés les bugs identifiés et la liste des choses à faire.
    
    #. Bugs identifiés
    
        A chaque fois qu'un bug est identifés, il doit être renseigner ici si il ne fait
        pas l'objet d'un traitemant immédiat.
        
    #. ToDo-list
    
        Ici doivent être renseigner la liste des tâches à faire. Il s'agit souvent de
        petites choses à fort potentiel d'oublie ou des tâches qui ne peuvent pas faire
        l'objet d'un traitemant immédiat.
        
.. WARNING::
    Cette liste est renseignée manuellement. Ne pas oublier le To do list du code source C++
    `<codeDoc\\html\\index.html>`_

====================================================================================================
Model Type
====================================================================================================

    :Date de saisie:        Date à laquelle la problématique à été identifiée
    :Date de traitemant:    Date du traitement de la probélmatique
    :Cible:                 [userDoc, modelisation, software, PCB, autre]
    :Status:                [NONE, WIP, DONE]
    :Problematique:         Déscriptif de la problématique
    :Traitement:            Déscriptif du traitement de la probélmatique

----------------------------------------------------------------------------------------------------

====================================================================================================
Open bugs
====================================================================================================

**BUG** : change time zone
----------------------------------------------------------------------------------------------------

    :Date de saisie:    15/06/2022    
    :Date de traitement:    
    :Cible:             firmware
    :Status:            **CLOSED**    
    :Problématique:     When i change summer time display time  error by command <C> is 3600 and 
                        DS3231 time is not updated. command <s> can be used to force ds3231 update 
                        by NTP
                        
    :Traitement:        it is not a bug DS3231 update period is #define RTC_UPDATE_PERIOD 15 //every 15mn

**BUG** : on Web Page Hebdo mode H-fin
----------------------------------------------------------------------------------------------------

    :Date de saisie:    11/06/2022    
    :Date de traitement:    
    :Cible:             Web interface
    :Status:            **OPEN**    
    :Problématique:     in hebdo Mode hebdo on the web page  On time nor off time are not displayed 
                        
    :Traitement:        
                        
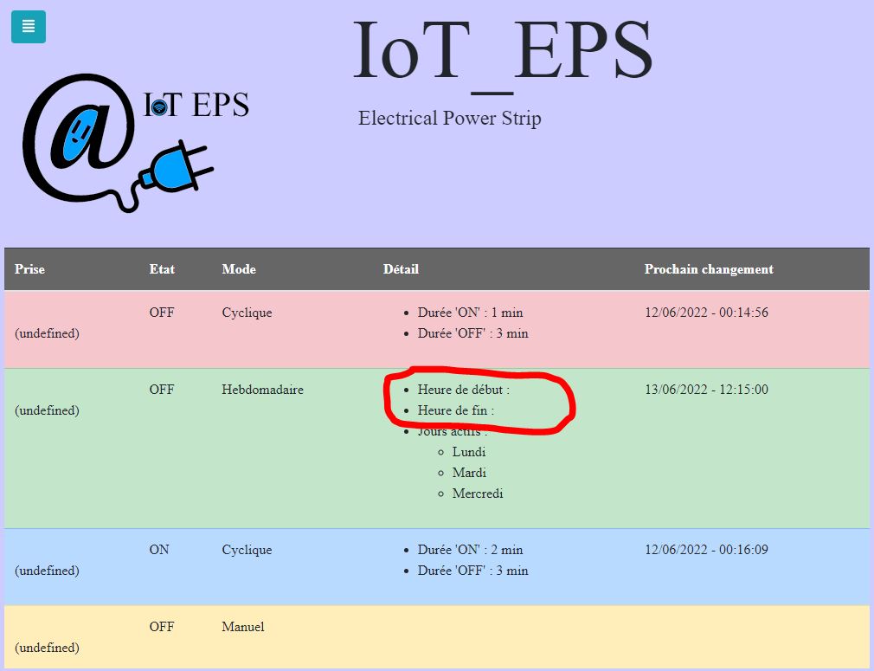
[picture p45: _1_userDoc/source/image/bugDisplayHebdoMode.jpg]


------------------------------------------------------------------------------------------

**BUG** : untimely switching
----------------------------------------------------------------------------------------------------

    :Date de saisie:    18/01/2022    
    :Date de traitement:    15/06/2022
    :Cible:             firmware
    :Status:            **OPEN**    
    :Problématique:     during a long test blue plug cycle on/off 3mn suddenly yellow and green 
                        switch ON but in JSON there are in manual off state
    :Traitement:        see :ref:`here<refBugUntimelySwitching>`

------------------------------------------------------------------------------------------

**BUG** : wrong global table refresh
----------------------------------------------------------------------------------------------------

    :Date de saisie:    191225    
    :Date de traitemant:    
    :Cible:             software / IHM
    :Status:            **OPEN**    
    :Problematique:     le tableau de synthèse ne se met pas à jour quand il y a un changement d'état d'une prise    
    :Traitement:        Le touche F5 n'est pas une solution, renvoie également la dernière commande !

------------------------------------------------------------------------------------------

**BUG** : cfgpage / cfgsend
----------------------------------------------------------------------------------------------------

    :Detection date:   23/10/21
    :Resolution date:  
    :Target:           firmware
    :Status:           **OPEN**
    :Problem:         /cfgpage after cfgpage send the link in browser turn to /cfgsend du to usage 
                      of send button. This behavior is normal. But we refresh the page with new
                      values and if user use the resend button from the browser he resend the same
                      page. Not realy a bug but not very clean.
                      **More** Add to this page, there is no return to home button
    :Traitement:

----------------------------------------------------------------------------------------------------

**BUG** : Change SSID in APmode from web page
----------------------------------------------------------------------------------------------------

    :Detection date:   03/08/22
    :Resolution date:  
    :Target:           Web interface
    :Status:           **OPEN**
    :Problem:         After send credential : return to the page index of the station mode
    :Traitement:

----------------------------------------------------------------------------------------------------

**BUG** : clone pause
----------------------------------------------------------------------------------------------------

    :Date de saisie:        210718
    :Date de traitemant:    
    :Cible:                 firmware
    :Status:                **OPEN**
    :Problematique:         Bug not confirmed but in CPowerPlug::handleHtmlReq in mode cloned
    :Traitement:
    
    ::

        test pause before to call on or off method (about line 601) write
        if (_state && !_pause) but move line ``_pause = clonedPlug.getPause();``
        before

----------------------------------------------------------------------------------------------------

====================================================================================================
Open todo
====================================================================================================

ToDo : timezone
----------------------------------------------------------------------------------------------------

    :Date de saisie:        17/08/2022
    :Date de traitemant:    
    :Cible:                 firmware/web
    :Status:                **OPEN**
    :Problematique:         provide a way in the config page to select timezone. 
    :Traitement:            

------------------------------------------------------------------------------------------

ToDo : Automatic adaptation to summer time
----------------------------------------------------------------------------------------------------

    :Date de saisie:        17/08/2022
    :Date de traitemant:    
    :Cible:                 firmware/web
    :Status:                **OPEN**
    :Problematique:         Auto adapt to summer/winter time. 
    :Traitement:            

------------------------------------------------------------------------------------------

ToDo : clear all led at the beginning of setup()
----------------------------------------------------------------------------------------------------

    :Date de saisie:        05/02/2022
    :Date de traitemant:    
    :Cible:                 firmware
    :Status:                **OPEN**
    :Problematique:         clear all LED at the beginning of the setup. 
    :Traitement:            

------------------------------------------------------------------------------------------

ToDo : oled display error
----------------------------------------------------------------------------------------------------

    :Date de saisie:        15/01/2022
    :Date de traitemant:    
    :Cible:                 firmware
    :Status:                **OPEN**
    :Problematique:         roll through errors AND plugs mode not only on errors. 
    :Traitement:            Use the lign AP to display Error

------------------------------------------------------------------------------------------

Todo : change behavior on fatal error
----------------------------------------------------------------------------------------------------

    :creation date:         11/12/2021
    :Date of treatment:    
    :Cible:                 [software]
    :Status:                **OPEN**
    :Problem:               System sabord on fatal error and only blink led. This behavior prevent
                            us to diagnose problem.
    :Traitement:            Change this to only permit serial diag on fatal error.

----------------------------------------------------------------------------------------------------

ToDo : Pause display
----------------------------------------------------------------------------------------------------

    :Date de saisie:        08/01/2022
    :Date de traitemant:    
    :Cible:                 firmware
    :Status:                **OPEN**
    :Problematique:         display pause on oled screen. 
    :Traitement:            

------------------------------------------------------------------------------------------

ToDo : minify javascripts
----------------------------------------------------------------------------------------------------

    :Date de saisie:        210821
    :Date de traitemant:    
    :Cible:                 Data/javascript
    :Status:                **OPEN**
    :Problematique:         reduce the size of the web files. Reduce the size of the logo.
    :Traitement:            

------------------------------------------------------------------------------------------

ToDo : doxy HTML js
----------------------------------------------------------------------------------------------------

    :Date de saisie:        181214
    :Date de traitemant:    
    :Cible:                 software
    :Status:                **OPEN**
    :Problematique:         Use Doxigen on HTML et JS codes.
    :Traitement:            

------------------------------------------------------------------------------------------

ToDo : file names coherence
----------------------------------------------------------------------------------------------------

    :Date de saisie:        181214
    :Date de traitemant:    
    :Cible:                 software
    :Status:                **OPEN**
    :Problematique:         Faire correspondre dans index.html, style.css et dans IoT_EPS2.js les
                            noms utilisés avec ceux définis dans configFile3.json.
    :Traitement:            

------------------------------------------------------------------------------------------

====================================================================================================
Closed bug
====================================================================================================
**BUG** :  Bug Main PowerOff
----------------------------------------------------------------------------------------------------

    :Date de saisie:    13/03/2022    
    :Date de traitement:    start on 9/4/2022 see :ref:`here<refCorBugMainPowerOff>`
    
    :Cible:             firmware
    :Status:            [CLOSED]   
    :Problem:           after a power off/power on plugs are in ON state. Opérations made with
                        web browser in ap mode 

    :Traitement:        In Main loop ligne 582 : if ( !mainPowerSwitchState) in this if there is no
                        call to jsonData.storeJson(); and yield function wait for a restart !!!!
                        One lien added !

**BUG** : push button permuted on yellow and green
----------------------------------------------------------------------------------------------------

    :Date de saisie:    08/01/2022    
    :Date de traitemant: 08/06/2022
    :Cible:             hardware
    :Status:            [CLOSED]   
    :Problematique:     cabling is good !

    :Traitement:        **reroute the board**  

**BUG** : Allumage intempestif 
----------------------------------------------------------------------------------------------------

    :Date de saisie:        191225     
    :Date de traitemant:    
    :Cible:                 firmware
    :Status:                [CLOSED]
    :Problematique:         Au cours des essais 2 prises bleu et jaune se sont retrouvé allumées alors
                            que dans le json elles étaient off !
    :Traitement:            closed with no suite - not reproduced

------------------------------------------------------------------------------------------

**BUG** : internet error
----------------------------------------------------------------------------------------------------

    :Date de saisie:    15/01/2022    
    :Date de traitemant:    15/01/2022
    :Cible:             firmware
    :Status:            [CLOSED]    
    :Problematique:     When internet error is rise, it stay true even if internet connection 
                        return good

    :Traitement:         include in a large brainstorming about error but for now just else added 
                         in the main loop  

----------------------------------------------------------------------------------------------------

**BUG** : corrupted value of on/off counter
----------------------------------------------------------------------------------------------------

    :Date de saisie:    08/01/2022    
    :Date de traitemant: 15/01/2022
    :Cible:             firmware
    :Status:            [closed]   
    :Problematique:     after somme tests values of all counter are very stranges. only those in the configFile3
                        seams to be right. I don't know exactly when.
    :Traitement:        git branch "bug_on_off_count"
                        bug is in handlebpclic when main power switch is off CJsonIotEps::loadJsonPlugParam 
                        does not load counter value and handlebpclic request a write to json so an
                        uninitialized value is write in the file.
                        There is a huge complicated action suite.
                        Tips : rethink the whole sequence. 

------------------------------------------------------------------------------------------

**BUG** : cfgpage
----------------------------------------------------------------------------------------------------

    :Date de saisie:        21/08/21
    :Date de traitemant:    16/10/21
    :Cible:                 firmware
    :Status:                [closed]
    :Problematique:         /cfgpage : faile to load json param!
    :Traitement:
    
    ::

        Free memory analyse was conducted. memory managment improvement was introduced.

----------------------------------------------------------------------------------------------------

**BUG** soft AP fail
----------------------------------------------------------------------------------------------------

    :Date de saisie:        210627      
    :Date de traitemant:    210630
    :Cible:                 firmware
    :Status:                [closed]
    :Problematique:         Soft AP fails
    :Traitement:            Set Arduino IDE/ESP in Wifi debug mode has correct the problem !!!

------------------------------------------------------------------------------------------

**BUG** : oled do not display system error
----------------------------------------------------------------------------------------------------

    :Detection date:   11/12/21
    :Resolution date:  18/12/2021
    :Target:           firmware
    :Status:           [closed]
    :Problem:         When system error oled display blank line
                      
    :Traitement:      local branch oled-display-error-bug

----------------------------------------------------------------------------------------------------

**BUG** : watchdog ok
----------------------------------------------------------------------------------------------------

    :Detection date:   05/12/2021
    :Resolution date:  15/12/2021
    :Target:           firmware
    :Status:           [closed]
    :Problem:         There is no  watchdog component in the system and system always displays 
                      watchdog ok !!!
                      
    :Traitement:        Watch dog display ok on oled cause  normaly wd error is a fatal error that
                        sabord the system and it does not reach the line where it is displayed but
                        with the no_sabord option system reach the line.
                        insert a new parameter NBR_OF_SYSTEM_ERROR and a new table of error

----------------------------------------------------------------------------------------------------

**BUG** : Manual after cycle ON Hfin 
----------------------------------------------------------------------------------------------------

    :Date de saisie:    22/01/2022    
    :Date de traitemant:    start on 09/04/2022 see :ref:`here<refBugCorrectionManualCycleHfin>`
    
    :Cible:             firmware
    :Status:            [CLOSED]   
    :Problematique:     Set manual mode ON after a cycle mode Hfin param not set to 0 or the right 
                        value
                        
    :Traitement:        in ``void CPowerPlug::handleHtmlReq( String allRecParam )`` 

----------------------------------------------------------------------------------------------------

====================================================================================================
Closed todo
====================================================================================================
ToDo : web caching
----------------------------------------------------------------------------------------------------

    :Date de saisie:        12/01/2022
    :Date de traitemant:    
    :Cible:                 firmware
    :Status:                closed
    :Problematique:         caching file on browser. 
    :Traitement:            on local branch webCatching
            
https://github.com/esp8266/Arduino/issues/999

https://werner.rothschopf.net/microcontroller/202011_arduino_webserver_caching_en.htm

------------------------------------------------------------------------------------------

ToDo : online gh-page
----------------------------------------------------------------------------------------------------

    :Date de saisie:        181214
    :Date de traitemant:    
    :Cible:                 autre
    :Status:                closed
    :Problematique:         Créer la Branch 'gh-pages' pour y intégrer la documentation générer par
                            Sphinx et par Doxigen.
    :Traitement:            

------------------------------------------------------------------------------------------

.. _todocreateconfigfile:

ToDo : config.h
----------------------------------------------------------------------------------------------------

    :Date de saisie:        200703        
    :Date de traitemant:    11/12/2021
    :Cible:                 firmware
    :Status:                closed
    :Problematique:         Create config.h file with only #define
    :Traitement:            To separate from include files. To day there is only one file IoT_EPS.h
                            2 file created config and config_advanced 

----------------------------------------------------------------------------------------------------

Todo : Complete the CSystem class
----------------------------------------------------------------------------------------------------

    :Date de saisie:        11/09/2020
    :Date de traitemant:    10/02/2021
    :Cible:                 [software]
    :Status:                [closed]
    :Problematique:         Add all system servitude in this class
    :Traitement:            Move code froom .ino to this code

----------------------------------------------------------------------------------------------------

ToDo-list
----------------------------------------------------------------------------------------------------

    :Date de saisie:        
    :Date de traitemant:    
    :Cible:                 [userDoc, modelisation, software, PCB, autre]
    :Status:                
    :Problematique:         
    :Traitement:

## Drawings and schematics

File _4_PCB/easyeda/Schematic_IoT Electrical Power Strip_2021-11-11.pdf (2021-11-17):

## WARNING POWER SUPP RELAY

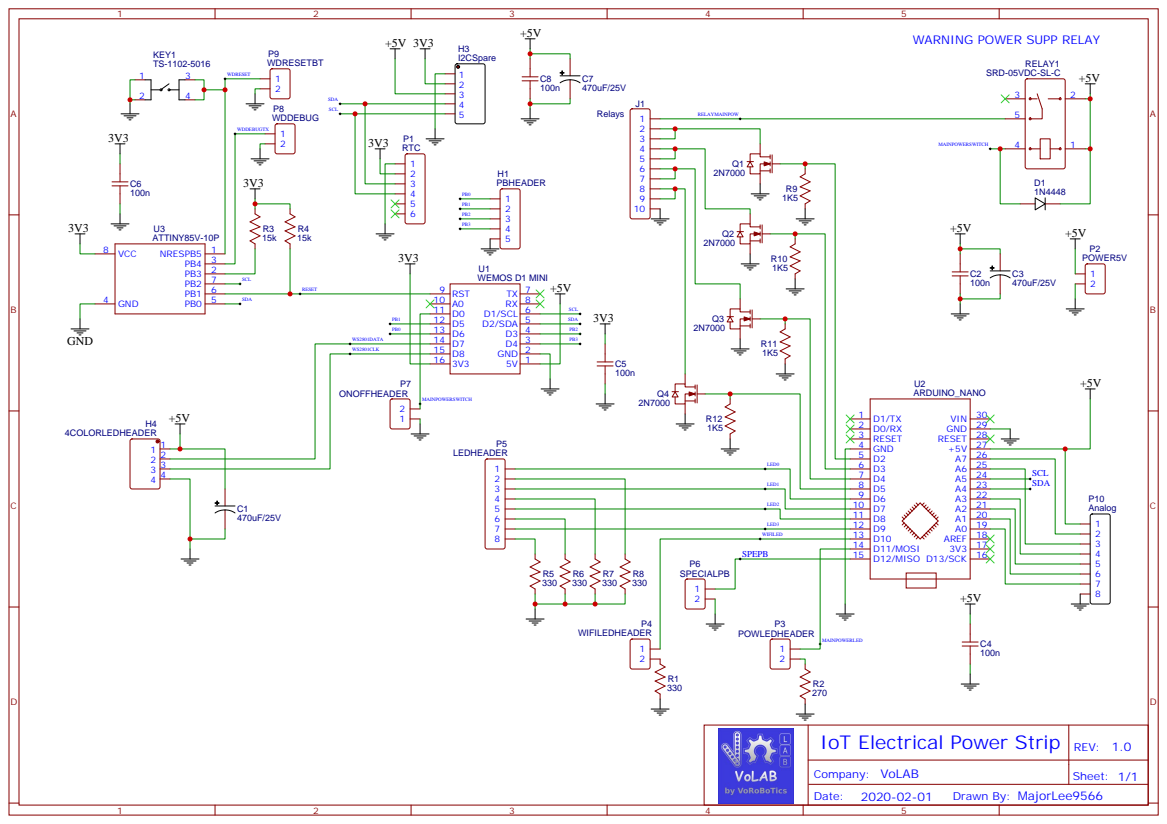
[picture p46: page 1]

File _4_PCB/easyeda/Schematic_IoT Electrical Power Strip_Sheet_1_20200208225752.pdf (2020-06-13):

## WARNING POWER SUPP RELAY

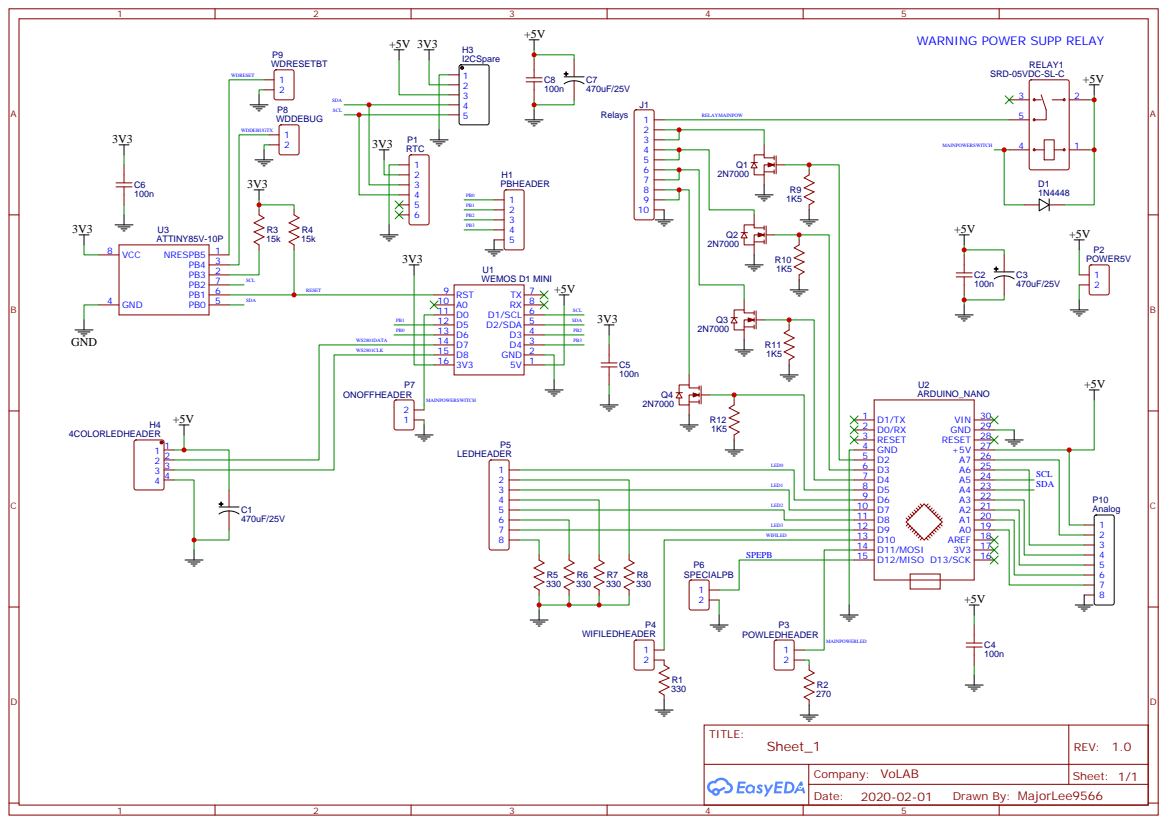
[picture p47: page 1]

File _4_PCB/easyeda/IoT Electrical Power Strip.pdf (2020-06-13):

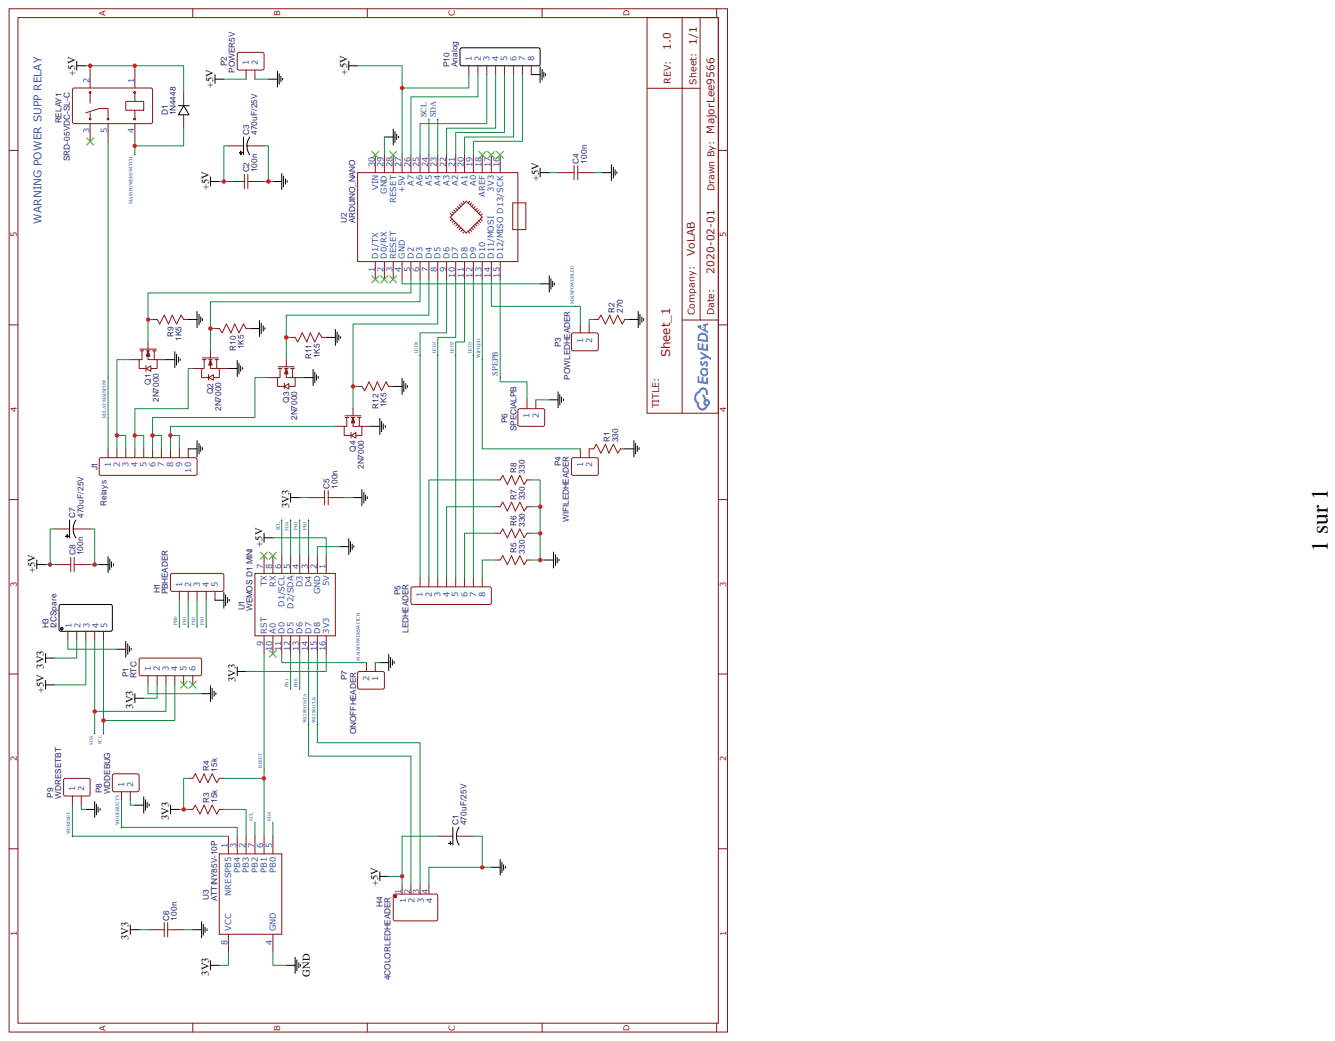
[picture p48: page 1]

WARNING POWER SUPP RELAY

D11/MOSI 14 D10 13 D9 12 D8 11 D7 10 D6 9 D5 8 D4 7 D3 6 D2 5 GND 4 RESET 3 D0/RX 2 D1/TX 1 VIN 30 GND 29 RESET 28 +5V 27 A7 26 A6 25 A5 24 A4 23 A3 22 A2 21 A1 20 A0 19 AREF 18 3V3 17

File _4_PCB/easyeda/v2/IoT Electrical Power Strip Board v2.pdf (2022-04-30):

+5V

3V3

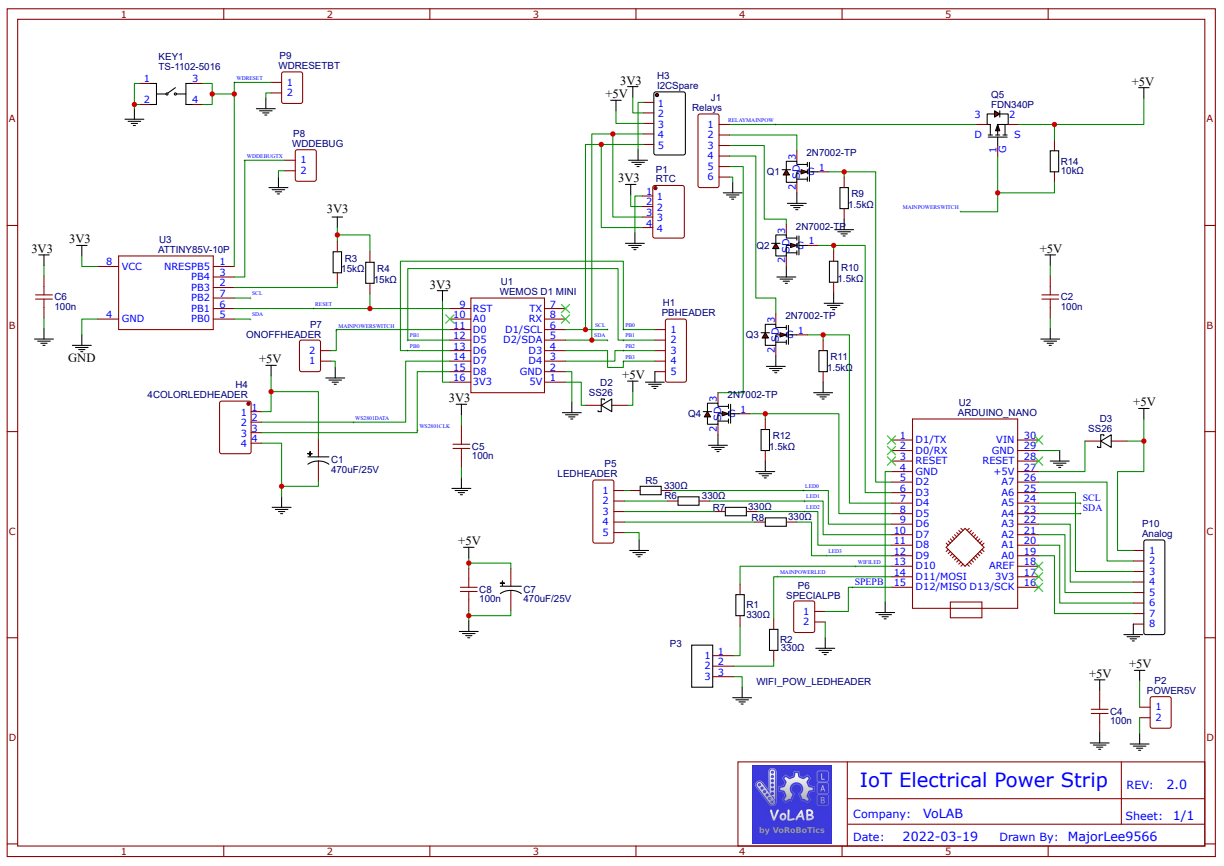
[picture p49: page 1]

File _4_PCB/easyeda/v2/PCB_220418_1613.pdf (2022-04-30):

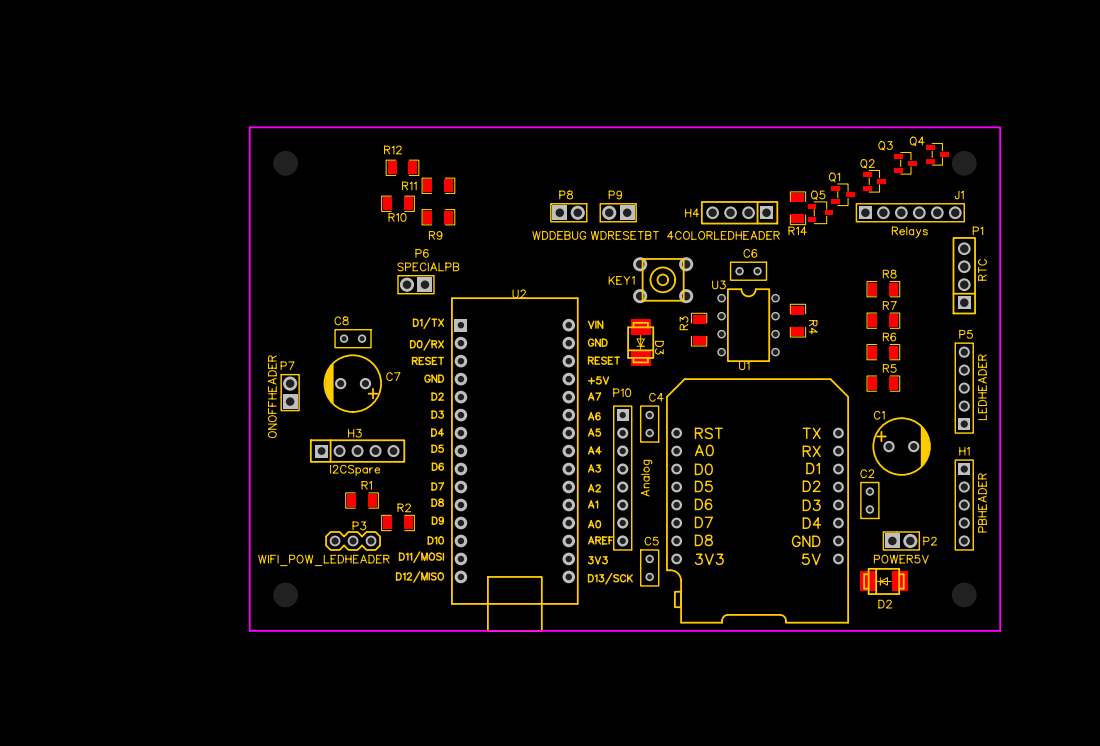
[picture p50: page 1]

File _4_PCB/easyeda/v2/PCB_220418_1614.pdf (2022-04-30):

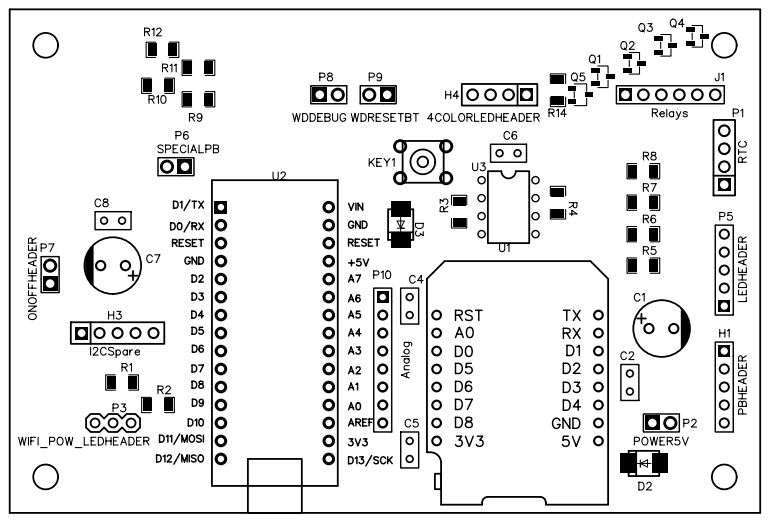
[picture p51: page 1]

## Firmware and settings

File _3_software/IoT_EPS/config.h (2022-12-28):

/**
* @file config.h
* @author J.SORANZO
* @date 08/12/2021
* @copyright 2021 CC0
* @brief all application parameters
*/

#ifndef _CONFIG_H
#define _CONFIG_H

/** @todo [NECESSARY]Passage heure d'hiver/été : soit automatique soit configurable via l'interface */
#define DEFAULT_PREFIX_NAME "ESP_IOT"


#define JSON_TAG "IoTEps"
#define JSON_VERSION "v5.1"

#define NTPSERVER "fr.pool.ntp.org"
// #define OFFSET_HEURE 2 //ETE
#define OFFSET_HEURE 1 //Hiver

#define DEFAULT_LED_LUMINOSITY 15
#define FLASH_ERROR_PERIODE 500 //ms

#define INTERNET_HEALTH_TARGET "http://www.google.fr/"

#define OLED_I2C_ADD 0x3C
/*
    Scanning (SDA : SCL) - GPIO4 : GPIO5 - 
    I2C device found at address 0x26  !
    I2C device found at address 0x3C  !
    I2C device found at address 0x53  !
    I2C device found at address 0x58  !
    I2C device found at address 0x68  !
    

- watchdog : 0x26 (defined in cattiny_i2C_watchdog.h)
- ioexpender : 0x58 (ored with D13) - defined in the ARDUINO NANO code
- DS3231 : 0x68 defined in RTClib.h
- +EEPROM on DS3231 1010011 normaly 0x53 base add is 0x50 and I have solder A2 slot
there is 3 pull-up on the board.
*/

#define OLED_REFRESH_PERIOD 1 //in seconds
#define OLED_SYSTEM_STATE_DISPLAY_DIV 2 //example 2*1s


#define RTC_UPDATE_PERIOD 15 //every 15mn
// #define RTC_UPDATE_PERIOD 1 //every 1

#define RTC_ALLOWED_TIME_ERROR 20//seconds
#define I2C_CBIT_TEST_PERIOD 60 * 1000 //ms it smells millis() ;-)
#define I2C_RETRIES 5
#define CBIT_TIME 60000 // period of CBIt in ms

#define DEFAULTIPADD "192.168.95.42"
#define NBRPLUGS 4
#define NUM_LEDS NBRPLUGS /**< for fastLED class */

#define COLOR_LED_ERROR_PERIOD 300 //ms

#define OLED_SHUTDOWN_MESSAGE "Shutdown Started !"

#endif

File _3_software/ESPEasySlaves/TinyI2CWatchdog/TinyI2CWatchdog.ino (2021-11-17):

// Tiny85 as I2C Watchdog / Busmonitor
// Version 0.1, 2016-01-08 

// Uses a customized TinyWire Slave library that does not hang on persistent SDA low conditions
//   - With this library, the MCU main sketch can still monitor I2C bus signal levels,
//       instead of hanging within the ISR routine
//   - Without this custom library, the MCU would not be able to reset the target if this happens
//
// This sketch also uses customized Software Serial code:
//   - Smaller size than the full librarym but TX only
//   - TX without IRQ blocking as it interferes sometimes with I2C traffic
//   - Serial debug can get garbled sometimes due to non IRQ blocking (but I2C is more important)
//==============================================================================================================
// ATMEL ATTINY85 GENERIC PINOUTS
//                          o-\/-+ 
//                  Reset  1|    |8  VCC 
//              D3/A3 PB3  2|    |7  PB2 D2/A1/I2C-SCL
//              D4/A2 PB4  3|    |6  PB1 D1/PWM1
//                    GND  4|    |5  PB0 D0/PWM0/I2C-SDA
//                          +----+ 
//==============================================================================================================

//==============================================================================================================
// ATMEL ATTINY85 PINOUTS used for watchdog purpose
//                          o-\/-+ 
//                  Reset  1|    |8  VCC 
//      Factory Reset Pin  2|    |7  I2C-SCL to ESP
//      (debug) Serial TX  3|    |6  Reset output to ESP
//                    GND  4|    |5  I2C-SDA to ESP
//                          +----+ 
//==============================================================================================================

// I2C command structure uses one or two bytes:
// 
//   <cmd>,[value]
//
// Commands below 0x80 are used to write data to register in settings struct
//
// Commands starting at 0x80 are special commands:
// Command 0x80 = store settings to EEPROM
// Command 0x81 = reset to factory default settings
// Command 0x82 = set I2C address, factory default = 0x26
// Command 0x83 = set pointer to settings struct for I2C readings
// Command 0x84 = reset statistics counters
// Command 0x85 = simulate (test) watchdog timeout
// Command 0xA5 = reset watchdog timer value to 0
//

#define SWSERIALDEBUG true
#define SWSERIAL false

#if SWSERIALDEBUG
#define SERIAL_TX_PIN 4
#endif

#if SWSERIAL
#include <SoftwareSerial.h>
//SoftwareSerial Serial(3,4);         // RX, TX
#endif

#include "TinyWireS_Custom.h"
#include <EEPROM.h>

#define PROJECT_PID               2015123101L //781C 569D en hexa
#define VERSION                             1
#define BUILD                               1

#define RESET_CAUSE_TIMEOUT                 1

struct SettingsStruct
{
  unsigned long PID;                        // (B0-3) 4 byte ID, wipes eeprom if missing
  int           Version;                    // (B4/5) Version, change if struct changes, wipes eeprom
  byte          TimeOut;                    // (B6)   Timeout in seconds
  byte          Action;                     // (B7)   Action on timeout, 1 = reset target
  byte          ResetPin;                   // (B8)   Reset output pin to toggle
  byte          Sleep;                      // (B9)   After reset, do nothing for x seconds
  byte          I2CAddress;                 // (B10)  Listen to this I2C Address (0x26 default)
  byte          I2CLoadThreshold;           // (B11)  Threshold for I2C bus load
  byte          ResetCounter;               // (B12)  Seconds counter for WD reset status
  byte          SleepCounter;               // (B13)  Seconds counter for sleep time
  byte          TargetResetCount;           // (B14)  Counts number of target resets
  byte          I2CBusInitCount;            // (B15)  Counts I2C bus init calls
  byte          I2CBusErrorCount;           // (B16)  Counts I2C bus threshold exceptions
  byte          Status;                     // (B17)  Status byte
  byte          LastResetCause;             // (B18)  Last reset cause code
} 
Settings;

unsigned long timer1Sec=0;                  // Timer triggers each second for WD reset count
unsigned long timer100mSec=0;               // Timer triggers 10 times/second, check I2C bus levels
volatile byte I2CBuffer[16];                // Buffer to store incoming I2C message
volatile byte I2CReceived=0;                // flag, will be set if I2C message received
unsigned long I2CActive;                    // Count active signal on I2C bus
unsigned long I2CIdle;                      // Count inactive signal on I2C bus
byte settingsPointer = 0;                   // pointer to specifig location in the settings struct

void(*Reset)(void)=0;
volatile uint8_t *receivePortRegister;

/********************************************************************************************\
 * Main setup routine 
 \*********************************************************************************************/
void setup(){
#if SWSERIAL
    Serial.begin(9600);
#endif

#if SWSERIALDEBUG
    SoftwareSerial_init(SERIAL_TX_PIN);
#endif

    LoadSettings();
    if (Settings.Version != VERSION || Settings.PID != PROJECT_PID){
#if SWSERIAL
        Serial.print(F("\nPID:"));
        Serial.println(Settings.PID);
        Serial.print(F("Version:"));
        Serial.println(Settings.Version);
        Serial.println(F("INIT : Incorrect PID or version!"));
#endif
        tws_delay(1000);
        ResetFactory();
    }

#if SWSERIAL
    Serial.println(F("\nTiny WD Boot...\n"));
    Serial.print(F("Free RAM  : "));
    Serial.println(freeRam());
    Serial.print(F("Timeout   : "));
    Serial.println(Settings.TimeOut);
    Serial.print(F("Action    : "));
    Serial.println(Settings.Action);
    Serial.print(F("Resetpin  : "));
    Serial.println(Settings.ResetPin);
    Serial.print(F("I2CAddress: "));
    Serial.println(Settings.I2CAddress, HEX);
#endif

#if SWSERIALDEBUG
    SoftwareSerial_println("Boot");
#endif

    pinMode(3, INPUT); 
    pinMode(4, OUTPUT);

    // if pin 3 held low for > 10 seconds after boot, perform hard reset!
    byte factoryResetCount = 0;
    while (digitalRead(3) == 0){
        factoryResetCount++;
        tws_delay(100);
        if (factoryResetCount > 100){
        #if SWSERIALDEBUG
          SoftwareSerial_println("Hard Reset");
        #endif
          ResetFactory();
        }
    }

    TinyWireS.begin(Settings.I2CAddress);
    TinyWireS.onRequest(requestEvent);
    TinyWireS.onReceive(receiveEvent);

    uint8_t port = digitalPinToPort(0);
    receivePortRegister = portInputRegister(port);

    timer1Sec = millis() + 1000;
    timer100mSec = millis() + 100;

    Settings.ResetCounter = 0;
    Settings.SleepCounter = 0;
    Settings.Status = 0;
}


/********************************************************************************************\
 * Main program loop 
 \*********************************************************************************************/
void loop(){
    if (I2CReceived) I2CCommand();

    if((*receivePortRegister & 0x5) != 5) I2CActive++;
    else I2CIdle++;
    
    // if (millis() > timer100mSec){
        // timer100mSec = millis() + 100;
        // checkI2Cbus();
    // }
    
    if (millis() > timer1Sec){
        timer1Sec = millis() + 1000;
        Settings.I2CBusInitCount = TinyWireS.initCount();
        if (Settings.SleepCounter > 0){
#if SWSERIAL
            Serial.print(F("Sleeping: "));
            Serial.println(int(Settings.SleepCounter));
#endif
            Settings.SleepCounter--;
        } else {
#if SWSERIAL
        Serial.print(F("ResetCounter: "));
        Serial.println(Settings.ResetCounter);
#endif
#if SWSERIALDEBUG
        SoftwareSerial_print("RC ");
        SoftwareSerial_print(int2str(Settings.ResetCounter));
        SoftwareSerial_print(" I ");
        SoftwareSerial_println(int2str(TinyWireS.initCount()));
#endif

        Settings.ResetCounter++;
        if ((Settings.TimeOut != 0) && (Settings.ResetCounter > Settings.TimeOut))
            timeOutAction();
        }
    }
    TinyWireS_stop_check();
}


/********************************************************************************************\
 * Check I2C bus load 
 \*********************************************************************************************/
void checkI2Cbus(){
    byte ratio = (100 * I2CActive) / (I2CIdle + I2CActive);
    if (ratio > 0){
#if SWSERIAL
        Serial.print(F("bus act: "));
        Serial.print(I2CActive);
        Serial.print(F(" idle: "));
        Serial.print(I2CIdle);
        Serial.print(F(" ratio: "));
        Serial.print(ratio);
        Serial.print(F(" I2C inits: "));
        Serial.println(TinyWireS.initCount());
#endif
    }
    I2CActive=0;
    I2CIdle=0;
    byte portState = *receivePortRegister & 0x5;

    if (ratio > Settings.I2CLoadThreshold){
#if SWSERIAL
        Serial.print(F("I2C bus: "));
        Serial.println(portState);
        Serial.println(F("Reset I2C due to I2C threshold"));
#endif
#if SWSERIALDEBUG
        SoftwareSerial_println("I2C Err");
#endif
        Settings.I2CBusErrorCount++;
        TinyWireS.begin(Settings.I2CAddress);
        TinyWireS.onRequest(requestEvent);
        TinyWireS.onReceive(receiveEvent);
    }    
}


/********************************************************************************************\
 * Check I2C incoming command and perform actions 
 \*********************************************************************************************/
void I2CCommand(){
#if SWSERIAL
    Serial.print(F("I2C bytes: "));
    Serial.print(I2CReceived);
    Serial.print(F( " Inits: "));
    Serial.print(TinyWireS.initCount());
    Serial.print(F( " cmd: "));
#endif
    if ((I2CBuffer[0] > 5) && (I2CBuffer[0] < sizeof(SettingsStruct))){
        byte *pointerToByteToSave = (byte*)&Settings + I2CBuffer[0];
        *pointerToByteToSave = I2CBuffer[1];
    } else {
        switch(I2CBuffer[0]){ 
            case 0x80:
                SaveSettings();
                break;
            case 0x81:
                ResetFactory();
                break;
            case 0x82:
                Settings.I2CAddress = I2CBuffer[1];
                TinyWireS.begin(Settings.I2CAddress);
                TinyWireS.onRequest(requestEvent);
                TinyWireS.onReceive(receiveEvent);
                break;
            case 0x83:
                settingsPointer = I2CBuffer[1];
                break;
            case 0x84:
                Settings.TargetResetCount = 0;
                Settings.I2CBusInitCount = 0;
                Settings.I2CBusErrorCount = 0;
                break;
            case 0x85:
                timeOutAction();
                break;
            case 0xA5:
                Settings.Status &= 0xFE; // reset bit 0, target reset state indicator
                Settings.ResetCounter = 0;
                break;
        }  // switch
    } // else

  I2CReceived = 0;
}


/********************************************************************************************\
 * Perform preprogrammed actions due to timeout on watchdog feed 
 \*********************************************************************************************/
void timeOutAction(){
  switch(Settings.Action){
  case 1:
#if SWSERIAL
      Serial.println(F("Resetting target!"));
#endif
      Settings.LastResetCause = RESET_CAUSE_TIMEOUT;
      resetTarget();
      break;
  }
}


/********************************************************************************************\
 * Reply to I2C read requests 
 \*********************************************************************************************/
void requestEvent(){
    byte *pointerToByteToRead = (byte*)&Settings + settingsPointer;
    TinyWireS.send(*pointerToByteToRead);
}

/********************************************************************************************\
 * Receive and store incoming I2C writes 
 \*********************************************************************************************/
void receiveEvent(uint8_t howMany){
    if (howMany > 16) return;
    I2CReceived = howMany;
    for(byte x=0; x < howMany; x++)
        I2CBuffer[x] = TinyWireS.receive();
}


/********************************************************************************************\
 * Reset target device using digital output pin, should connect to target's reset input pin
 * Signal is active low
 \*********************************************************************************************/
void resetTarget(){
    Settings.TargetResetCount++;
    Settings.Status |= 0x01; // set bit 0, reset state
    pinMode(Settings.ResetPin,OUTPUT);
    digitalWrite(Settings.ResetPin,LOW);
    tws_delay(500);
    digitalWrite(Settings.ResetPin,HIGH);
    pinMode(Settings.ResetPin,INPUT);
    Settings.ResetCounter=0;
    Settings.SleepCounter=Settings.Sleep;
}


/*********************************************************************************************\
 * Save settings to EEPROM memory.
 \*********************************************************************************************/
void SaveSettings(void){
  char ByteToSave,*pointerToByteToSave=pointerToByteToSave=(char*)&Settings;

  for(int x=0; x<sizeof(struct SettingsStruct) ;x++){
    EEPROM.write(x,*pointerToByteToSave); 
    pointerToByteToSave++;
  }  
}


/*********************************************************************************************\
 * Load settings from EEPROM memory.
 \*********************************************************************************************/
boolean LoadSettings(){
  byte x;
  char ByteToSave,*pointerToByteToRead=(char*)&Settings;
  for(int x=0; x<sizeof(struct SettingsStruct);x++){
    *pointerToByteToRead=EEPROM.read(x);
    pointerToByteToRead++;
  }
}


/********************************************************************************************\
 * Reset all settings to factory defaults
 \*********************************************************************************************/
void ResetFactory(void)
{
  Settings.PID              = PROJECT_PID;
  Settings.Version          = VERSION;
  Settings.TimeOut          = 20;
  Settings.Action           = 1;
  Settings.ResetPin         = 1;
  Settings.Sleep            = 20;
  Settings.I2CAddress       = 0x26;
  Settings.I2CLoadThreshold = 50;
  Settings.ResetCounter     = 0;
  Settings.SleepCounter     = 0;
  Settings.TargetResetCount = 0;
  Settings.I2CBusInitCount  = 0;
  Settings.I2CBusErrorCount = 0;
  Settings.Status           = 0;
  Settings.LastResetCause   = 0;
  SaveSettings();
  tws_delay(1000);
  Reset();
}


/********************************************************************************************\
 * Check free RAM 
 \*********************************************************************************************/
int freeRam() {
  extern int __heap_start, *__brkval; 
  int v; 
  return (int) &v - (__brkval == 0 ? (int) &__heap_start : (int) __brkval); 
}

char OutputLine[12];  // made global for both int2str and int2strhex, to save RAM.

/**********************************************************************************************\
 * Converteert een unsigned long naar een string met decimale integer.
 \*********************************************************************************************/
char* int2str(unsigned long x)
{
  //static char OutputLine[12];
  char* OutputLinePosPtr=&OutputLine[10];
  int y;

  *OutputLinePosPtr=0;

  if(x==0)
  {
    *--OutputLinePosPtr='0';
  }
  else
  {  
    while(x>0)
    {
      *--OutputLinePosPtr='0'+(x%10);
      x/=10;
    }
  }    
  return OutputLinePosPtr;
}

/**********************************************************************************************\
 * Converteert een unsigned long naar een hexadecimale string.
 \*********************************************************************************************/
char* int2strhex(unsigned long x)
{
  //static char OutputLine[12];
  char* OutputLinePosPtr=&OutputLine[10];
  int y;

  *OutputLinePosPtr=0;

  if(x==0)
  {
    *--OutputLinePosPtr='0';
  }
  else
  {  
    while(x>0)
    {
      y=x&0xf;

      if(y<10)
        *--OutputLinePosPtr='0'+y;
      else
        *--OutputLinePosPtr='A'+(y-10);

      x=x>>4;
      ;
    }
    *--OutputLinePosPtr='x';
    *--OutputLinePosPtr='0';
  }
  return OutputLinePosPtr;
}

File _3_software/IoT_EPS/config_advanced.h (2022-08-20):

/**
* @file config.h
* @author J.SORANZO
* @date 08/12/2021
* @copyright 2021 CC0
* @brief all application parameters
*/

#ifndef _CONFIG_ADVANCED_H
#define _CONFIG_ADVANCED_H

#include <WString.h>

#define CONFIGFILENAME "/config4.json"
#define DEFCONFIGFILENAME "/defConfig.json"
#define CREDENTIALFILENAME "/credentials.json"
#define CONFIGFILENAME_COPY1 "/config4copie1.json"
#define CONFIGFILENAME_COPY2 "/config4copie2.json"

#define FIRSTBOOTFORMFILENAME "/firstboot.htm"
#define CONFIGFORMFILENAME "/config_tag.htm"
#define APMODEINDEXPAGENAME "/apmodeindex.htm"
/** @todo [NECESSARY] (integration) replace config_tag.htm by the right file name and or the right file */

#define HTML_ALLARGS_SEPARATOR "|"
#define SECPERHOURS (int)3600

#define NOT_FOUND "nf" //return code for extractParam()

#define FLASHERTIME 500 //ms

#define PLUG0PIN 0 // MPC23017 numbering pin21 PORTA.0
#define PLUG1PIN 1
#define PLUG2PIN 2
#define PLUG3PIN 3
#define PLUG0_ONOFFLEDPIN 4
#define PLUG1_ONOFFLEDPIN 5
#define PLUG2_ONOFFLEDPIN 6
#define PLUG3_ONOFFLEDPIN 7

#define DATA_PIN D7 /**< for fastLED class strip data pin*/
#define CLOCK_PIN D8 /**< for fastLED class strip data pin*/

// #define MAINSWITCHPIN 8 //nanoI2CIOExpander pin D10
#define MAINSWITCHPIN D0 //Direct on ESP pin
#define SPECIALBP 10 //to ask plug state
#define MAINPOWLED 9 //nanoI2CIOExpander pin D11

#define BP0 D6 
#define BP1 D5
#define BP2 D4
#define BP3 D3

#define WIFILED 8 //nanoI2CIOExpander pin D10
#define WIFILED_FLASH_FAST 100
#define WIFILED_FLASH_SLOW 500
#define WIFILED_FLASH_COUNT 20
#define WIFILED_SOFTAP_FLASH 50
#define WIFILED_SOFTAP_PERIOD 2000

#define OLED_XPOS_STARTLIGN 6
#define OLED_YPOS_FOR_DATE 11
#define OLED_YPOS_FOR_STATE 22
#define OLED_YPOS_FOR_LAN_IPADD 41
#define OLED_YPOS_FOR_AP_IPADD 50

#define NBR_OF_SYSTEM_ERROR 11

#define HTML_JSON_REDPLUGNAME "redPlug"
#define HTML_JSON_GREENPLUGNAME "greenPlug"
#define HTML_JSON_BLUEPLUGNAME "bluePlug"
#define HTML_JSON_YELLOWPLUGNAME "yellowPlug"

#define JSON_PARAMNAME_MODE "Mode"
#define MANUAL_MODE "Manuel"
#define TIMER_MODE "Minuterie"
#define CYCLIC_MODE "Cyclique"
#define HEBDO_MODE "Hebdomadaire"
#define CLONE_MODE "Clone"
#define JSON_PARAMNAME_STATE "State"
#define JSON_PARAMNAME_ONDURATION "dureeOn"
#define JSON_PARAMNAME_OFFDURATION "dureeOff"
#define JSON_PARAMNAME_STARTTIME "hDebut"
#define JSON_PARAMNAME_ENDTIME "hFin"
#define JSON_PARAMNAME_ONOFCOUNT "onOffCount"
#define JSON_PARAMNAME_NEXTSWITCH "nextTimeToSwitch"
#define JSON_PARAMNAME_PAUSE "Pause"
#define JSON_PARAMNAME_CLONEDPLUG "clonedPlug"

#define CLONEDPARAMNUMBER 8

#define HTMLREQ_SUNDAY "Dimanche" //it is allthough the value in html request
#define HTMLREQ_MONDAY "Lundi"
#define HTMLREQ_TUESDAY "Mardi"
#define HTMLREQ_WEDNESTDAY "Mercredi"
#define HTMLREQ_THURSDAY "Jeudi"
#define HTMLREQ_FRIDAY "Vendredi"
#define HTMLREQ_SATURDAY "Samedi"

#define HTML_EMPLACEMENT_NAME "emplacement"
#define HTML_SOFTAPIP_NAME "softAP_IP"
#define HTML_ALLLEDSONTIME_NAME "allLedsOnTime"
#define HTML_LEDLUM_NAME "ledsGlobalLuminosity"
#define HTML_POWERLEDECO_NAME "powerLedEconomyMode"
#define HTML_SOFTAPPORT_NAME "softAP_port"
#define HTML_STATIONIP_NAME "staIP"
#define HTML_HOSTNAME_NAME "hostName"
#define HTML_STAGATEWAY_NAME "staGateway"
#define HTML_MAXRETRY_NAME "STAmaxWifiConnectionRetry"
#define HTML_FIRSTBOOT_NAME "firstBoot"
#define HTML_REDPLUGNICK_NAME "redPlug_nickName"
#define HTML_GREENPLUGNICK_NAME "greenPlug_nickName"
#define HTML_BLUEPLUGNICK_NAME "bluePlug_nickName"
#define HTML_YELLOWPLUGNICK_NAME "yellowPlug_nickName"
#define HTML_STARTINAP_NAME "startInAPMode"
#define HTML_DHCPMODE_NAME "dhcp_mode"

#define PALCEHOLDERTAG "pH_"

#define TIME_STRING_SEPARATOR ":"

#define HTML_OFFDURATION_DEFAULT_VALUE "en minutes"
#define HTML_ENDTIME_DEFAULT_VALUE "HH:MM"


#define MANUEL_MODE_MAXOFFDURATION 300 //mn
#define TIMER_MODE_MAXONDURATION 300 //mn

#define NECESSARY_FILE_NBR 11

const String necessaryFileList[ NECESSARY_FILE_NBR ] ={
      "/index.html.gz"
    , "/config4.json"
    , "/config4copie1.json"
    , "/config4copie2.json"
    /** @todo [NECESSARY] only one of the 3 json file is necessary to run !!!*/
    , "/firstboot.htm"
    // and why no credentials file ? because on firstboot we creat it
    // and after ???
    /** @todo [NECESSARY to check]possible bug if credentials disapear - in case of change cred we check
if file exist and tag an fsErr if not */
    // , "config.html"
    , "/js/main.js"
    , "/js/plug.js.gz"
    , "/js/regExPatern.js"
    , "/js/table.js"
    // , "/js/jquery-3.3.1.min.js"
    // , "/js/bootstrap.min.js"
    , "/css/sidebar.css"
    , "/css/style.css"
    // , "/css/bootstrap.min.css"
    // , "/defConfig.json"
    //config_tag.htm ?
};


#endif

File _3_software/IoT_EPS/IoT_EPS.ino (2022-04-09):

/**
* @file IoT_EPS.ino
@mainpage
* @author J.SORANZO & Pierre
* @date 20 Oct 2018
* @copyright 2018 CC0
* @version 1.0
* @brief EPS Electrical Power Strip software

@tableofcontents

@section dependencies Lib dependencies
 - Utilisation de la bibliothèque ESP8266WiFi version 1.0
 - Utilisation de la bibliothèque ESP8266WebServer version 1.0 
 - Utilisation de la bibliothèque ArduinoJson version 5.13.2 
 - Utilisation de la bibliothèque Wire version 1.0
 - Utilisation de la bibliothèque RTClib version 1.2.0
 - Utilisation de la bibliothèque ESP8266mDNS prise dans le dossier \2.4.1\\libraries\\ESP8266mDNS (legacy)
 - Utilisation de la bibliothèque FastLED version 3.2.1
 - Utilisation de la bibliothèque nanoI2CIOExpLib version 3.1
 - Utilisation de la bibliothèque NTPClient version 3.1.0
 - Utilisation de la bibliothèque FastCRC-master version 1.31

@section wifi WIFIs connexions

If credentials are found in SPIFFS, IoT_EPS tries to connect about 20 times (time out = 10s).

If it can't reach WIFI network it switch to acces point mode.

In Access point mode default add is 192.168.95.42. Ssid and pass are those store in the SPIFFS credential.json

In station mode, when WIFI is not reachable, it switchs in softAP mode and WIFI LED fash shortly in 2s period.


 @bug Serial command < d > delete file with space in their name !

 @section How it works (this code)

 ??? In July 2020, I realised that I don't know how my code works in details. 
 
 By the usage of a lost
 of external lib like FastLED, ESP8266Webserver, RTClib... A lot of global variables, a very very 
 long main code here. I decide to refactor my code. A very hard task.

 ESP8266Webserver librairy documentation
*/

/**
 @page pageTodo Macro roadmap
 @tableofcontents
  doxygen todo list is not enought ! It is a good practice to highlight on certain ligne of code.
  Here I want to trace major features implementations.

 @li rewrite more OO of main code 
 @li test restore defConfig.json when firstBoot 
 @li see hardware.rst file
 
 @li power plugs current measurements
 @li manage summer and winter hour change
 @li if i say to you utf-8 ?!

 @li document FATAL errors color (see xlsx dedicate file)
 @li regarder pour recharger la page index lors d'un changement d'état par BP(pas forcément an mode AP)
 impossible this is the navigator to ask for a page and html refresh param is not a good idea !
 @li code, bugs and todo review : remove all unused commented code (cleanup)
*/

//Dev system objet juin 2020

#include "IoT_EPS.h"
#include "ESP8266FtpServer.h"
#include <ESP8266HTTPClient.h>
#include <ESP8266WebServer.h>
FtpServer ftpSrv;
CSystem sysIoteps;
CServerWeb webServeur;
CWifiLink wifilnk;

CJsonIotEps jsonData;



Adafruit_SSD1306 display(-1);
#if (SSD1306_LCDHEIGHT != 64)
#warning SSD1306_LCDHEIGHT
	
#error("Height incorrect, please fix Adafruit_SSD1306.h!");
#endif


CRtc rtc;

ConfigParam cParam; /**< @brief to hold the configuration parameters*/
Credential wifiCred;
CPowerPlug *plugs;

CRGB colorLeds[NUM_LEDS]; /**< @brief  not very satisfy for this globale ! It should be in the 
CpowerPlug class as a static member*/
//It is used with FastLED that it should be concidered as a common ressource
//It is not very important because cpowerplug instance never drive these LED !
//Yes near 342 line : colorLeds[i] = plugs[i].getColor();


CFlasherNanoExp wifiLed;
/** DONE 13/07/2019 [NECESSARY] check if it is possible to remove Flasher class (CNanoI2CIOExp used)
if yes remove Flasher.cpp and .h from source files */

CSwitchNano specialBp;
CNanoI2CIOExpander nanoioExp; //just for main pow led
WiFiUDP ntpUDP;

bool simpleManualMode = false;
int mainPowerSwitchState;
int mainPowerPrevState = 0;
CTempo allLeds;
bool restartTempoLed = false;

/* - [OPTION 1] see for add colorLEd array in the class CPowerPlug as a static member : NO */

/** DONE 22/01/2022 but not tested  
 
 - [OPTION for 1 and 2 plug strip] convert colorLeds array in dynamic version as for plugs array */




void setup(){
    DEBUGPORT.begin(DEBUGSPEED);
    DEFDPROMPT("setUp") // define dPrompt String

    display.begin(SSD1306_SWITCHCAPVCC, OLED_I2C_ADD );
    display.clearDisplay();

    // int timeZone = OFFSET_HEURE;
    String buildInfo =  String(__DATE__) + " @ " + String(__TIME__);

    sysIoteps.init( ntpUDP, &sysStatus, &SPIFFS, &cParam, necessaryFileList, NECESSARY_FILE_NBR
                    , buildInfo, &WiFi, &nanoioExp, &display, &jsonData );

    DSPL( dPrompt + F("Check json integrity after System init "));
    jsonData.printFileIntegrity();

    FastLED.addLeds<WS2801, DATA_PIN, CLOCK_PIN, RGB>(colorLeds, NUM_LEDS);
    FastLED.setBrightness( DEFAULT_LED_LUMINOSITY ); //default value for error display
    // Prepartion see todo : clear all led at the beginning of setup() in Bug_TodoList.rst
    // for ( int i = 0; i < NBRPLUGS ; i++ ) colorLeds[i] = CRGB::Black;
    // FastLED.show();
    // wifiLed.low();
    
    ftpSrv.begin("esp8266","esp8266");
    
	SerialCommand::init();

    /////////////////////////////////////////////////////////////////////////////
    // Watchdog check                                                          //
    ///////////////////////////////////////////////////////////////////////////// 
    watchdog.begin();
    DSPL( dPrompt + F("watchdog test ") );
    sysStatus.watchdogErr.err( !watchdog.test() );
    if ( !sysStatus.watchdogErr.isErr() ){
        DSPL( "watchdog OK"); //normaly if error we did not reach
        //this point unless _forceSystemStartOnFatalError is true for debug
        watchdog.setTimeout( cParam.getSTAMaxRetries() );
        watchdog.setRefreshPeriod( cParam.getSTAMaxRetries()/3 );  
        DSPL( dPrompt + F("watchdog set to ") + String( cParam.getSTAMaxRetries() ) + F("s.") );
        //oled message
        display.println("* watchdog ok");
        display.display();
    } else {
        DSPL( dPrompt + F("watchdog is not set due to errors."));
        display.println("* watchdog error");
        display.display();
    }

    /////////////////////////////////////////////////////////////////////////////
    //     Main power first check                                              //
    /////////////////////////////////////////////////////////////////////////////    
    pinMode( MAINSWITCHPIN, INPUT_PULLUP);
    nanoioExp.digitalWrite( MAINPOWLED, 0);
    nanoioExp.pinMode( MAINPOWLED, OUTPUT ); 
    mainPowerSwitchState = !digitalRead( MAINSWITCHPIN ); //open circuit = plug OFF
    webServeur.setMPSstVar( mainPowerSwitchState );    
    
    nanoioExp.digitalWrite( MAINPOWLED, mainPowerSwitchState );
    DSPL( dPrompt + "Main power state : " +  ( mainPowerSwitchState?"ON":"OFF") );
    specialBp.begin( SPECIALBP, 20, INPUT_PULLUP );
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

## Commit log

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2018-10-27 suppression du dossier IoT_EPS de la racine de 'project' suite pb gestion des branch
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2018-10-27 affichage de l'heure du DS3231 dans une page html en dur dans le code ToDO : lire cette page sur SPIFFS et remplacer un texte genre afficher_heure_ici par l'heure avant de l'envoyer
2018-11-03 Integration de l'exemple FSBrowser pour la gestion des css et autres fichiers associés à la page html, ajout du fichier .epgz Pencil pour le design des interface graphiques
2018-11-03 Gestion du mode client. Connection à volab_iot ok. Edition directe des fichier possible grâce à l'intégration des fonctions de l'exemple FSBrowser.
2018-11-10 un poil de doc pour le choix des relais et la définition des modes de fonctionnement
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2018-11-10 Création de la classe CPowerPlug avec variable et fonction static. Compilé mias pas testée en cours d'écriture. Il manque notament les méthodes pour gérer le temps.
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2018-11-17 réception formulaire ok - todo: mettre la fonction dans la class power plug
2018-11-17 IoT_EPS.js: Creation de sous fonction pour le remplissage du résumer des prises
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2018-11-28 plugs sous forme de tableau + doc + premières commande de relais
2018-12-01 ADD: IoT_EPS2.js + simplification de index.html le temps la mise en place
2018-12-02 add display param in handlePlugOnOff + pise en charge des 3 autres plugs et de leur initialisation
    [8mmLedBob v1.stl, 8relBob.stl]
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2018-12-08 Passage au fichier config3.json (testé et fonctionnel) sur le chemin de la lecture des parametre de chaque plug
2018-12-08 CPowerPlug::readJson() en cours de mise au point. Lectures Ok. Rest à mettre les string lues sous forme de variables membres
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2018-12-09 page écriture correcte dans config3.json ToDO : séparer les paramètres réseau de config3.json
    [IoT_EPS.ino, configParam.cpp, cpowerplug.cpp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]
2018-12-12 en chemin vers le décodage des actions. Mode manuel en cous dans la classe CPowerPlug
2018-12-15 Index.html: mise en correspodence des noms retournes par les formulaires par rapport a config3.json
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2018-12-19 Implementation du compter onOff dans le json. Correction bug bp acquit au retouren mode manuel.
    [cpowerplug.cpp, cpowerplug.h]
2018-12-22 work around nexttime to switch and static function to display a unixtime into a humen readable form
2018-12-22 Inex.html: MAJ de la syntax des boutons radios ; IoT_EPS2: gestion de l'action sur les checkbox dans le mode Hebdo
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2018-12-26 add SerialCommands capability and LED Flasher class to display softAP mode when wifi is not reachable.
2018-12-28 some little corrections : yellow plug bp doesn't work @ start up (call readFromJson !)
    [IoT_EPS.ino, cpowerplug.cpp]
2018-12-30 Index.html: suppression des ID (remplaces par des class); IoT_EPS.js: creation de la class Plug + preparation des modes pour intégration dans la class
2018-12-30 hebdo mode WIP write to JSON ok, next time to switch computation ok, to do : at time
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2019-01-05 Integration de 'Submit' dans C_Plug + Creation de 'interface_Web.rst' et de 'mylog.js'
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2019-01-22 nanoI2C integre et fonctionnel .test() ok alim 5V cablée. ToDo : remplacer le composant MPC...
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2019-02-01 main.js: correction d'un bug sur les boutons 'pause'
2019-02-02 index.html: redéfinition du mode clone ; main.js+plug.js: dans le mode clone, suppression de la prise en court d'utilisation
2019-02-03 main+plug: Mode Clone, mise en place de l'action au click sur les selecteurs
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2019-03-02 BP double click action replaced by a special BP. Double clicks are not sure at all. + implementation of html pause request
    [IoT_EPS.ino, bouton.cpp, cpowerplug.cpp]
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2019-03-09 bug correction bplongclic write state in json
    [IoT_EPS.ino, cpowerplug.cpp]
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2019-03-13 index.html: Correction de la syntaxe pour compatibilite avec le XHTML
2019-03-20 Led main power ok + start error missing credential handling
    [IoT_EPS.ino, SerialCommand.cpp, cpowerplug.h]
2019-03-22 main code reorganisation and a steo to better error handling
    [IoT_EPS.ino, SerialCommand.cpp, configParam.cpp]
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2019-03-23 ftp server + BP wakeup + an other step to error handling
    [IoT_EPS.ino, SerialCommand.cpp, configParam.cpp]
2019-03-29 integration: work in progress, bug with cr/LF in json corrected, bug onTime = 0 or empty corrected
    [configParam.cpp, cpowerplug.cpp]
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2019-03-30 switch off ALL led with main power switch
    [testAndErrorHandling.xlsx]
2019-04-12 large modification, config4.json intro. Research about softAP mode.
    [IOTESP_PowerPlugv1.kicad_pcb, IOTESP_PowerPlugv1.sch, testAndErrorHandling.xlsx]
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2019-04-19 fisrtBoot : work in progress, AP mode ok. ToDo Station mode + error handling
    [IoT_EPS.ino, SerialCommand.cpp, configParam.cpp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]
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2019-04-20 firstboot procedure OK, todo a complete test pass. i2c_recovery() active but just one time. Do 2 or 3 try before jump to fatal error mode.
    [IoT_EPS.ino, SerialCommand.cpp, configParam.cpp]
2019-04-24 CSysStatus class introduction + power up debug !!!!!!!!!!!!!!!!!!!!!!!!!!!!!!!!!
    [testAndErrorHandling.xlsx]
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2019-05-18 sysStatus.fsErr implemented
    [testAndErrorHandling.xlsx]
2019-05-27 WIP to error handling. Stanby due to change BP and relays pining. Special branch : relayChange
    [testAndErrorHandling.xlsx]
2019-05-29 WIP on the road of error Handling...
    [testAndErrorHandling.xlsx]
2019-06-01 A very important improvement of error handling, not completely finished but well advanced. Soma adds to config4.json
    [testAndErrorHandling.xlsx]
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2019-06-21 CBIT of ntp server + necessary files...
    [testAndErrorHandling.xlsx]
2019-06-28 internet test response : WIP a good solution find, needs to be correctly implemented.
    [IoT_EPS.ino]
2019-06-29 Internet health check ok
    [testAndErrorHandling.xlsx]
2019-07-23 watchdog implementation start. Compiled but not tested and a lot of work to do...
    [testAndErrorHandling.xlsx]
2019-07-27 ATtiny85 I2C WatchDog integrated + some code cleanup
    [testAndErrorHandling.xlsx]
2019-07-27 correct ntpErr line 623 .ino
    [IoT_EPS.ino]
2019-07-27 All is working ! apparently. It is time to merge.
    [testAndErrorHandling.xlsx]
2019-07-27 just Execel little correction
    [testAndErrorHandling.xlsx]
2020-06-13 Apres 3 mois d'arret COVID-19
    [BOM_IoT Electrical Power Strip_20200215230232.csv, PCB_2020-02-01 19_42_03.dxf, gabaritBPGrossLed.stl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]
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2020-06-30 Tentative d'assenaisement
    [testAndErrorHandling.xlsx]
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2020-07-18 start of cleaning CRtc and DS3231 rtc instances
    [serverListFunctions.xlsx, serveurListFunction_variablesexternes.xlsx]
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2020-08-29 /newCred ok + correction bug if "nf"
    [CServerWeb.cpp]
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2020-09-30 A priori bug corrigé
    [IoT_EPS.ino, csystem.cpp]
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2021-04-11 Grosse update après bien longtemps
    [BOM_IoT Electrical Power Strip_20200215230232.xlsx]
2021-06-13 find a bug on ChangeCred in html method POST and in CServerWeb method get
    [CServerWeb.cpp]
2021-06-13 Correction bug ChangeCred method POST / GET
    [CServerWeb.cpp]
2021-06-19 Somme Doxygen corrections !
    [CServerWeb.cpp]
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2021-06-26 warning cleaning + oled display error implementation (not complete).
    [configParam.cpp, csystem.cpp]
2021-06-27 Bug: SoftAP fails after oled creation. Not directly linked to oled features. First code reading without success. Need to run some debug session with hardware.
    [configParam.cpp]
2021-06-30 A lot of files modified but bug, I didn't find the bug! I put IDE in Wifi debug mode and the system return to a normal behavior !
    [csystem.cpp]
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2021-08-07 Correction de if ( _oledCptErrToDisplay = 0 )
    [csystem.cpp]
2021-08-14 wip read json plugs param (wrong branch)
    [IoT_EPS.ino, cpowerplug.h, csystem.cpp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]
2021-08-21 bug de la fonction cfgpage (nécessaire pour mes test)
    [configParam.cpp, jsonIotEps.cpp]
2021-09-01 Toujours à la recherche du bug
    [configParam.cpp]
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2021-12-12 bug display wd corrected but new bug see softdev.rst
    [IoT_EPS.ino, SerialCommand.cpp, csystem.cpp]
2021-12-18 oled display error bug corrected
    [IoT_EPS.ino, csystem.cpp]
2021-12-29 bug json plugs not writed corrected but not tested
    [cpowerplug.cpp, jsonIotEps.cpp]
2022-01-08 code cleaning and lots of inducted bugs corrections
    [CServerWeb.cpp, cpowerplug.cpp, jsonIotEps.cpp]
2022-01-08 correction of the for loop to store days but not tested + list test doc introducted
    [cpowerplug.cpp, jsonIotEps.cpp]
2022-01-08 bug restaure physical state correction
    [cpowerplug.cpp, jsonIotEps.cpp]
2022-01-15 on/off count bug corrected
    [IoT_EPS.ino, cpowerplug.cpp, jsonIotEps.cpp]
2022-01-15 find bug bp2 and 3 permutted on pcb reroute to correct
2022-01-22 documentation correction 4 doc errors like pNanoioExp...
    [csystem.cpp]
2022-02-06 command to rise error is already terminated see SerialCommand.cpp
    [IoT_EPS.ino, SerialCommand.cpp]
2022-04-09 3D printLogo design
    [logo001-Cut.stl, logo001.FCStd]
2022-04-09 preparation to correct bug dureeon dureeof not reset
    [logo002.FCStd, logo002.stl, logoFace.FCStd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]
2022-04-09 bug on main power switch corrected
    [IoT_EPS.ino]
2022-04-30 on the road to new pcb
    [BOM_PCB_2020-02-01 19_42_03 copy_2022-04-18.csv, BoM_220418_1816.xlsx, logo001-Cut.stl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]
2022-05-28 how to prog bin file for watchdog + test pcb v2
    [logo003-Fusion006.stl, logo004-final.stl, logo004.FCStd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]
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2022-08-17 Python tool to track untimely switching is OK and run on protype
    [config4NonMinifier220727_2313.txt]
2022-08-20 filecompare gz work.xls
    [fileListe220820_2144.xlsx]
2022-09-03 webrework work in process : cdn file move locally : what size ?
    [fileListe220820_2144.xlsx]
2022-12-28 lots of documentation works
    [fileListe220820_2144.xlsx]
